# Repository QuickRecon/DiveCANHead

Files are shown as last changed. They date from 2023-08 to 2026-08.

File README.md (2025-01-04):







# Current State
Revision 2.4 has been produced and is undergoing wet testing, current development work is focused on enhansing the automated testing (currently focusing on adding testing of various power states), as well as validating solenoid driver performance.

Constructive criticism, suggestions, and pull requests are always welcome.

Documentation for building and flashing firmware can be found under /Documentation/

# Goals
The goals of this project are pretty simple:
- Have a reliable PPO2 monitor that can handle both digital and analog PPO2 cell inputs
- Be extendable for future CCR technology developments
- Work with existing computers/handsets, accomplished via DiveCAN compatibility.

# DiveCAN
DiveCAN is Shearwaters proprietary digital rebreather communications bus, more details about the electrical and protocol layers are discussed here: https://github.com/QuickRecon/DiveCAN

# The platform
The platform is based on an STM32 processor, connected to a pair of dual differential input ADCs for analog sensing. Digital cells are handled via the 3 UART ports on the STM32.
Power is done in a dual rail configuration, with a critical VCC rail running the main processor, CAN transceiver, and other necessary basic components. This is supplemented with a second VBUS rail used for running external peripherals like solid state sensors.

The board has a battery onboard which can provide full functionality, and can also be provided with power from the CAN bus (1.8-5.5v). The VCC rail will prioritize CAN power and revert to battery if that is unavailable, the VBUS rail can have its power source controlled via the firmware. The VBUS rail can also be fed onto the CAN bus, allowing the board to act as a CAN power source, supplementing the bus power of the shearwater (which tops out at 16 mA).

Fundamentally the hardware is an IO board, bridging generic cells, sensors, and other peripherals to the DiveCAN bus. To do this it provides the following:
- 3 uart ports
- 4 analog differential inputs (3 terminated for O2 cells, 1 unterminated differential input)
- the solenoid output (12v/6v selectable, max 1.3A switching current (LMR62014 boost converter))
- general DC out (3.3v, 227mA current limit)
- the CAN bus itself
- 2 DACs, configured for "cell like" outputs
- 2 GPIOs

Currently there are sensor drivers for analog oxygen cells and digital oxygen cells. Future development.

The board is currently emulating a DiveCAN SOLO board, specifically using data captured from a JJ head, and testing with a JJ Petrel 3. This will almost certainly work with any DiveCAN shearwater expecting the same general architecture (such as the Choptima handset, or NERD/DiveCAN HUD). It will also probably work (may require some small code changes around the IDs used) with rEvo and ISC shearwaters, but that hasn't been validated.

The current form factor is driven by the ease of manufacturing and RnD on the design rather than being fully optimized for widespread implementation. For example the battery has been put on the PCB because that is the easiest place for it to be secured. Wires and connectors are places for assembly defects and failures so I like to avoid them where possible. Having the battery on the PCB means that if the PCB is secure then the battery is secure, and the PCB has mounting holes, which makes securing it easier.

The long thin aspect ratio was driven by the ease of manufacturing of housings, the current form fits into a simple tube, with cables running out each end. One for CCR IO (cells, solenoid, etc) and DiveCAN out the other.

# Roadmap
### Current software jobs
These are required before the firmware can be considered ready for any kind of test diving:
- Fix composition of errors with battery value (currently battery voltage stops updating on other errors)
- Only sample battery voltage while solenoid firing if solenoid enabled

### Additional testing needs
- More automated testing of each module, regression testing and behavior verification.
- Datalog captures from rEvos
- Verification of compatibility with monitor bus devices, ISC.

### Future Hardware Improvements (desired on next board version)
- External watchdog
- CAN IC with lower power

### Future Software Improvements
- Battery reading and power switching 
- Make DiveCAN multi-device safe so we can make multiple menu rows
- Predive "app", show loop pressure and such

### Prospective future developments
- Additional form-factors, shorter, more compact.
- DAC output to analog cell port, allow use of analog backup monitor with digital cells
- Break off battery to separate system, can be isolated physically for flood tolerance.

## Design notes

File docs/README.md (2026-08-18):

# DiveCANHead Documentation Index

This directory contains detailed subsystem documentation for the DiveCANHead firmware project.

## Quick Reference

| Document | Description |
|---|---|
| [UDS_PROTOCOL.md](UDS_PROTOCOL.md) | UDS diagnostic services, session model, NRCs |
| [ISOTP_TRANSPORT.md](ISOTP_TRANSPORT.md) | ISO-TP framing, state machine, TX queue |
| [DATA_IDENTIFIERS.md](DATA_IDENTIFIERS.md) | Complete DID reference (state, cells, settings) |
| [FREERTOS_PATTERNS.md](FREERTOS_PATTERNS.md) | Cooperative scheduling, queues, static allocation |
| [OXYGEN_SENSORS.md](OXYGEN_SENSORS.md) | Sensor drivers, voting algorithm, calibration |
| [CONFIGURATION_SYSTEM.md](CONFIGURATION_SYSTEM.md) | Configuration_t bitfield, persistence |
| [TESTING_ARCHITECTURE.md](TESTING_ARCHITECTURE.md) | DiveCANpy, pytest fixtures, HWShim |
| [HIL_GITHUB_ACTIONS.md](HIL_GITHUB_ACTIONS.md) | Self-hosted GitHub Actions gate for the out-of-tree HIL bench |
| [DIVECAN_BT.md](DIVECAN_BT.md) | Browser JS client, SLIP, UDSClient |
| [TELEMETRY_VIEWER.md](TELEMETRY_VIEWER.md) | Flash-log telemetry viewer + `telemetry_log.py` CLI |
| [FLASHING_FIRMWARE.md](FLASHING_FIRMWARE.md) | SWD flashing via STM32CubeProgrammer |

## External References

- [DiveCAN Protocol](https://github.com/QuickRecon/DiveCAN) - Base protocol documentation
- [ISO 14229 (UDS)](https://www.iso.org/standard/72439.html) - Unified Diagnostic Services specification
- [ISO 15765-2 (ISO-TP)](https://www.iso.org/standard/66574.html) - Transport protocol specification

## Source File Mapping

| Subsystem | Key Source Files |
|---|---|
| UDS | `STM32/Core/Src/DiveCAN/uds/uds.c`, `uds.h` |
| ISO-TP | `STM32/Core/Src/DiveCAN/uds/isotp.c`, `isotp_tx_queue.c` |
| DIDs | `uds_state_did.h`, `uds_settings.c`, `DiveCAN_bt/src/uds/constants.js` |
| FreeRTOS | `STM32/Core/Inc/FreeRTOSConfig.h`, `main.c` |
| Sensors | `Sensors/OxygenCell.c`, `AnalogOxygen.c`, `DiveO2.c`, `OxygenScientific.c` |
| Config | `configuration.h`, `configuration.c`, `ConfigFormat.md` |
| Testing | `DiveCANpy/*.py`, `HW Testing/Tests/*.py` |
| BT Client | `DiveCAN_bt/src/**/*.js` |

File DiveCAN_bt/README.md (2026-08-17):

# DiveCAN Protocol Stack for Browser

A browser-based JavaScript API for communicating with DiveCAN-compatible devices via Bluetooth Low Energy (BLE). Implements the full protocol stack: BLE → SLIP → DiveCAN → ISO-TP → UDS.

## Features

- **Full Protocol Stack**: Complete implementation of BLE-SLIP-ISO-TP-UDS layers
- **Web Bluetooth API**: Native browser support (Chrome, Edge, Opera)
- **Device Discovery**: Scan and connect to Petrel 3 Bluetooth bridge
- **UDS Diagnostics**: Session control, read/write data identifiers, memory transfer
- **Test UI**: Comprehensive web-based testing interface
- **Modular Architecture**: Clean layer separation for easy testing and extension
- **Event-Driven**: Real-time packet inspection and progress tracking

## Browser Support

- ✅ Chrome 56+
- ✅ Edge 79+
- ✅ Opera 43+
- ❌ Firefox (no Web Bluetooth support)
- ❌ Safari (no Web Bluetooth support)

**Requirements:**
- HTTPS (required for Web Bluetooth API)
- User gesture to initiate connection (button click)

## Quick Start

### 1. Start a local HTTPS server

Since Web Bluetooth requires HTTPS, you need to serve the files over HTTPS:

```bash
cd DiveCAN_bt
npm run dev
```

This starts a simple HTTP server on port 8000. For HTTPS, you'll need a local certificate or use a service like ngrok.

### 2. Open the test UI

Navigate to:
```
http://localhost:8000/examples/test-ui.html
```

### 3. Connect to your Petrel 3

1. Click "Scan & Connect"
2. Select your Petrel 3 from the browser's device picker
3. Wait for connection to establish

### 4. Test UDS operations

- Switch diagnostic sessions
- Read firmware version
- Read/write configuration
- Upload memory blocks

## API Usage

### Basic Example

```javascript
import { DiveCANProtocolStack, DeviceManager } from './src/index.js';

// Create device manager
const deviceManager = new DeviceManager();

// Scan for devices
const devices = await deviceManager.scan();
const petrel = devices[0].device;

// Create protocol stack
const stack = new DiveCANProtocolStack();

// Connect
await stack.connect(petrel);

// Read firmware version
const version = await stack.readFirmwareVersion();
console.log('Firmware:', version);

// Disconnect
await stack.disconnect();
```

### Advanced Usage

```javascript
import {
  DiveCANProtocolStack,
  UDSConstants
} from './src/index.js';

const stack = new DiveCANProtocolStack();

// Set up event handlers
stack.on('connected', () => console.log('Connected'));
stack.on('data', ({ layer, data }) => console.log(`RX [${layer}]:`, data));
stack.on('error', (error) => console.error('Error:', error));

// Connect to device
await stack.connect(device);

// Read device settings (individual settings under 0x9xxx)
const settings = await stack.uds.enumerateSettings();
console.log('Settings:', settings);

// Stage + activate a firmware image (see docs/DIVECAN_BT.md)
await stack.ota.enterProgrammingSession();
await stack.ota.stageImage(imageBytes, { onProgress: (d, t) => {} });
await stack.ota.activate();

// Download a flash log
const { raw } = await stack.logs.downloadLog({ selector: (d) => d.selectLatestBoot(0) });

// Download every telemetry record still retained in one walk-free stream.
const { raw: allRaw, records } = await stack.logs.downloadAll({ stream: 0 });
```

### CANable over Web Serial

Chromium can talk directly to a CANable when it is running `slcan`/Lawicel
serial firmware (the candleLight/gs_usb firmware is not a serial protocol and
cannot be used through Web Serial). The adapter is configured for DiveCAN's
125 kbit/s bus by default (`S4`). This direct path performs DiveCAN's padded
ISO-TP variant in the browser; it does not use SLIP or the Petrel bridge.

```javascript
import { CanableProtocolStack } from './src/index.js';

// Defaults: Web Serial line-coding value 115200, CAN 125 kbit/s, dialog client 0xFE,
// broadcast-log client 0xFF, head 0x04.
const stack = new CanableProtocolStack();

// The diagnostics page exposes 115200/1M/2M/3M for benchmarking. It is also
// configurable here. On a native USB CDC ACM CANable this value may be ignored
// by the device rather than controlling a physical UART.
const benchmarkStack = new CanableProtocolStack({ canable: { baudRate: 1000000 } });

stack.on('logMessage', message => console.log('HEAD:', message));
stack.on('error', error => console.error(error));

// Must be called from a user gesture (for example, a button click).
await stack.connect(); // opens Chromium's serial-port chooser

const imageBytes = new Uint8Array(await (await fetch('./firmware.bin')).arrayBuffer());
const result = await stack.ota.updateFirmware(imageBytes, {
  onPhase: phase => console.log('OTA phase:', phase),
  onProgress: (done, total) => console.log(`${done}/${total}`)
});
console.log(result);
```

Direct USB-CAN log downloads request the head's full 253-byte response body;
the 61-byte limit remains the default only for the Petrel BLE bridge. For a
large/full-ring browser download, stream into the Origin Private File System
instead of accumulating the log in the JavaScript heap:

```javascript
import { OPFSLogDownloadStore } from './src/index.js';

const selection = { stream: 0, mode: 'allBoots', id: null };
const resumeKey = JSON.stringify(selection);
const store = await OPFSLogDownloadStore.create({ selection, resumeKey });

const result = await stack.logs.downloadAllResumable({
  stream: 0,
  store,
  resumeKey,
  expectedBytes: 48 * 1024 * 1024,
  onProgress: ({
    saved, transferred, replayed, resumeBytes, rateKiBps, averageKiBps, etaSeconds
  }) => {
    console.log({
      saved, transferred, replayed, resumeBytes,
      rateKiBps, averageKiBps, etaSeconds
    });
  },
  onRetry: ({ nextAttempt, delayMs, partialBytes }) => {
    console.log(`retry ${nextAttempt} in ${delayMs} ms; ${partialBytes} bytes saved`);
  }
});
console.log(await result.store.getFile());
console.log(result.metrics); // final elapsed time, smoothed rate, average rate
```

After a transient failure the selector restarts at byte zero (the protocol has
no offset request). The client verifies the retransmitted bytes against the
saved disk prefix. If a full ring advanced during a head reboot, it can resume
only after finding a unique overlap and verifying continuity through the saved
boundary. Missing, ambiguous, or changed overlap aborts with
`LOG_RESUME_MISMATCH`; the partial file is left untouched for inspection or
export. The diagnostics page lists these complete and partial OPFS artifacts
and provides explicit Inspect, Resume, and Export controls. It displays the
smoothed transfer rate in KiB/s and, for select-all downloads, an ETA to the
48 MiB telemetry or 8 MiB text ring capacity. The final average rate and the
selected Web Serial baud value are retained in the artifact metadata and the
diagnostics message log for comparison between benchmark runs.

Web Serial requires a secure context; `http://localhost` is accepted for local
development. Disconnect any other active CAN controller/diagnostic client
during OTA so only one ISO-TP dialog owns the head.

Direct USB-CAN deliberately uses two independent ISO-TP receive contexts:
addressed OTA/DID replies target client `0xFE`, while pushed logs remain on
`0xFF`. Interleaved log frames therefore cannot alter the dialog reassembly
sequence or complete a pending UDS request. BLE continues to use `0xFF` for
both because the Bluetooth bridge exposes only that single client address.

The CANable stack also watches for the handset's controller `BUS_ID` ping
(`0x0D000001`). If none is observed for 2.5 seconds it supplies the same ping
once per second, allowing a freshly swapped image to pass its handset-liveness
POST when the USB adapter is the only bus peer. Emulation stops immediately
when a real handset ping appears. Set `handsetEmulation: false` to disable it,
or override `handsetMissingAfterMs` / `handsetPingIntervalMs` if required.

### Direct Layer Access

```javascript
// Access individual protocol layers
const ble = stack.ble;           // BLEConnection
const slip = stack.slip;         // SLIPCodec
const divecan = stack.divecan;   // DiveCANFramer
const transport = stack.transport; // DirectTransport (Petrel handles ISO-TP)
const uds = stack.uds;           // UDSClient
const ota = stack.ota;           // OTAManager
const logs = stack.logs;         // LogDownloader

// Direct UDS operations
await uds.enterSession(UDSConstants.UDS_SESSION_PROGRAMMING); // 0x10 0x02
const data = await uds.readDataByIdentifier(0xF000);
await uds.writeDataByIdentifier(0xF240, [130]); // setpoint 1.30 bar
```

## Architecture

### Protocol Layers

```
┌─────────────────────────────────────────────┐
│           Application Layer                  │
│     (UI, Device Manager, Test Harness)       │
└─────────────────────────────────────────────┘
                     ↕
┌─────────────────────────────────────────────┐
│           UDS Service Layer                  │
│  (Session Control, Read/Write, Upload/Down)  │
└─────────────────────────────────────────────┘
                     ↕
┌─────────────────────────────────────────────┐
│         ISO-TP Transport Layer               │
│    (SF/FF/CF/FC Framing, Reassembly)        │
└─────────────────────────────────────────────┘
                     ↕
┌─────────────────────────────────────────────┐
│         DiveCAN Datagram Layer               │
│     (Source/Target Addressing, Framing)      │
└─────────────────────────────────────────────┘
                     ↕
┌─────────────────────────────────────────────┐
│           SLIP Encoding Layer                │
│      (Encoding/Decoding, Escaping)           │
└─────────────────────────────────────────────┘
                     ↕
┌─────────────────────────────────────────────┐
│         BLE Communication Layer              │
│   (Web Bluetooth API, Connection Mgmt)       │
└─────────────────────────────────────────────┘
```

### File Structure

```
DiveCAN_bt/
├── src/
│   ├── ble/
│   │   └── BLEConnection.js         # Web Bluetooth interface
│   ├── slip/
│   │   └── SLIPCodec.js             # SLIP encoding/decoding
│   ├── divecan/
│   │   ├── DiveCANFramer.js         # DiveCAN datagram layer
│   │   └── constants.js
│   ├── isotp/
│   │   ├── ISOTPTransport.js        # ISO-TP transport layer
│   │   ├── ISOTPStateMachine.js     # State machine
│   │   └── constants.js
│   ├── uds/
│   │   ├── UDSClient.js             # UDS service client
│   │   └── constants.js
│   ├── errors/
│   │   └── ProtocolErrors.js        # Error classes
│   ├── utils/
│   │   ├── ByteUtils.js             # Byte array utilities
│   │   ├── Logger.js                # Logging
│   │   └── Timeout.js               # Timeout management
│   ├── DiveCANProtocolStack.js      # Main coordinator
│   ├── DeviceManager.js             # Device discovery
│   └── index.js                     # Public API
├── examples/
│   └── test-ui.html                 # Test interface
├── package.json
└── README.md
```

## Protocol Details

### BLE Layer
- **Service UUID**: `fe25c237-0ece-443c-b0aa-e02033e7029d`
- **Characteristic UUID**: `27b7570b-359e-45a3-91bb-cf7e70049bd2`
- **Packet Header**: `[0x01, 0x00]` prepended to all packets
- **MTU**: 20 bytes (default)

### SLIP Layer
- **RFC 1055** encoding
- **END byte**: `0xC0`
- **ESC byte**: `0xDB`
- Escape sequences: `0xC0 → 0xDB 0xDC`, `0xDB → 0xDB 0xDD`

### DiveCAN Layer
- **Datagram format**: `[source, target, len_low, len_high, payload...]`
- **Source**: `0xFF` (bluetooth client)
- **Target**: `0x80` (controller/Petrel bluetooth side of bridge)

### ISO-TP Layer
- **ISO 15765-2** with extended addressing
- **Single Frame (SF)**: ≤6 bytes, `[TA, 0x0N, payload...]`
- **First Frame (FF)**: >6 bytes, `[TA, 0x1N, len_low, first 5 bytes...]`
- **Consecutive Frame (CF)**: `[TA, 0x2N, 6 bytes...]`
- **Flow Control (FC)**: `[TA, 0x30, BS, STmin]`
- **Timeouts**: N_Bs=1000ms, N_Cr=1000ms

### UDS Layer
- **ISO 14229-1** diagnostic services
- **Service 0x10**: DiagnosticSessionControl
- **Service 0x10**: DiagnosticSessionControl (default / programming)
- **Service 0x22**: ReadDataByIdentifier
- **Service 0x2E**: WriteDataByIdentifier
- **Service 0x31**: RoutineControl (OTA activate, log selectors)
- **Service 0x34**: RequestDownload (OTA + log download)
- **Service 0x36**: TransferData
- **Service 0x37**: RequestTransferExit

### Data Identifiers (DIDs)
- **0xF000**: Firmware version (string)
- **0xF001**: Hardware version (byte)
- **0xF002**: Variant name (string)
- **0xF003**: Serial number (raw MCU UID)
- **0xF270–0xF279**: MCUBoot status / OTA management
- **0xF280–0xF284**: Flash-log stats / selector / management
- **0x9100**: Setting count
- **0x9110+i**: Setting info for setting i
- **0x9130+i**: Setting value for setting i
- **0x9350+i**: Save setting i to flash

## Events

The `DiveCANProtocolStack` emits the following events:

- **`connected`**: Connection established
- **`disconnected`**: Connection closed
- **`data`**: Data received (with layer info)
- **`frame`**: Frame sent (with layer info)
- **`error`**: Protocol error occurred
- **`progress`**: Progress update (current, total, percent)
- **`udsResponse`**: UDS positive response
- **`udsNegativeResponse`**: UDS negative response (with NRC)

## Error Handling

```javascript
try {
  const version = await stack.readFirmwareVersion();
} catch (error) {
  if (error instanceof UDSError) {
    console.error('UDS Error:', error.getNRCDescription());
    console.error('NRC Code:', error.nrc);
  } else if (error instanceof ISOTPError) {
    console.error('ISO-TP Error:', error.message);
  } else if (error instanceof BLEError) {
    console.error('BLE Error:', error.message);
  }

  // Full error chain
  console.error('Full error:', error.getFullError());
}
```

## Development

### Running the Test UI

```bash
# Start HTTP server
npm run dev

# Open browser to http://localhost:8000/examples/test-ui.html
```

### Debugging

Set logger level in your code:

```javascript
import { Logger } from './src/utils/Logger.js';

// Set global log level
Logger.prototype.setLevel('debug');

// Or per-layer
stack.ble.logger.setLevel('debug');
stack.isotp.logger.setLevel('debug');
stack.uds.logger.setLevel('debug');
```

## Limitations

- **Web Bluetooth API**: Only available in Chromium-based browsers
- **HTTPS Required**: Web Bluetooth API requires secure context
- **User Gesture**: Initial connection must be triggered by user action
- **MTU**: Limited to 20 bytes by default (can be negotiated higher)
- **No Background**: Connection drops when tab becomes inactive

## Troubleshooting

### "Web Bluetooth not available"
- Use Chrome, Edge, or Opera browser
- Ensure you're on HTTPS (or localhost)

### "Connection failed"
- Ensure Petrel 3 is powered on and advertising
- Check Bluetooth is enabled on your computer
- Try moving closer to the device

### "Request timeout"
- Device may not be responding
- Check DiveCAN device is functioning
- Try disconnecting and reconnecting

### "Negative response" errors
- **NRC 0x22**: Wrong session - switch to extended/programming session
- **NRC 0x13**: Incorrect message length - check data format
- **NRC 0x31**: Request out of range - invalid DID or address

## Future Enhancements

- Unit tests (Jest)
- TypeScript definitions
- Settings API (read/write via DIDs 0x9100+)
- Firmware download capability
- Log file retrieval
- Connection state persistence
- Multiple device management
- MTU negotiation
- Bundling (Rollup/Webpack)

## License

MIT

## Contributing

Contributions welcome! Please open an issue or pull request on GitHub.

## References

- **ISO 15765-2**: Road vehicles — Diagnostic communication over Controller Area Network (ISO-TP)
- **ISO 14229-1**: Road vehicles — Unified diagnostic services (UDS)
- **RFC 1055**: Serial Line Internet Protocol (SLIP)
- **Web Bluetooth API**: https://webbluetoothcg.github.io/web-bluetooth/

## Support

For issues and questions, please open an issue on GitHub.

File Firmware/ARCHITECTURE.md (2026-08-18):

# Architecture — DiveCAN Jr (Zephyr Port)

This document captures the design decisions made during the port from the FreeRTOS-based STM32 firmware to Zephyr RTOS, targeting the same STM32L431RCTx on the new Jr PCB.

## Motivations for Porting

- **Decouple application logic from driver logic** — FreeRTOS firmware had tight coupling between HAL calls and application code, making testing and hardware changes expensive.
- **MCUBoot / OTA** — Zephyr's native MCUBoot integration enables over-the-air firmware updates via UDS over CAN bus, reducing the barrier to deploying fixes.
- **Compile-time product variants** — Replace the runtime Configuration_t struct with Kconfig-based topology selection. Each product variant is a validated, tested firmware image. Invalid hardware configurations become unrepresentable.
- **No shared global state** — Replace the FreeRTOS peek-queue and global struct patterns with zbus pub/sub for fully decoupled inter-module communication.
- **Hardware-enforced safety** — Hardware timer deadman on solenoids, MPU stack guards, HW RNG-seeded stack canaries.

## Target Hardware

- **MCU**: STM32L431RCTx (Cortex-M4F, 256KB flash, 64KB RAM)
- **Clock**: 12MHz HSE, PLL to 80MHz SYSCLK
- **CAN**: DiveCAN @ 125 kbit/s (CAN1, PB8/PB9)
- **ADC**: Dual ADS1115 on I2C1 (0x48, 0x49) for oxygen cell voltage
- **UARTs**: 3x at 19200 baud for digital oxygen sensors
- **Flash**: Winbond W25Q512JV SPI NOR (64MB) replacing SD card — used for OTA secondary slot, scratch, factory image backup, NVS settings, and data logging
- **Console**: Segger RTT over ST-Link (no UART consumed)

## Flash Partitions

Internal flash (STM32L431RC, 256 KB) is dedicated to MCUBoot + the
primary application slot. All operational storage (secondary slot,
swap scratch, factory image backup, NVS settings, future log space)
lives on the external W25Q512JV NOR.

### Internal flash

| Region | Node | Label | Range | Size |
|---|---|---|---|---|
| Bootloader | `boot_partition` | `mcuboot` | 0x00000000 – 0x00009000 | 36 KB |
| Primary slot | `slot0_partition` | `image-0` | 0x00009000 – 0x00040000 | 220 KB |

MCUBoot is built with `BOOT_SIGNATURE_TYPE_NONE` (SHA-256 integrity
only, no asymmetric crypto). The sysbuild MCUBoot overlay disables
application-only peripherals; the image is approximately 32 KB in a 36 KB
partition. Monitor this narrow margin after Zephyr/MCUBoot upgrades.

### External NOR (W25Q512JV, 64 MB)

| Region | Node | Label | Range | Size |
|---|---|---|---|---|
| Secondary slot | `slot1_partition` | `image-1` | 0x00000000 – 0x00037000 | 220 KB |
| Swap scratch | `scratch_partition` | `image-scratch` | 0x00037000 – 0x00047000 | 64 KB |
| Factory image backup | `factory_partition` | `factory-image` | 0x00047000 – 0x0007E000 | 220 KB |
| Alignment gap | — | — | 0x0007E000 – 0x00080000 | 8 KB |
| Telemetry FCB | `log_telemetry_partition` | `log-telemetry` | 0x00080000 – 0x03080000 | 48 MB |
| Text FCB | `log_text_partition` | `log-text` | 0x03080000 – 0x03880000 | 8 MB |
| Unallocated | — | — | 0x03880000 – 0x03FF8000 | ~7.5 MB |
| NVS settings | `storage_partition` | `storage` | 0x03FF8000 – 0x04000000 | 32 KB |

The log partitions use 256 KiB logical FCB sectors to fit the descriptor
budget. At the measured high-rate capture cadence the 48 MB telemetry ring holds
about 4.9 hours before wrapping. NVS remains at the top of the chip.

The factory partition holds a permanent known-good copy of the
first-confirmed image, captured automatically on first boot after a
fresh flash. UDS DID `0xF276` triggers a restore-from-factory swap
when the running image needs to be force-reverted to the factory
baseline. See the OTA design plan for the full state machine.

## Product Variant System

Hardware topology is defined at compile time via Kconfig, applied through `EXTRA_CONF_FILE=variants/<name>.conf`. Each variant conf specifies:

- **Cell topology**: Count (1-3) and per-cell type (Analog / DiveO2 / O2S)
- **Handset PPO2 compatibility**: Two-cell variants may enable
  `CONFIG_DIVECAN_PPO2_SLOT_3_CONSENSUS` to place consensus in the unused
  third PPO2 broadcast slot. This is an outbound wire transformation only:
  the synthetic slot never becomes a cell, voter, confidence input, or UDS
  state entry, and the all-`0xFF` calibration prompt takes precedence. The
  outgoing `PPO2_STATUS` cell-state bit for that slot is set to included
  (only when a valid consensus is present, not `0xFF`) so the handset
  renders it as a healthy cell instead of highlighting the unused slot as
  excluded; the internal voting inclusion mask is untouched.
- **Power mode**: Battery only, battery+CAN fallback, CAN only
- **Battery chemistry**: 9V alkaline, 1S/2S/3S lithium
- **Solenoid role mapping**: Which physical channel serves which function (O2 inject, O2 flush, dil flush, secondary inject). When a secondary inject is wired, the fire thread alternates fires between the two inject channels. `CONFIG_SOL_FLUSH_TIME` (ms, 0 = off) adds a flush on diver-commanded setpoint changes: O2 flush on an increase, dil flush on a decrease, fired for the configured time at the start of the next fire cycle (BUILD_ASSERT-bounded by the deadman window). In this PPO2-control setpoint-change path only, an O2 flush is suppressed when measured ambient pressure exceeds 2000 mbar (approximately 10 m); the transition is consumed without firing and is not replayed after ascent. Handset-triggered calibration behaviour is unchanged.
- **Runtime defaults**: PPO2 control mode, calibration method, depth compensation

Kconfig `choice` blocks enforce mutual exclusion. `BUILD_ASSERT` in `runtime_settings.c` catches configuration errors at compile time. Derived bools (`HAS_DIGITAL_CELL`, `HAS_O2_SOLENOID`, `HAS_FLUSH_SOLENOID`) gate feature availability.

### Current Variants

| Variant | Description |
|---|---|
| `AP_Aren.conf` | AP-style single-solenoid head — 3× DiveO2, O2 inject on ch0 only, MK15 control, flush cal (via inject solenoid), depth comp; battery-only, 2S Li |
| `AP_Paul.conf` | Copy of `eCCR_classic` with PID control and 1S Li — 3× analog, O2 inject on ch0 only, flush cal (via inject solenoid), depth comp; battery+CAN |
| `eCCR_classic.conf` | Classic single-solenoid eCCR — 3× analog, O2 inject on ch0 only, MK15 control, flush cal (via inject solenoid), depth comp; battery+CAN, 9V |
| `Poseidon_Aren.conf` | 2× DiveO2 head — consensus duplicated into the unused third handset PPO2 slot; all 4 solenoid channels (dual O2 inject alternation, O2/dil flush), PID control, flush cal, depth comp, setpoint-change flush (`CONFIG_SOL_FLUSH_TIME=3000`); battery-only, 1S Li; HP O2/dil tank transducers on the spare adc_ext1 channels (0.3–1.8 V ↔ 0–300 bar, `ADC_GAIN_1` set in the overlay) |
| `Sidewinder_Gabriel.conf` | 3× DiveO2 manual CCR. Intended solenoid and battery topology currently contradict the executable config; resolve before qualification. |

The native_sim integration tests use their own all-features topology in
`tests/integration/integration.conf` (DiveO2/DiveO2/Analog cells — O2S is out
of scope — all 4 solenoid channels, `CONFIG_SOL_FLUSH_TIME=3000`); the former
`variants/dev_full.conf` was folded into it.

## Configuration Split: Compile-Time vs Runtime

| Aspect | Mechanism | When it changes |
|---|---|---|
| Cell types, count | Kconfig | Firmware build |
| Power mode, chemistry | Kconfig | Firmware build |
| Solenoid wiring | Kconfig | Firmware build |
| PPO2 control mode | NVS settings | UDS write at runtime |
| Calibration method | NVS settings | UDS write at runtime |
| Depth compensation | NVS settings | UDS write at runtime |
| PID Kp/Ki/Kd gains | NVS settings | UDS write at runtime |
| Battery chemistry | NVS settings | UDS write at runtime |
| DiveCAN broadcast identity (SOLO/OBOE) | NVS settings | UDS write, **applied on next boot** |

Runtime settings are validated against compile-time tables — e.g., PID mode is only valid if `HAS_O2_SOLENOID` is set. The valid-value tables are const arrays gated by `#ifdef CONFIG_*`, so the compiler eliminates invalid options entirely.

### Boot readiness gating (settings / mode / log selectors)

The UDS server (`divecan_rx`) starts at scheduler start, before `main()` has
run any flash work, so early requests used to be answered from caches still
holding compile-time defaults. The 2026-08-01 HIL release run showed all
three consequences on hardware: settings reads returning variant defaults
("NVS persistence broken"), a 0xF242 solenoid override accepted because the
control mode still read its static OFF default, and log selectors resolving a
ring the current boot had not stamped yet. Three gates now close the window,
each answering NRC 0x21 (busyRepeatRequest) so clients poll instead of
consuming a wrong answer:

- **Settings-value DIDs** (`0x9130+N` R/W, `0x9350+N` W) gate on
  `runtime_settings_is_loaded()`. The load itself is now idempotent (only the
  first call touches NVS) and runs as the first flash operation in `main()`,
  so the window is tens of milliseconds; the boot preamble reads the cache
  instead of re-loading (the old re-load re-zeroed the cache mid-boot).
- **Solenoid override 0xF242** gates on `ppo2_control_mode_latched()` — the
  boot-latched mode is only trusted once `ppo2_control_init()` has read it
  from NVS.
- **Index-backed flash-log selectors** (RoutineControl, except Select-All)
  gate on `flash_log_boot_marker_flushed()` so a selector racing
  `flash_log_init` (or the boot-time recovery erase) can never publish a
  terminal "no data" for a healthy head.

Additionally the log-index walk releases/re-acquires the shared external-
flash mutex every 256 entries (`FL_INDEX_WALK_YIELD_MS`): a full-ring walk
measures 24–63 s, and holding the mutex throughout starved `divecan_rx` of
ISO-TP flow control — observed as OTA 0x34 requests receiving no response at
all.

### Calibration coefficient boot-load (`cal` subtree)

There is **no global `settings_load()`** in this firmware — each subsystem
explicitly loads only its own subtree (`runtime_settings_load` loads `"rt"`,
`flash_log` loads `"log"`, `error_histogram` loads `"errhist"`). The Zephyr
settings subsystem never auto-replays stored values, so any subtree without an
explicit boot-time load stays at its cache default. The `"cal"` subtree
(per-cell coefficients `cal/cellN`) had this gap: it was only ever loaded as a
side effect of the read-back inside a *save*, so on a fresh boot the coefficient
cache stayed zero and every cell's `*_load_cal()` read a default. Analog cells
(no other cal source) then reported `CELL_NEED_CAL` — a field-observed
"calibration doesn't persist across reboots" on the analog `AP_Paul` variant,
while digital cells masked it by falling back to their factory default.

The store now owns an explicit `calibration_load_coefficients()`
(`calibration_store.c`) that loads the `"cal"` subtree into the cache exactly
once (mutex-guarded load-once). The cell drivers call it at the top of their
`*_load_cal()` — the load has to be **consumer-driven** because the cell
threads auto-start (`K_THREAD_DEFINE`) and run `*_load_cal()` during
`main()`'s `boot_indicator()`, before `calibration_init()`; init ordering
alone cannot win that race, but a load-once call from the reader itself always
populates the cache before the read. Regression coverage:
`tests/integration/harness/test_calibration.py::test_cal_persists_across_reboot`
(calibrate → relaunch native_sim preserving flash → assert the analog cell is
not `0xFF`).

1. **Devicetree binding** (`quickrecon,solenoid-driver`): Declares GPIO pins, counter peripheral, and max-on-time-us. Hardware description only.

2. **Driver** (`drivers/solenoid/`): Zephyr device driver using `DEVICE_DT_INST_DEFINE`. Manages GPIO outputs and TIM7 hardware counter. The counter ISR (deadman) forces all outputs low regardless of application state — hardware-enforced safety that the application cannot override.

3. **Role mapping** (`solenoid_roles.h`): `static inline` wrappers that map Kconfig role names (e.g., `sol_o2_inject_fire` / `sol_o2_inject_off`, plus `_2`, `o2_flush`, and `dil_flush` variants) to physical driver channels. Roles not present on a variant (`channel = -1`) compile to `-ENODEV` returns (fire) or no-ops (off).

### Closed-loop solenoid current check

Gated by `CONFIG_SOLENOID_CURRENT_CHECK` (**default n — opt-in**). Enable it only
on a variant that registers a current provider and set the measured window in
that variant's conf (`Poseidon_Aren.conf` enables the check with a 150–250 mA
window; the Kconfig defaults are a wide-open placeholder that never faults). A
board with no provider gains nothing from the check, so the global default is
off. The driver snapshots the
whole-device current just before energising a channel and again at the end of
its on-window, classifies the delta against `CONFIG_SOLENOID_CURRENT_DELTA_{MIN,MAX}_UA`
(`solenoid_current_classify()`, a pure host-testable function in
`drivers/solenoid/solenoid_current.c`), and raises
`OP_ERR_SOLENOID_{OVER,UNDER}CURRENT` on the **first** out-of-window fire (no
debounce — the verdict latches on the edge into a fault and clears on the next
nominal reading).

Because a whole-pack gauge's current reading lags the fire by seconds (DS2782
conversion + solicited I2C round-trip) — far longer than an on-window — judgment
is **not** tied to the fire's close instant. Instead `sol_current_begin` opens a
per-channel **judge window** (`on_time + SOL_JUDGE_MARGIN_MS`) and kicks
`device_current_trigger()`; `solenoid_current_service()`, called periodically
from thread context, samples the gauge across the window and tracks the **peak**
draw. It trips OVER as soon as the peak clears the range, and at the deadline
classifies the peak−baseline delta (below min → UNDER, else NORM). This absorbs
the phase delay; a fully-missed short plateau just reads inconclusive (a genuinely
failing solenoid fires longer/again and is caught). Window state is spinlock-
guarded — a manual override (0xF242) arms from the CANTask while the fire thread
services.

The service is driven from the solenoid fire thread: mid-phase in the PID/MK15
sleep loops (~1.5–2 s), and — crucially for HIL — in **OFF mode the fire thread
no longer suspends** but runs a ~250 ms service loop, so manual override fires
(which require OFF mode) are still judged. The verdict is **not** pushed anywhere by
the driver — it is exposed through a pollable API (`solenoid_current_poll()` for
the latest per-channel reading, `solenoid_current_aggregate()` for the
worst-case verdict). The PPO2 control fire thread polls it once per cycle,
flash-logs fresh readings (`FL_TYPE_SOLENOID_CURRENT`), and republishes the
aggregate onto `chan_solenoid_status` (forwarded to the handset by `RespPing`).
This keeps the DT driver free of DiveCAN/zbus/flash-log dependencies.

Current comes from the **generic device-current API** (`device_current.h`,
`src/device_current.c`): a single registered provider reports whole-device
current in **microamps, positive = draw**. The Poseidon variant registers a
provider backed by the battery's DS2782 gauge, converting counts to µA via
`CONFIG_POSEIDON_DS2782_SHUNT_UOHM` (bench-calibrated) and negating the
discharge-negative reading. Boards with an on-board solenoid/rail shunt register
an ADC-backed provider instead; with no provider registered the driver sees no
sample and every channel reports `SOL_CURRENT_NORM`. Confounding of the
whole-device gauge by other loads the head drives (e.g. the Poseidon beeper) is
deferred to bench characterisation.

The battery only *broadcasts* current (CMD 0x06) **on-change**, so a steady load
produces no traffic and the reading would go stale. The accessories thread
therefore **actively solicits** it: when no fresh current sample has landed
within `CURRENT_SOLICIT_STALE_MS` (500 ms), it issues a generic DS2782 register
read (CMD 0x5A, register 0x0E) to the battery once per window; `target_stop`
ingests the reply (`record_current_counts()`). The live value is also exposed to
the BT diagnostics client as read-only DID `0xF237` (see
`docs/DATA_IDENTIFIERS.md`), independent of the solenoid check.

## Error Handling (Four Tiers)

### Tier 0: BUILD_ASSERT — Compile-time invariants
Topology validation, struct size guards, configuration consistency. Errors caught before any code runs.

### Tier 1: __ASSERT — Programming invariants
Zephyr built-in assertions. Enabled in production (`CONFIG_ASSERT=y`) — a controlled reboot is safer than undefined behavior in a life-support system. Triggers `k_oops()` which routes through the fatal handler to reboot.

### Tier 2: MUST_SUCCEED(expr) — Init-time fatal check
ESP_ERROR_CHECK-style macro for kernel/driver API calls that must not fail. Logs the expression, return code, and source location via `printk`, then triggers `k_oops()`. Never compiles out.

### Tier 3: OP_ERROR / OP_ERROR_DETAIL — Operational errors
Non-fatal runtime errors published to a zbus channel (`chan_error`). The `LOG_ERR` in the macro uses the caller's log module for attribution. Subscribers (DiveCAN status composer, flash logger, etc.) react independently. System continues operating with graceful degradation.

### Tier 4: FATAL_OP_ERROR — Fatal operational errors
Unrecoverable runtime conditions. Persists error info to noinit RAM and reboots.
On the next boot, `boot_history_init()` runs before the large FCB mounts,
appends the recovered snapshot to the independent `bootdiag/crashes` NVS ring,
and acknowledges the noinit slot only after that write succeeds. A failed NVS
write therefore leaves the RAM evidence available for another boot. The current
snapshot remains exposed through `0xF250`–`0xF254`; DID `0xF255` exposes the
five-entry persistent crash ring newest-first.

Every startup also reads and clears the Zephyr `hwinfo` reset flags and appends
them to the independent `bootdiag/reboots` five-entry ring, exposed by DID
`0xF256`. Both wire histories carry a monotonic reboot sequence so a crash can
be correlated with its recovering reboot. Once the text FCB is mounted, a
recovered crash is emitted again as `LOG_ERR`, giving the post-mortem both a
small dedicated rolling store and a normal downloadable `LOG_TEXT` record.

### Fatal Error Handler
Overrides Zephyr's `k_sys_fatal_error_handler` (weak symbol). All fatal paths — CPU exceptions, stack canary corruption, `k_oops()`, `k_panic()` — route here. The handler:
1. Writes crash context (reason, PC, LR, CFSR) to `__noinit` RAM
2. Prints directly to RTT and briefly spins for drain (the log backend is not
   re-entered from fault context)
3. Reboots (`sys_reboot(SYS_REBOOT_COLD)`)

The system always reboots on fatal error — never halts. Transient faults may self-resolve on restart.

## State Machine Framework (SMF)

Subsystems with multi-step lifecycles (one accepted request walks
through several discrete stages) use Zephyr's State Machine Framework
(`<zephyr/smf.h>`) so each state, the work that runs in it, and the
transitions between them are obvious from one read of the source.

- **Flat-only** — `CONFIG_SMF_ANCESTOR_SUPPORT` and
  `CONFIG_SMF_INITIAL_TRANSITION` stay off. No hierarchical states, no
  initial-substate descent. Keeps the framework code small and the
  control flow boring.
- **One state table per module**, indexed by an enum. Entry / run / exit
  function pointers per state, plus an `SMF_CTX` typedef whose first
  member is `struct smf_ctx smf;` (the cast contract).
- **Test hooks** (`<module>_run_for_test`) under `#ifdef CONFIG_ZTEST`
  drive the SM synchronously; production paths go through the
  module's thread or its caller.

See `docs/STATE_MACHINES.md` for the per-module state tables and event
vocabularies. Currently active: calibration (`src/calibration.c`),
POST gate (`src/firmware_confirm.c`), UDS OTA pipeline
(`src/divecan/uds/uds_ota.c`), ISO-TP RX (`src/divecan/isotp.c`), and
ISO-TP TX queue (`src/divecan/isotp_tx_queue.c`).

## IPC: zbus

Replaces the FreeRTOS 1-element peek queue pattern (`xQueueOverwrite`/`xQueuePeek`). zbus channels hold the latest published value; subscribers get notified on change. ISR-safe, statically allocated, no shared global state.

Defined channels:

| Channel | Type | Publisher | Subscribers |
|---|---|---|---|
| `chan_error` | `ErrorEvent_t` | Any module via `OP_ERROR` | Flash log listener |
| `chan_cell_1` | `OxygenCellMsg_t` | Cell 1 thread | Consensus subscriber, UDS state DID |
| `chan_cell_2` | `OxygenCellMsg_t` | Cell 2 thread | Consensus subscriber, UDS state DID |
| `chan_cell_3` | `OxygenCellMsg_t` | Cell 3 thread | Consensus subscriber, UDS state DID |
| `chan_consensus` | `ConsensusMsg_t` | Consensus subscriber | PPO2 TX, PPO2 PID controller, PID autotune, UDS state DID |
| `chan_cal_request` | `CalRequest_t` | DiveCAN RX, UDS write | Calibration listener |
| `chan_cal_response` | `CalResponse_t` | Calibration thread | DiveCAN cal response listener |
| `chan_battery_status` | `BatteryStatus_t` | Battery monitor thread | DiveCAN ping response |
| `chan_setpoint` | `PPO2_t` | DiveCAN RX, UDS write, handset-loss failsafe, PID autotune | PPO2 PID controller, DiveCAN ping |
| `chan_setpoint_cmd` | `PPO2_t` | DiveCAN RX, UDS write (diver-commanded only — the failsafe does NOT publish here) | Solenoid fire thread (setpoint-change flush trigger) |
| `chan_atmos_pressure` | `uint16_t` | DiveCAN RX | UDS cal trigger, PPO2 PID controller (depth comp) |
| `chan_shutdown_request` | `bool` | DiveCAN RX (BUS_OFF) | Future power management |
| `chan_dive_state` | `DiveState_t` | DiveCAN RX (DIVING msg) | Flash log listener (emits DIVE_START/DIVE_END markers) |
| `chan_duty_cycle` | `Numeric_t` | PPO2 PID controller | Solenoid fire thread |
| `chan_solenoid_status` | `DiveCANError_t` | PPO2 PID controller | DiveCAN RespPing (OR-combined into status byte) |
| `chan_solenoid_fire` | `SolenoidFireEvent_t` | PPO2 solenoid fire thread (kind 0/1 = inject start/end, 2/3 = flush start/end) | Flash log listener (FL_TYPE_SOLENOID_FIRE) — `CONFIG_FLASH_LOG` only |
| `chan_tank_pressure` | `TankPressureMsg_t` | Tank pressure sampler thread | DiveCAN PPO2 TX (TANK_PRESSURE_ID frames) — `CONFIG_HAS_PRESSURE_TRANSDUCER` only |

`chan_cell_2` and `chan_cell_3` are conditionally compiled based on `CONFIG_CELL_COUNT`.

## Flash Log Subsystem

When `CONFIG_FLASH_LOG=y`, a pair of FCB instances on the external SPI
NOR captures a persistent dive log retrievable via UDS. Two streams:
**telemetry** (structured records — consensus, cell raw samples, PID
snapshots, solenoid fire events, errors) and **text** (Zephyr LOG_x
output captured via a custom log backend). Boot and dive markers are
mirrored across both.

A single writer thread (priority 9, below all safety-critical control
threads) serves both FCBs from a unified ingest queue; producers
enqueue with `K_NO_WAIT` and never block or recurse into LOG_x. The
writer is paused around OTA / factory-restore flash operations that
contend for the SPI bus.

**Log-download resolve worker.** The UDS log-download selectors that need the
per-sector marker index (`0xF101`–`0xF104`) resolve on a dedicated
lower-priority thread (`fl_resolve_worker_tid`, priority 10, in
`uds_log_download.c`) rather than inline on the DiveCAN RX thread (priority 5).
The first selection after boot builds the index with a full-ring `fcb_walk`
that takes many seconds; running it inline would stall the CAN bus and blow the
client's response timeout. Instead the selector kicks the worker and answers
NRC 0x21 (busyRepeatRequest) until it publishes, and the client re-polls the
identical selector. The walk-free "select all" (`0xF106`) needs no index and
stays synchronous. The worker pins the shared maintenance arena
(`maint_arena_log_index_set_building`) so a concurrent exclusive tenant
(OTA/FACTORY/AUTOTUNE) cannot evict — and overwrite — the arena mid-build; that
tenant is briefly denied (`-EBUSY`) and retries. This module is the **only**
consumer of the reader's index state, so routing every index-backed resolve
through the single worker means no cross-thread lock is needed inside the
reader. See COMPROMISE.md for the arena-pin trade-off.

Full subsystem details — partition map, on-flash TLV format, recovery
semantics, UDS download protocol — live in `docs/FLASH_LOG.md`.

## Power Management

### DTS-driven topology

The power subsystem uses a custom DT binding (`quickrecon,power-subsystem`) that describes the board's power architecture. Required properties specify the VBUS regulator and battery voltage ADC. Optional properties describe Rev2-specific features (bus-select mux, dual source indicators, VBUS/CAN voltage sensing).

VBUS is modeled as a `regulator-fixed` device — the idiomatic Zephyr way to represent a power rail with an enable GPIO. Application code uses `regulator_enable()` / `regulator_disable()` through the standard API.

### Jr power topology

- **Single power source**: Battery only
- **VCC**: Always on, powers MCU
- **VBUS**: Powers everything else (ADCs, CAN, UARTs, SPI flash). Controlled via `regulator-fixed` with `battery_en` (PA1) as the enable GPIO
- **Voltage monitoring**:
  - Battery voltage via ADC1 channel 4 (PC3) through a 7.25x external resistor divider — reads the unregulated battery rail.
  - VCC (= VBUS, shared regulator) via the STM32 internal VBAT sensor on ADC1 channel 18, which applies the chip's internal 1/3 divider. Wired into the `power-subsystem` node via `vcc-sense = <&vbat>;` and consumed through the Zephyr sensor API (`SENSOR_CHAN_VOLTAGE`) so the divider is handled by the upstream driver.
- **On Jr, VBUS == VCC** physically because they share the regulator. `power_get_vbus_voltage()` and `power_get_vcc_voltage()` therefore both read the VBAT sensor on this board; the Rev2 driver path will read a dedicated VBUS ADC channel once implemented.

### Battery monitoring

A dedicated thread samples battery voltage every 2 seconds and publishes `BatteryStatus_t` to `chan_battery_status` (voltage, threshold, low_battery flag). When flash logging is enabled, the same thread records a combined power snapshot containing the available VBUS, VCC, battery and CAN voltages, whole-device current, and Poseidon gauge percentage. The low-battery threshold is **runtime-configurable**: the `BATTERY_CHEMISTRY_*` Kconfig is the boot default, but the active value comes from `RuntimeSettings_t.batteryType` (NVS-persisted under `rt/bat`, exposed as UDS settings index 7 — `9V` / `Li 1S` / `Li 2S` / `Li 3S`). The thread re-reads the threshold every iteration so a runtime change takes effect within one sample interval.

Per design decision, **low-battery does not auto-trigger shutdown** — the warning is published to zbus and logged; the dive computer / surface tooling chooses the response.

### Shutdown

After a CAN_EN low-power wake, the firmware waits one second and confirms that the line is still externally active before beginning the normal boot sequence. If not, `power_shutdown()` runs — this guards against transient piezoelectric/capacitive wake glitches ("blip on in the dead of night"). Other reset sources begin boot immediately.

`power_shutdown()` enters STM32 SHUTDOWN mode via direct HAL calls (`HAL_PWREx_EnterSHUTDOWNMode()`), draws < 1 µA, and arms `PWR_WAKEUP_PIN2_LOW` (PC13 = CAN_EN, active-low). When CAN traffic re-asserts CAN_EN low, the wakeup is a low-power reset — execution restarts at the reset vector. Only that `RESET_LOW_POWER_WAKE` path runs the legacy one-second anti-piezo validation: CAN_EN is temporarily pulled high and must still be held low externally. POR, BOR, watchdog/crash, software, pin, and unknown resets bypass the test. Zephyr's STM32L4 PM layer doesn't expose SHUTDOWN, so the HAL is called directly (see COMPROMISE.md).

After the wake validation passes (or is bypassed for a non-wake reset), the firmware drives the shared active-low CAN_EN line low throughout boot and normal operation. A BUS_OFF request releases the head's contribution before the two-second abort window samples the handset's state. If the shutdown is rejected, the head asserts CAN_EN again; if it commits, CAN_EN remains high impedance before the Poseidon accessory shutdown commands and final STM32 SHUTDOWN entry.

### CAN transceiver control and warm-start recovery

The TCAN334 transceiver has two control lines the power subsystem owns: `can-shutdown-gpios` (PC14, SHDN — active-high power-down) and `can-silent-gpios` (PC15, S — active-high listen-only). Both are driven **inactive at init** (transceiver powered, normal mode). Going into shutdown, `power_shutdown()` asserts the silent line, then arms `PWR_PUCRx` pulls (SHDN/S high) so the transceiver stays powered down and quiet through sleep.

Those PWR pull registers live in the always-on VDD domain. Because VCC never drops on this board, **a wake-from-SHUTDOWN does not reset them** — unlike a cold power-on. Left applied, the retained pull-up on the silent line (PC15) overrides the TCAN334's internal pull-down and holds the transceiver in listen-only: the head boots but can neither ACK nor transmit, so the handset shows "no connection". `power_init()` therefore calls `HAL_PWREx_DisablePullUpPullDownConfig()` (plus per-pin clears for PC13/14/15) on every boot to release the latched pulls, and the silent line is a **driven output** rather than a passive input so its state is deterministic on cold and warm starts alike.

### Watchdog

The IWDG is enabled in DTS and fed by `src/watchdog_feeder.c` at priority 14 (lower than every safety-critical thread). The feeder only kicks the watchdog when **every registered thread** in the heartbeat module (`include/heartbeat.h`) has advanced its atomic counter since the previous check — a stalled thread → no feed → SoC reset within the IWDG timeout window (32 s, with a 2 s feed interval giving 16 attempts per window).

#### Boot-time ownership of the IWDG

The IWDG is **shared between MCUBoot and the application**, and the handover
matters:

- MCUBoot arms it at `CONFIG_BOOT_WATCHDOG_TIMEOUT_MS` (8 s,
  `sysbuild/mcuboot.conf`). That programming **survives the chainload** — the
  L4 IWDG sits outside the RCC reset domain and cannot be disabled, only
  re-programmed or fed. The bootloader's window is deliberately tight so a
  wedged bootloader still resets.
- The application therefore boots under the *bootloader's* 8 s window until it
  calls `wdt_setup()`. `main()` calls `watchdog_kick()` as its **first
  statement** to widen the window to `WDT_TIMEOUT_MS` (32 s) before any flash
  work, with further kicks after `runtime_settings_load()` and
  `boot_history_init()`.
- This ordering is load-bearing, not defensive. Poseidon_Aren spends >8 s in
  `main()` on synchronous, non-yielding SPI against the external NOR
  (`runtime_settings_load()`'s NVS walk alone measured 3.5 s; full boot to
  preamble 11.3 s). Without the early kick the head reset-loops every 8 s and
  never reaches the application at all. The feeder *thread* cannot cover this
  gap: it runs at priority 14 while `main` is `CONFIG_MAIN_THREAD_PRIORITY=0`,
  so it never pre-empts `main`, and `main` does not block during polled SPI.
  Raising `WDT_TIMEOUT_MS` alone does nothing, because it only takes effect
  once `wdt_setup()` has run.

`IWDG_SW=1` (software start) is the current option-byte setting; see
COMPROMISE.md #10 for why `IWDG_SW=0` — safer in principle, since it arms the
watchdog from power-up — is not yet enabled, and what remains to be measured
before it can be.

Currently registered slots:

| Slot | Thread | Kick site |
|---|---|---|
| `HEARTBEAT_PPO2_PID` | `ppo2_pid_thread` | top of PID iteration |
| `HEARTBEAT_SOLENOID_FIRE` | `solenoid_fire_thread` | top of fire-cycle iteration |
| `HEARTBEAT_CONSENSUS` | `consensus_thread` | top of consensus loop (bounded 2 s wait) |
| `HEARTBEAT_DIVECAN_RX` | `divecan_rx` | top of RX loop (1 s timeout in msgq_get) |
| `HEARTBEAT_CELL_1..3` | each active cell thread | top of sample iteration |

Slots not registered are ignored — variants without a given thread (e.g. cell 3 unconfigured, no solenoid) skip registration and the feeder doesn't expect a kick from them.

A reset caused by missed feeds surfaces on the next boot through the reboot
history: the IWDG flag becomes `RESET_WATCHDOG` in DID `0xF256`. This is kept
separate from `CRASH_REASON` because a watchdog reset does not necessarily pass
through the fatal handler or leave a noinit crash snapshot.

## Tank Pressure Transducers

Analog HP tank pressure senders (O2 and/or diluent) ride on spare entries of the same `zephyr,user` io-channels list the analog oxygen cells use. `CONFIG_O2_TRANSDUCER_CHANNEL` / `CONFIG_DIL_TRANSDUCER_CHANNEL` pick the channel index per variant (-1 = absent, and the whole subsystem compiles out via the derived `CONFIG_HAS_PRESSURE_TRANSDUCER`); `CONFIG_*_TRANSDUCER_MIN` / `_MAX` give the output voltage (mV) at 0 bar and at full scale, and `CONFIG_*_TRANSDUCER_LIMIT` the full-scale pressure (bar).

Configured senders are also exposed through UDS as `0xF238` (O2) and
`0xF239` (diluent). Their little-endian `uint16` values use the native
decibar resolution (`1234` = 123.4 bar); `0xFFFF` is the sensor-failure
sentinel. A DID is unsupported when its corresponding sender is not fitted.

Design points:

- **Gain comes from DT, not code.** Conversion uses `adc_raw_to_millivolts_dt()` so the variant overlay chooses the ADS1115 PGA range (`ADC_GAIN_1` = ±2.048 V for 0.3–1.8 V senders); the analog cells' hardcoded ±0.256 V constant never applies. The variant overlay must re-enable the owning ADS1115 node and override the channel gain.
- **Out-of-range ⇒ omit periodic broadcast.** Voltages outside [MIN, MAX] (open/shorted sender), ADC errors, and init failures map to `TANK_PRESSURE_FAIL` (0xFFFF) on the internal channel and UDS pressure DIDs. `TANK_PRESSURE_ID` never emits that sentinel: the failed cylinder is omitted so a receiver cannot log it as an unrealistically high pressure, while another healthy cylinder continues reporting. The mapping itself is pure math in `tank_pressure_math.c` (ztest: `tests/tank_pressure_math`).
- **Sampler is display-only, no heartbeat.** The 500 ms sampler thread deliberately doesn't register with the watchdog — a wedged pressure gauge must not reboot the head mid-dive. Instead `divecan_ppo2_tx` suppresses all HP pressure frames when the channel cannot be read or its message is more than 3 s old. The handset owns timeout/error presentation for the absent stream.
- **i2c1 is multi-master on Poseidon.** On `Poseidon_Aren` the transducer ADS1115 shares i2c1 with the Poseidon accessory bus (`poseidon_accessories.c` drives the HUD/battery as master and answers the display as target). An ADS conversion-trigger write racing a Poseidon output frame surfaced as intermittent `-EBUSY` (`OP_ERR_EXT_ADC` detail 0x10). Defence is four layers:
  1. **Serialise and group** — the ADS sampler and Poseidon writer share an unconditional `K_MUTEX`. `refresh_outputs()` reserves it across the complete Poseidon frame group so an ADS conversion cannot be inserted between frames.
  2. **Use quiet windows** — external target STOPs and completed local Poseidon groups timestamp bus activity. The ADS sampler requires SCL/SDA high for 3 ms before starting and adds ±10 ms cadence jitter, avoiding the observed ~1.6 ms Poseidon inter-frame gap and long-term phase lock.
  3. **Backport the upstream controller/target race fix** — the project remains pinned to the documented Zephyr 4.4.1 release and owns `patches/zephyr-i2c-stm32-controller-target-race.patch`, a minimal backport of upstream commits `dd9b1122e10`, `879678acbb9`, and `a1609f6a45a`. An own-address match can therefore preempt a controller START safely instead of reaching `i2c_stm32_target_event()` with no matching target configuration. Zephyr's synchronous controller API still exposes arbitration and several other transfer failures as `-EIO`, so the application retries documented transport errors with exponential, jittered backoff rather than reading driver-private flags.
  4. **Recover by line state** — after retries, `i2c1_bus_recover()` samples the physical lines. Stable-high SCL/SDA means only peripheral state is wedged, so it atomically pulses STM32 I2C1 `CR1.PE` while leaving the target registered and its OAR/interrupt configuration intact. Nine-clock `i2c_recover_bus()` is used only after SCL has remained high and SDA low for 25 ms. Toggling/live traffic is left untouched, and stable SCL-low receives only the PE pulse without driving recovery clocks.
- **Wire format** is `TANK_PRESSURE_ID` (0x0D0B0000) per the DiveCAN spec `Messaging/Pressure.md`: byte 0 designates the cylinder (0x00 O2, 0x10 dil), bytes 1-2 carry decibar big-endian. One frame per configured cylinder every PPO2 broadcast cycle (500 ms) while that cylinder has fresh, valid data; otherwise its frame is omitted.

## DiveCAN Protocol

The DiveCAN subsystem lives in `src/divecan/` and handles all CAN bus communication with the Shearwater dive computer and Bluetooth handset.

### Layer Architecture

```
┌──────────────────────────────────────────────┐
│  UDS Diagnostic Services (0x22, 0x2E)        │
│  State DIDs, Settings DIDs, Log Push         │
│  src/divecan/uds/                            │
├──────────────────────────────────────────────┤
│  ISO-TP Transport (custom, not Zephyr's)     │
│  DiveCAN non-standard padding byte           │
│  Centralized TX queue, Shearwater FC quirk   │
│  src/divecan/isotp.c, isotp_tx_queue.c       │
├──────────────────────────────────────────────┤
│  DiveCAN Messages                            │
│  TX composers + CAN driver send layer        │
│  src/divecan/divecan_tx.c, divecan_send.c    │
├──────────────────────────────────────────────┤
│  Zephyr CAN Driver (bxCAN @ 125 kbit/s)      │
│  DTS: &can1, chosen: zephyr,canbus           │
└──────────────────────────────────────────────┘
```

### Why Custom ISO-TP (Not Zephyr's CONFIG_ISOTP)

DiveCAN uses a non-standard padding byte in Single Frame and First Frame messages that is incompatible with Zephyr's standard ISO 15765-2 implementation. Additionally: Zephyr's ISO-TP is EXPERIMENTAL with known bugs, lacks a centralized TX queue for serialization, and doesn't handle the Shearwater FC broadcast quirk (source=0xFF).

### Threads

| Thread | Stack | Priority | Role |
|---|---|---|---|
| `divecan_rx` | 2048 | 5 | CAN RX dispatch, ISO-TP/UDS processing |
| `divecan_ppo2_tx` | 1024 | 4 | PPO2 broadcast every 500ms (zbus subscriber on `chan_consensus`) |
| `ppo2_pid_thread` | 2048 | 6 | PPO2 PID controller — 100 ms cycle, publishes duty + solenoid status (suspends in OFF / MK15 modes) |
| `solenoid_fire_thread` | 1024 | 6 | Solenoid fire timing — 5 s cycle (PID) or 6 s cycle (MK15); alternates primary/secondary inject when fitted; runs the setpoint-change flush check at each cycle start (`CONFIG_SOL_FLUSH_TIME`) |

### Message Flow

**Inbound (handset → head):** CAN RX callback → `k_msgq` → `divecan_rx` thread → switch dispatch. Commands (setpoint, cal, atmos, shutdown) publish to zbus channels. MENU messages route through ISO-TP → UDS dispatcher.

**Outbound (head → handset):** PPO2 TX thread subscribes to `chan_consensus`, broadcasts cell data every 500ms. Calibration response listener fires on `chan_cal_response`, sends `txCalResponse`. UDS responses go through ISO-TP centralized TX queue.

### Key Design Decisions vs Old Firmware

- **No shared Configuration_t pointer** — all cross-module data flows through zbus channels (B1 fix)
- **Non-blocking shutdown** — BUS_OFF publishes to `chan_shutdown_request` instead of blocking the CAN task for 2 seconds (B5 fix)
- **FO2 validation** — calibration requests validate FO2 ≤ 100 before processing (B3 fix)
- **TX/composer split** — `divecan_send.c` (CAN driver glue) separated from `divecan_tx.c` (protocol byte layout) for testability
- **Pure math extraction** — `divecan_ppo2_math.c` extracted from PPO2 TX thread for testability

## PPO2 Control Loop

Two cooperating threads (`src/ppo2_control.c`): `ppo2_pid_thread` runs the PID
(`pid_update` in the OS-free `src/ppo2_control_math.c`) on a 100 ms cycle,
publishing a duty to `chan_duty_cycle`; `solenoid_fire_thread` consumes that
duty, applies quantisation/depth-compensation/deadman, and drives the O2 inject
solenoid on a 5 s PWM cycle. The integrator stores the **equilibrium duty** —
the steady injection that offsets metabolic O2 consumption. Depth compensation
(`duty /= pressure_mbar/1000` in the fire thread) maps that demand from a molar
quantity to a fire time, so the integrator is **depth-invariant**: it converges
to the same value at every depth (see `docs/OXYGEN_SENSORS.md`).

**Above-setpoint fire gate (one-directional-actuator invariant).** The O2 inject
solenoid can only *add* O2, so there is never a legitimate reason to fire it
while measured PPO2 is at/above setpoint. The PID thread therefore suppresses the
**fire command** (`chan_duty_cycle`) whenever `measurement > setpoint`, on the
PID path only — the autotune path is exempt so it can drive PPO2 across setpoint
to characterise the plant. `pid_update` still runs, so the integrator keeps
unwinding; only the actuation is gated.

This replaced a fragile anti-windup scheme (a hard integral reset that fired only
on a ≥0.20 bar overshoot). That scheme left a long-period windup fault: after a
sustained below-setpoint period the integrator wound up, and a *gentle* overshoot
(< 0.20 bar over setpoint) never tripped the reset — so with the integrator held
high the loop kept injecting O2 well above setpoint for a long time (e.g. a unit
surfaced off the diver). The gate closes this because suppression is keyed on the
physical PPO2-vs-setpoint comparison, not on the integrator's slow unwind, so
unwind speed is decoupled from hyperoxia safety. Regression-covered by
`tests/integration/harness/test_ppo2_control.py::test_wound_integrator_quiet_just_above_setpoint`.

**Diagnostics.** The gate suppresses the *fire command* only. `latest_duty` and
duty DID `0xF210` continue to report the **raw signed pre-clamp PID output**
(may rest negative above setpoint, exceed 1 when saturated), so a wound-up
integrator held off by the gate stays visible (positive duty, solenoid quiet)
rather than masked as a phantom zero. This preserves the documented `0xF210`
contract (`docs/DATA_IDENTIFIERS.md`).

## PID Autotune

An on-device setup routine (`src/ppo2_autotune.c`, gated on the same
`CONFIG_HAS_O2_SOLENOID` as the PID controller — no separate Kconfig) that
dials in the solenoid PID gains (Kp/Ki/Kd) from one physical experiment. It
settles at a fixed setpoint, measures mean PPO2, long-term PPO2 slope, pressure
and mean effective duty across a 60 s aggregate baseline, applies a bounded
5–30% incremental duty pulse for 10 s, then
returns to the measured equilibrium duty and records 30 s of redistribution.
Identification uses `Δu = u-u_b` and drift-corrected `Δy = y-y_0`; process gain
is incremental PPO2 shift divided by delivered effective duty-seconds. The
model retains transport delay, recovery duration and the largest rise/fall
mixing reversal. Conservative IMC rules for an integrating delayed plant derive
PI gains once; Kd remains zero. Metabolic demand is reported as baseline duty
and is not folded into plant gain or persisted as a controller bias.
The paired response traces occupy 640 B in the shared maintenance arena during
the run, keeping them off the autotune thread stack and preventing concurrent
OTA/factory scratch use.

**Thread.** One `K_THREAD_DEFINE` (`autotune_thread`) at **priority 7 — one
below the control threads (6)** so it never preempts the PID or fire loop. It
sleeps until a run is requested and is otherwise inert (on a no-solenoid variant
`ppo2_autotune_start()` returns `-ENOTSUP` and the status reports `IDLE`).

**Interaction with the PID controller (no reboot).** During the experiment the
PID thread retains health checks and heartbeat ownership but publishes a fixed
autotune duty. The fire thread still performs its normal quantisation, depth
compensation, deadman and current monitoring. The identifier records effective
post-quantisation duty. Original gains are restored on abort; synthesized gains
are applied live only after successful identification.

**zbus.** Reads `chan_consensus` (the scored signal) and publishes `chan_setpoint`
**only** — never `chan_setpoint_cmd`, so the setpoint-change flush solenoid is
not triggered by the perturbation. Dive detection for the safety abort comes
through the UDS dive signal (`UDS_IsInDive`).

**Safety model.** Bench/surface-only. A run only starts when **not diving** and
**PPO2 mode is PID** (`ppo2_autotune_start()` enforces this; the `0xF243` DID
handler additionally requires a *programming session* — an arming guard, not a
run-long requirement, since the routine runs autonomously once started). It
self-aborts on: operator request, dive start, cell failure (consensus
`PPO2_FAIL`), or a 2-hour timeout. Dive-start abort is wired **twice** — the
routine's own per-tick check and `UDS_MaintainSession()`, where the same dive
signal that force-downgrades the programming session also calls
`ppo2_autotune_request_abort(AUTOTUNE_ABORT_DIVE)`. Any abort restores the
pre-tune gains. On success the winning gains are applied live and **staged into
the volatile settings cache** (indices 4/5/6) — *not* auto-persisted; the
operator reviews and persists them via the settings-save DID (`0x9350 + N`).

**DID supervision surface.** Control write DID `0xF243`
(`ppo2_autotune_start()` / `_request_abort()`, START/ABORT + magic `0xA7`) and
status read DID `0xF213` (`ppo2_autotune_get_status()`, 74-byte snapshot: state,
derived gains, elapsed, plant model, equilibrium duty/slope, pressure and dose). See
`docs/DATA_IDENTIFIERS.md` and `docs/UDS_PROTOCOL.md`.

**Pure-math split.** Identification and integrating-process gain synthesis live
in OS-free `src/ppo2_autotune_math.c` and are host-tested under
`tests/ppo2_autotune_math/`; the thread/state-machine glue stays thin.

## Hardening

| Mechanism | Config | Layer |
|---|---|---|
| MPU stack guard | `CONFIG_HW_STACK_PROTECTION` | Hardware |
| Stack canaries (HW RNG seed) | `CONFIG_STACK_CANARIES_STRONG` + `CONFIG_ENTROPY_GENERATOR` | Compiler |
| FORTIFY_SOURCE | `CONFIG_FORTIFY_SOURCE_RUN_TIME` | Compiler |
| Assertions in production | `CONFIG_ASSERT=y` | Runtime |
| `-Werror` | `CONFIG_COMPILER_WARNINGS_AS_ERRORS` | Build |
| GCC static analyzer (`-fanalyzer`) | `ZEPHYR_SCA_VARIANT=gcc` in CMakeLists.txt | Build |
| `-fharden-compares`, `-fharden-conditional-branches` | CMakeLists.txt (app only) | Compiler |
| `-ftrivial-auto-var-init=pattern` | CMakeLists.txt (app only) | Compiler |
| `-fstack-clash-protection` | CMakeLists.txt (app only) | Compiler |
| `-Wstack-usage=1305` | CMakeLists.txt (app only) | Compiler |
| Frame pointer | `CONFIG_OVERRIDE_FRAME_POINTER_DEFAULT` | Compiler |
| Solenoid hardware deadman | TIM7 counter ISR | Hardware |
| Watchdog | IWDG | Hardware |

## Build System

Zephyr west workspace. Board definition at `boards/quickrecon/divecan_jr/`. Custom DTS bindings at `dts/bindings/`. Solenoid driver built as an `add_subdirectory` rather than a Zephyr module.

Build command:
```bash
NCS=/home/aren/ncs/toolchains/927563c840
PATH=$NCS/usr/local/bin:$PATH \
LD_LIBRARY_PATH=$NCS/usr/local/lib:$LD_LIBRARY_PATH \
ZEPHYR_SDK_INSTALL_DIR=/opt/zephyr-sdk \
west build -d build -b divecan_jr/stm32l431xx . --sysbuild \
  -- -DBOARD_ROOT=. -DEXTRA_CONF_FILE=variants/Poseidon_Aren.conf \
     -DEXTRA_DTC_OVERLAY_FILE=variants/Poseidon_Aren.overlay
```

### Numbered releases

`VERSION` is the canonical firmware/MCUboot SemVer. `changelog.txt` is the
authoritative source for both the GitHub Release notes and the changelog
included in the downloadable package. CMake writes the resolved version,
full source commit, and hardware topology to `test_manifest.json`; the HIL
release workflow will package binaries only when that manifest matches the
requested version, commit, and variant.

The manually dispatched `.github/workflows/release.yml` workflow runs entirely
on the serialized DiveCAN HIL runner. It requires successful ordinary software
CI for the same immutable commit, then builds, flashes, and runs the full HIL
suite once for each production variant. Only the exact merged full-flash image
and `zephyr.signed.bin` OTA image from those tested build directories are
staged. After all variants pass, the workflow creates one deterministic
all-variant ZIP plus a deterministic ZIP for each variant, checksums all six,
tags the tested commit, and publishes a GitHub Release. See
`docs/RELEASING.md` for the operator procedure and package layout.

## File Layout

```
Firmware/
├── boards/quickrecon/divecan_jr/   Board definition (DTS, defconfig, Kconfig)
├── drivers/solenoid/               Zephyr device driver (DT-driven)
├── dts/bindings/                   Custom DT bindings (solenoid, power-subsystem)
├── include/
│   ├── calibration.h               Calibration public API (init, guard, run-for-test)
│   ├── calibration_store.h         Coefficient persistence: cal/cellN save/load, boot load-once
│   ├── errors.h                    Error handling tiers 2-4, OpError_t enum
│   ├── boot_history.h              Five-entry persisted crash/reboot rings
│   ├── power_management.h          Power API, BatteryStatus_t, voltage thresholds
│   ├── oxygen_cell_channels.h      zbus channel declarations (cell, consensus, cal)
│   ├── oxygen_cell_math.h          Pure math: consensus voting, ADC conversion, cal math
│   ├── oxygen_cell_types.h         Shared types: OxygenCellMsg_t, ConsensusMsg_t, etc.
│   ├── runtime_settings.h          NVS-backed runtime config types
│   ├── solenoid.h                  Driver public API
│   ├── solenoid_roles.h            Kconfig role → driver channel mapping
│   └── tank_pressure.h             HP transducer types, chan_tank_pressure, mapping API
├── src/
│   ├── main.c                      Entry point, heartbeat LED
│   ├── calibration.c               Calibration thread, atomic guard, methods (SMF), rollback
│   ├── calibration_store.c         "cal" settings handler + cache, save/load, boot load-once
│   ├── consensus_subscriber.c      zbus subscriber: cell channels → vote → consensus
│   ├── errors.c                    Fatal handler, zbus channel, crash persistence
│   ├── boot_history.c              Startup NVS persistence + reset-cause capture
│   ├── i2c_bus_lock.c              Shared K_MUTEX serialising STM32 i2c1 masters
│   ├── oxygen_cell_analog.c        Analog cell: ADS1115 ADC read, cal, zbus publish
│   ├── oxygen_cell_channels.c      zbus channel definitions (6 channels)
│   ├── oxygen_cell_diveo2.c        DiveO2 cell: UART async, parse, zbus publish
│   ├── oxygen_cell_math.c          Pure consensus + calibration math (no OS deps)
│   ├── oxygen_cell_o2s.c           O2S cell: UART async half-duplex, parse, zbus publish
│   ├── power_management.c          Power driver: regulator, ADC voltage, shutdown
│   ├── power_math.c                Pure power math (voltage conversion, thresholds)
│   ├── ppo2_autotune.c             On-device PID autotune thread (CONFIG_HAS_O2_SOLENOID)
│   ├── ppo2_autotune_math.c        Incremental plant identification + PI synthesis
│   ├── runtime_settings.c          NVS load/save/validate, topology BUILD_ASSERTs
│   ├── tank_pressure.c             HP transducer sampler thread, zbus publish
│   ├── tank_pressure_math.c        Pure mV → decibar mapping (no OS deps)
│   ├── Kconfig                     Product topology, solenoid roles, runtime defaults
│   └── divecan/                    DiveCAN protocol subsystem
│       ├── include/                Protocol headers (types, TX, ISO-TP, UDS)
│       ├── divecan_send.c          CAN driver glue (init, send, blocking send)
│       ├── divecan_tx.c            Protocol message composers (all tx* functions)
│       ├── divecan_rx.c            CAN RX thread, message dispatch, ISO-TP/UDS
│       ├── divecan_ppo2_tx.c       PPO2 broadcast (zbus subscriber on chan_consensus)
│       ├── divecan_ppo2_math.c     Pure PPO2 broadcast filtering logic
│       ├── divecan_channels.c      zbus channel definitions (setpoint, atmos, etc.)
│       ├── isotp.c                 ISO-TP RX state machine + send API
│       ├── isotp_tx_queue.c        Centralized ISO-TP TX queue (k_msgq)
│       └── uds/
│           ├── uds.c               UDS service dispatcher (0x22, 0x2E)
│           ├── uds_state_did.c     State DID handler (reads zbus channels)
│           ├── uds_settings.c      Settings DID handler (reads NVS)
│           └── uds_log_push.c      Log push to Bluetooth client
├── tests/
│   ├── analog_math/                ADC conversion + PPO2 calculation (17 tests)
│   ├── calibration_math/           Cal coefficient math + bug regressions (20 tests)
│   ├── consensus/                  Voting algorithm + permutations (19 tests)
│   ├── parsers/                    DiveO2 + O2S UART protocol parsing (76 tests)
│   ├── power/                      Voltage math, GPIO mux, regulator, CAN detect (19 tests)
│   ├── isotp/                      ISO-TP RX/TX protocol (19 tests)
│   ├── divecan_tx/                 Message composition byte layout (15 tests)
│   ├── ppo2_broadcast/             PPO2 broadcast filtering logic (8 tests)
│   └── ppo2_autotune_math/         Plant identification + model tuning tests
├── variants/
│   └── <variant>.conf/.overlay     Hardware variants (AP_Aren, AP_Paul,
│                                   eCCR_classic, Poseidon_Aren,
│                                   Sidewinder_Gabriel)
├── scripts/
│   ├── lint_variant.sh             CI lint for duplicate Kconfig choices
│   └── release.py                  Release validation, artifact staging, bundling
├── prj.conf                        Common Zephyr config (hardening, RTT, logging, zbus)
├── VERSION                         Canonical numbered firmware/MCUboot version
├── changelog.txt                   Authoritative release changelog and notes source
├── CMakeLists.txt                  App build, compile flags
├── west.yml                        Workspace manifest
├── ARCHITECTURE.md                 This file
├── COMPROMISE.md                   Relaxed constraints tracker
└── CLAUDE.md                       AI assistant maintenance directives
```

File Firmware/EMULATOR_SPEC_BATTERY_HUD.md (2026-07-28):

# Poseidon MkVI — Battery & HUD Emulator / Test-Stand Spec

**Purpose:** Define the bus-facing behaviour of the **Battery (0x43)** and **HUD (0x40)**
processors precisely enough that a test stand can (a) *emulate* both as I2C slaves and
(b) *assert* that the DUT — which plays the Display/Head master role — drives them
correctly.

This file is self-contained: it does not depend on the other RE docs in this repo.
Everything here is derived from firmware reverse engineering of `battery.bin` /
`hud.bin` plus bus captures. Confidence is flagged per item; treat **Working
hypothesis** / **Unverified** items as configurable, not hard assertions.

> **Roles in the test stand**
> - **DUT** = the device under test. It impersonates the **Display (0x41)** and/or
>   **Head (0x42)** — i.e. it is the *master* that sends heartbeats, commands and
>   telemetry, and the consumer of broadcasts/responses.
> - **Emulator** = this code. It presents two slave devices on the bus: **HUD @ 0x40**
>   and **Battery @ 0x43**. It validates every frame the DUT sends and generates the
>   responses/broadcasts the real silicon would.

---

## 1. Physical layer

| Property | Value | Confidence |
|---|---|---|
| Bus | Standard I2C, multi-master | Proven |
| Bit rate | ~100 kHz (battery TWBR=0x2A @ 8 MHz) | Proven |
| Addressing | 7-bit | Proven |
| Pull-ups | External, value uncharacterised (assume 4.7 kΩ) | Assumption |
| Clock stretching | Battery = hardware TWI (may stretch in ISR); HUD = USI bit-bang slave (timing-sensitive, see §6.4) | Strongly inferred |
| General call (0x00) | Both HUD and Battery match general-call address in addition to their own | Strongly inferred |

The emulator should be tolerant of the DUT clock-stretching, and should itself be
able to stretch (or be configured not to, to test the DUT's NoStretch handling).

---

## 2. Addresses

| 7-bit | SLA+W (write byte) | Device | Emulated here? |
|---|---|---|---|
| 0x40 | **0x80** | HUD | **Yes (slave)** |
| 0x41 | 0x82 | Display | No — this is (one of) the DUT's identities |
| 0x42 | 0x84 | Head | No — this is (one of) the DUT's identities |
| 0x43 | **0x86** | Battery | **Yes (slave)** |

All transactions are **I2C writes**. There are **no I2C read (SLA+R) transactions** on
this bus — a device that needs to "reply" does so by becoming master and *writing* a
response frame back to the requester's address. The emulator must therefore also be
able to act as **master** to deliver Battery responses and the HUD/Battery broadcasts
(§5.2, §6.3).

> If the DUT ever issues a SLA+R to 0x40 or 0x43, that is a **DUT bug** — assert-fail.

---

## 3. Frame format

```
[START] [SLA+W] [CMD] [LEN] [DATA_0 .. DATA_{n-1}] [CRC8] [STOP]
```

| Field | Size | Meaning |
|---|---|---|
| SLA+W | 1 (HW) | `addr << 1`, write bit = 0. Included in CRC. |
| CMD | 1 | Command / message type. |
| LEN | 1 | **Number of bytes remaining after LEN, i.e. `data_count + 1` (the +1 is the CRC byte).** See note. |
| DATA  | 0–6 | Payload. |
| CRC8  | 1 | See §4. |

### ⚠ LEN semantics — resolved

Two interpretations appear in the older notes. **The bus-capture-verified, and the one
the emulator MUST use, is:**

> **LEN = count of all bytes after the LEN field = (number of DATA bytes) + 1 (CRC).**

Worked examples (all capture-verified):
- Heartbeat, 1 data byte (`0x00`) → `LEN = 0x02`.
- Battery voltage `0x57`, 2 data bytes → `LEN = 0x03`.
- Battery percentage `0x26`, 1 data byte → `LEN = 0x02`.

So **`data_count = LEN − 1`**, and the DATA region is bytes `[3 .. 3+LEN-2]`, with the
CRC at byte index `3 + (LEN-1) = LEN + 2`.

(An earlier table in `I2C_PROTOCOL_SPEC.md` §3 stated "LEN = data bytes only". That is
**superseded** — do not use it. The command tables in this file quote LEN the
capture-verified way.)

**Bounds:** Battery dispatcher validates `data_count ≤ 6` (i.e. `LEN ≤ 7`). Max frame on
wire = 9 bytes (SLA+W, CMD, LEN, up to 5 data, CRC) in normal traffic; reject anything
with `LEN > 7` as malformed.

---

## 4. CRC-8

**Proven across all four processors.**

| Param | Value |
|---|---|
| Polynomial | `0x07` (x⁸+x²+x+1) |
| Init | `0x00` |
| Reflect in / out | No / No (MSB-first) |
| Output XOR | None |
| Scope | `[SLA+W, CMD, LEN, DATA_0 .. DATA_{n-1}]` (CRC byte itself excluded) |

A valid frame satisfies `CRC8(SLA+W, CMD, LEN, DATA..., received_CRC) == 0x00`
(running the CRC over the whole frame *including* the CRC yields 0).

```c
// Bitwise reference (HUD/ATtiny84 uses this; Battery uses an equivalent 256-byte LUT).
uint8_t crc8_update(uint8_t crc, uint8_t b) {
    crc ^= b;
    for (int i = 0; i < 8; i++)
        crc = (crc & 0x80) ? (uint8_t)((crc << 1) ^ 0x07) : (uint8_t)(crc << 1);
    return crc;
}
uint8_t crc8_frame(uint8_t sla_w, uint8_t cmd, uint8_t len, const uint8_t *data, uint8_t n) {
    uint8_t c = 0x00;
    c = crc8_update(c, sla_w);
    c = crc8_update(c, cmd);
    c = crc8_update(c, len);
    for (uint8_t i = 0; i < n; i++) c = crc8_update(c, data[i]);
    return c;
}
```

### 4.1 Golden test vectors (use these to self-check the emulator's CRC + framing)

Each line is the **complete on-wire frame** including SLA+W and CRC. Re-running the CRC
over the whole line must yield `0x00`.

| Description | Wire bytes (hex) | CRC |
|---|---|-----|
| Heartbeat → Battery (normal) | `86 00 02 00 6F` | 6F |
| Heartbeat → Battery (shutdown) | `86 00 02 01 68` | 68 |
| Shutdown → HUD | `80 00 02 01 1C` | 1C |
| Shutdown → Head | `84 00 02 01 44` | 44 |
| Battery runtime/alarm init | `86 2D 02 00 BD` | BD |
| Battery speaker control 0 (audible, state-dependent) | `86 0E 02 00 43` | 43 |
| Battery speaker control 1 (high tone, state-dependent) | `86 0E 02 01 44` | 44 |
| Battery speaker control 2 (patterned alarm after init) | `86 0E 02 02 4D` | 4D |
| Battery speaker control 3 (stop/reset active alarm state) | `86 0E 02 03 4A` | 4A |
| Heartbeat → HUD | `80 00 02 00 1B` | 1B |
| HUD vibrator ON | `80 0B 02 00 F7` | F7 |
| HUD vibrator OFF | `80 0B 02 01 F0` | F0 |
| HUD red LED ON | `80 0C 02 00 E1` | E1 |
| HUD red LED OFF | `80 0C 02 01 E6` | E6 |
| Battery buddy LED OFF | `86 0D 02 01 F9` | F9 |
| HUD alarm threshold (1000) | `80 A1 03 03 E8 6A` | 6A |
| HUD sensor state 0xA3 | `80 A3 05 00 64 00 64 9E` | 9E |
| Battery O₂ pressure 0x1E | `86 1E 03 0B B8 74` | 74 |
| Battery DS2782 reg read 0x5A (reg 0x0E) | `86 5A 02 0E E6` | E6 |
| HUD mouthpiece broadcast 0x1D → Battery | `86 1D 02 01 5B` | 5B |
| Battery voltage broadcast 0x57 (4065 mV) | `82 57 03 0F E1 1A` | 1A |
| Battery percentage broadcast 0x26 (90%) | `82 26 02 5A 88` | 88 |

---

## 5. HUD device model (slave @ 0x40 / SLA+W 0x80)

The HUD is **slave-only for everything except the mouthpiece broadcast** (§5.2). It runs
an autonomous alarm watchdog (§5.3). Emulating it means: accept the command set below,
and model the watchdog so the test stand can prove the DUT keeps it fed.

### 5.1 Commands the HUD RECEIVES (DUT → HUD). Emulator validates these.

| CMD | LEN | data_count | Payload | Meaning | Confidence |
|-----|-----|---|---|---|---|
| 0x00 | 0x02 | 1 | `[0x00]` | Heartbeat / watchdog kick (resets the 2-min timer) | Proven |
| 0x0B | 0x02 | 1 | `[0x00]`=ON, `[0x01]`=OFF | Vibrator control | Proven |
| 0x0C | 0x02 | 1 | `[0x00]`=ON, `[0x01]`=OFF | Red LED control (may be brightness) | Proven |
| 0xA0 | 0x05 | 4 | 4 bytes | Alarm state data (format TBD) | Working hyp. |
| 0xA1 | 0x03 | 2 | `[hi, lo]` | 16-bit PO₂ alarm threshold | Working hyp. |
| 0xA3 | 0x05 | 4 | `[s1_hi, s1_lo, s2_hi, s2_lo]` | Dual PO₂ sensor state for autonomous alarm | Strongly inferred |
| 0xFF | ? | ? | — | Seen in boot traffic; no evidence that it is required to initialise the HUD | Unverified semantics |

Behaviour the emulator should model:
- **Any** validly-framed, CRC-good frame addressed to 0x40 (or general call) **resets
  the heartbeat watchdog** — not just CMD 0x00. (The watchdog is fed by reception, see
  §5.3.) The cleanest assertion is still "DUT must send CMD 0x00 periodically", but model
  the reset on any good RX so you don't false-alarm.
- CMD 0x0B / 0x0C: latch a simulated vibrator/LED state the test can read back /
  assert against (used in pre-dive actuator tests).
- Unknown CMD with good CRC: real HUD ignores it. Emulator should **log + ignore**, not
  fault (but you may flag it as "DUT sent unmodelled CMD 0x?? to HUD" for review).

#### 5.1.1 HUD startup requirements

The HUD does **not** use the Battery's external CMD 0x2D arming process. Its reset path
performs the required initialization locally before entering the receive loop:

1. Configure the actuator GPIOs and their inactive output levels.
2. Initialize Timer1, the 125 ms scheduler, state/event storage and timer slots.
3. Initialize the USI/I2C slave and receive queue.
4. Select the reset-cause state-machine event and enter the main loop.

The host should allow the HUD to finish reset, then send a normal heartbeat:
`80 00 02 00 1B`. Continue sending it at the normal approximately 2-second cadence.
There is no prerequisite CMD 0x2D transaction and no proven need to send CMD 0xFF
before CMD 0x0B/0x0C actuator commands. A conservative bench implementation may wait
20–100 ms after power is stable before the first transaction.

Unlike the Battery, the HUD receive parser feeds its 120-second watchdog after every
CRC-good addressed frame. CMD 0x00 remains the recommended explicit heartbeat because
it makes the host's intent and bus diagnostics unambiguous.

### 5.2 The HUD as MASTER — mouthpiece broadcast (emulator generates this)

The HUD is the only thing that emits CMD 0x1D. On a simulated mouthpiece position
change, the emulator (as master) writes to **all three** other addresses:

| CMD | LEN | data_count | Payload | Destinations |
|-----|-----|---|---|---|
| 0x1D | 0x02 | 1 | `[0x00]`=Open-Circuit, `[0x01]`=Closed-Circuit | Display 0x82, Head 0x84, Battery 0x86 |

The test stand should expose a control to inject a mouthpiece change and verify the DUT
(in its Display/Head role) ingests CMD 0x1D and reacts. If the DUT also emulates the
Battery side, note the Battery *also* receives 0x1D (§6.1).

### 5.3 HUD autonomous alarm watchdog — **the key DUT assertion**

- Tick = **125 ms** (Timer1 CompA). Countdown = **960 ticks = 120 s**.
- If no frame is received for **120 seconds**, the HUD **autonomously fires
  vibrator + red-LED alarm** (timer IDs 0x02 and 0x12). **Proven.**
- A received frame reloads the countdown.

**Emulator behaviour:** maintain a 120 s countdown reset on every good RX. If it
expires, raise an emulator event `HUD_WATCHDOG_ALARM` and (optionally) set the
vibrator/LED model active.

**Assertion against the DUT:** in normal operation the DUT MUST send a heartbeat (or any
valid frame) to 0x40 well within 120 s. The real Display does so every ~2 s. Recommend
the test stand **fail** if the inter-frame gap to the HUD exceeds a configurable
threshold (default e.g. 7 s, hard-fail at 120 s). The 120 s figure is deliberately
generous to ride out bus glitches — do not let it lapse mid-dive.

### 5.4 HUD constraints to be aware of when emulating

- ATtiny84-class part: bit-banged USI slave, **8 KB flash**, CRC done bit-by-bit. It is
  more timing-sensitive than the Battery's hardware TWI; if you want fidelity, model a
  modest per-byte processing latency and the possibility of NACKing if hammered.
- GPIOR0 flags (internal): bit0=data ready, bit1=transfer active, bit2=data valid,
  bit4=aux. Not bus-visible; informational only.

---

## 6. Battery device model (slave @ 0x43 / SLA+W 0x86)

Hardware TWI, interrupt-driven, 128-byte RX ring buffer. Acts as **slave** (receives
commands) and **master** (writes responses + periodic broadcasts). The Battery is robust:
**missing dive data never raises an error** (§6.5) — only loss of heartbeat changes
behaviour (§6.2).

### 6.1 Commands the Battery RECEIVES (DUT → Battery). Emulator validates these.

LEN column is on-wire (`data_count + 1`). "→ reply" = the Battery answers by becoming
master and writing the listed CMD back to the requester (normally Display 0x82).

| CMD | LEN | data_count | Payload | Meaning | → Reply | Conf. |
|-----|-----|---|---|---|---|---|
| 0x00 | 0x02 | 1 | `[0x00]`=normal, `[0x01]`=shutdown | Heartbeat (see §6.2) | — | Proven |
| 0x0D | 0x02 | 1 | `[0x00]`=ON,`[0x01]`=OFF | Buddy-light LED | — | Proven |
| 0x0E | 0x02 | 1 | `[0x00..0x03]` state-machine input; after CMD 0x2D initialization, 0x00 is audible, 0x01 is a high tone, 0x02 is the patterned alarm and 0x03 stops/resets the active alarm state | Speaker/beeper control (see §6.2.1) | — | Event mapping and gating proven; acoustic modes bench-derived |
| 0x1D | 0x02 | 1 | `[0x00]`=OC,`[0x01]`=CC | Mouthpiece position (from HUD) | — | Proven |
| 0x1E | 0x03 | 2 | `[hi, lo]` | O₂ cylinder pressure (BE) | — | Strongly inf. |
| 0x1F | 0x03 | 2 | `[hi, lo]` | Diluent cylinder pressure (BE) | — | Strongly inf. |
| 0x26 | 0x02 | 1 | `[pct]` | (also broadcast — see §6.3) | — | Proven |
| 0x27 | 0x02 | 1 | `[param]` | Firmware version request | 0x81 | Working hyp. |
| 0x29 | 0x03 | 2 | telemetry | Telemetry accumulation | — | Working hyp. |
| 0x2C | ? | ? | — | Sets internal flag and queues event 0x17; can conditionally schedule delayed speaker event 0x1B (see §6.2.1) | — | Proven handler/effect; payload and external purpose unknown |
| **0x2D** | **0x02** | **1** | Dummy byte; use `[0x00]` | **One-shot runtime/alarm initialization; queues event 0x07 and makes CMD 0x0E alarm transitions reachable** | status/identity writes to Display 0x41 | **Proven** |
| 0x32 | 0x02 | 1 | `[idx]` | Generic EEPROM read, word at `idx*2`, `idx<0x80` | reply word | Proven |
| 0x3A | ≥0x03 | ≥2 | `[selector][value..]` | EEPROM write (sel 0x01→1B@0x27, sel 0x02→2B@0x2A) | — | Proven |
| 0x3B | 0x02 | 1 | `[selector]` | EEPROM read (sel 0x00→0x26, 0x01→0x27, 0x02→0x2A) | 0x3B `[sel,lo,hi]` | Proven |
| 0x40,0x42,0x44,0x46,0x48,0x4A,0x4C,0x50,0x52,0x96 | var | var | deco frames | Deco data from Head | — | Strongly inf. |
| 0x4D | 0x01 | 0 | — | Read EEPROM 0x2A | 0x4E (2B) | Strongly inf. |
| 0x53 | 0x01 | 0 | — | Read runtime counter | 0x54 (4B) | Strongly inf. |
| 0x57 | — | — | (Battery *generates* this; see §6.3) | Voltage broadcast | — | Proven |
| 0x58 | 0x01 | 0 | — | Read EEPROM 0x34 | 0x59 (2B) | Strongly inf. |
| 0x5A | 0x02 | 1 | `[ds2782_reg]` | **Generic DS2782 register read** | reply 2B | **Proven** |
| 0x5C | 0x03 | 2 | `[reg, val]` | DS2782 register/EEPROM write (auto-commits NV for EEPROM pages) | — | Proven |
| 0x5D | 0x01 | 0 | — | Read 2-byte value | 0x5E (2B) | Working hyp. |
| 0x65 | 0x01 | 0 | — | Learn-cycle init (sets EEPROM 0x2C/0x2E/0x4C = 0xFFFF) | — | Strongly inf. |
| 0x66 | 0x03 | 2 | `[hi, lo]` | O₂ sensor raw millivolts | — | Strongly inf. |
| 0x76 | 0x01 | 0 | — | Read EEPROM 0x3A | 0x77 (4B) | Strongly inf. |
| 0x78 | 0x01 | 0 | — | Read EEPROM 0x38 | 0x79 (2B) | Strongly inf. |
| 0x7E | 0x02 | 1 | `[idx 0x00..0x27]` | Deco compartment write (tissue tension) | — | Strongly inf. |
| 0x80 | 0x04 | 3 | `[idx, hi, lo]` | EEPROM 40-entry table write, `idx<0x28` | — | Proven |
| 0x85 | 0x01 | 0 | — | Task trigger 0x0F | — | Working hyp. |
| 0x8F | 0x05 | 4 | 4 bytes | EEPROM multi-write (runtime snapshot → 0x3A/0x5A) | — | Strongly inf. |
| 0x90 | 0x01 | 0 | — | Clear runtime counter | 0x91 | Strongly inf. |
| 0x97 | 0x01 | 0 | — | Read 1-byte status | 0x98 (1B) | Strongly inf. |
| 0x9D | 0x01 | 0 | — | Clear 2-byte value | 0x9E | Working hyp. |
| **0x2F** | **0x01** | **0** | — | **HARD KILL — service tool only (see §6.7)** | — | Proven |

### 6.2 Heartbeat behaviour (model precisely — it gates battery state)

- **Required:** CMD 0x00 with `data=0x00` must arrive periodically. Real cadence ≈ 2 s.
- A CRC-good CMD 0x00 with `data=0x00` queues internal event **0x15**. Its state-machine
  actions arm/reset timer event **0x13** with a countdown of **960 ticks**.
- The timer tick is **125 ms**, so the Battery heartbeat timeout is
  **960 × 125 ms = 120 seconds**. This is proven from the Timer1 configuration and
  event/action tables.
- **If heartbeats stop:** timer event **0x13** expires and drives the Battery's
  timeout/shutdown state transition. It does **not** start the speaker and does not use
  the immediate TX-flush path described below.
- **Only** CMD 0x00 with `data=0x00` reloads the Battery heartbeat timer. Other valid
  Battery commands are processed but do not substitute for a heartbeat. This differs
  from the HUD, whose watchdog is fed by any good addressed RX.
- **CMD 0x00 with `data=0x01`** = deliberate shutdown signal. It immediately queues
  event **0x14** and `FUN_code_1965` flushes the TX queue. It **does NOT release the PB1
  power-hold** — the battery stays powered until the cell is physically pulled.
  Emulator should model this as "shutdown requested, rail still up".

### 6.2.1 Speaker/beeper control and non-heartbeat tone diagnosis

`FUN_code_0bd5` proves only the mapping from CMD 0x0E payloads to state-machine
events. It does **not** prove four direct audio modes: each event is evaluated against
the Battery's current state, and hardware actions occur only when the corresponding
transition predicates match.

| Data | Internal event | Observed result in tested state | Confidence |
|---|---|---|---|
| 0x00 | 0x1D | Audible mode after alarm initialization; used by captured pre-dive speaker test | Bus/current capture + firmware mapping |
| 0x01 | 0x1C | Single higher-pitched tone after alarm initialization | Bench observation + firmware mapping |
| 0x02 | 0x1F | Patterned alarm after alarm initialization | Bench observation + state-transition/action tables |
| 0x03 | 0x1E | Stops/resets an active alarm state; normally silent | Bench observation + state-transition tables |

Payloads above 0x03 fall through to the same internal event as 0x03 in the real
firmware, but the emulator should continue to flag them as invalid protocol values.

There is one additional, indirect audio path: CMD 0x2C sets `DAT_mem_0243`, queues
event 0x17, and—when its state predicate matches—arms event 0x1B for 48 timer ticks
(about 6 seconds). Event 0x1B can then enter the same speaker-pattern machinery.
The external purpose and normal sender of CMD 0x2C remain unresolved, so the emulator
should log it distinctly rather than treating it as an unknown harmless command.

Internal events 0x1B and 0x20 otherwise sequence the same state machine. The heartbeat
timeout path sets the selector that takes event 0x1B's non-audio branch; deliberate
shutdown, DS2782 status events, startup and TWI recovery also do not select an audio
branch. Because the Battery enables general-call matching, a CRC-good general call
carrying CMD 0x0E or CMD 0x2C can also reach these handlers.

For a persistent or delayed high-pitched bench tone, capture traffic to Battery
address 0x43 and general call from power-up. In particular, look for
`86 0E 02 01 44` and for CMD 0x2C in the preceding seconds. Do not infer the audible
result from the payload alone without also knowing the Battery's current state.

### 6.2.2 Battery startup and alarm arming

The Battery reset state is not alarm-ready. The relevant state tokens start as
`[state0=0x00, state2=0x06, state7=0x10]`, while the normal CMD 0x0E start transitions
require `[0x01, 0x05, 0x10]`.

A normal heartbeat queues event 0x15 and changes state0 to 0x01, but it does **not**
change state2 from 0x06 to 0x05. Consequently, heartbeats alone keep the Battery alive
but do not guarantee that a subsequent alarm command will start the speaker.

CMD 0x2D is the missing one-shot initialization:

1. Its handler checks a one-shot guard. The first accepted CMD 0x2D after reset sets
   that guard; later CMD 0x2D frames are no-ops until the Battery resets.
2. It initializes the DS2782/EEPROM-derived Battery runtime state.
3. It queues state-machine event 0x07. That event changes state2 to 0x05 and leaves or
   changes the other alarm predicates to `state0=0x01, state7=0x10`.
4. It queues one or more master-mode status/identity writes to Display address 0x41.

The RX parser rejects a zero-data CMD 0x2D frame, even though its handler does not use
the payload. Send one dummy byte:

```
86 2D 02 00 BD
```

Recommended host startup:

```
wait for Battery power/reset to settle (20–100 ms)
send 86 00 02 00 6F       # normal heartbeat; starts heartbeat supervision
send 86 2D 02 00 BD       # one-shot runtime/alarm initialization
allow the Battery to perform DS2782/EEPROM work and master-mode replies
continue 86 00 02 00 6F approximately every 2 seconds
only then send CMD 0x0E alarm controls
```

The host should be prepared to act as I2C slave 0x41 and ACK the Battery's response
writes. If it does not consume them, leave the bus idle long enough for the Battery's
bounded retry attempts to finish before sending further commands.

Once an alarm-start event succeeds, state7 changes from idle token 0x10 to active token
0x11. Repeating the same start command while already active does not necessarily
restart its sequencer. Send CMD 0x0E data 0x03 to return it to the idle alarm state
before starting another mode during deterministic bench tests.

### 6.3 Periodic broadcasts the Battery GENERATES (emulator emits as master)

The test stand should drive these out on a timer so the DUT's RX path can be exercised.

| CMD | LEN | data_count | Payload | Cadence | Meaning | Conf. |
|-----|-----|---|---|---|---|---|
| 0x06 | 0x03 | 2 | `[lo, hi]` (LSB first!) | on-change | DS2782 instantaneous current, 16-bit **signed**, **LSB byte first**. Negative = discharging. | Proven |
| 0x26 | 0x02 | 1 | `[pct]` | ~4 s | Battery %, **direct** (0x52=82%, 0x5A=90%) → Display 0x82 | Proven |
| 0x57 | 0x03 | 2 | `[hi, lo]` | ~20 s | Battery voltage, **direct millivolts** (0x0FE1=4065 mV) → HUD/Display/Head | Proven |

> **Byte-order trap:** CMD 0x06 current is **little-endian** (LSB first) while pressures
> (0x1E/0x1F) and voltage (0x57) are **big-endian** (hi first). Don't unify them.

Other Battery→master replies (answers to the read commands in §6.1): 0x3B, 0x4E, 0x54,
0x59, 0x5E, 0x77, 0x79, 0x7B, 0x81, 0x91, 0x98, 0x9E to Display (0x82); 0x4F, 0x51 to
Head (0x84). The emulator only needs to generate the replies for the read commands the
DUT actually exercises — give those realistic, configurable payloads.

### 6.4 DS2782 fuel-gauge model (optional, for current/voltage realism)

CMD 0x5A reads any DS2782 register; 0x5C writes. Useful registers:
- `0x0E/0x0F` CURRENT (signed, 1.5625 µV / Rsense per LSB)
- `0x08/0x09` average current
- `0x0A/0x0B` temperature (`(int16 >> 5) * 0.125 °C`)
- `0x0C/0x0D` voltage
- EEPROM pages `0x20–0x2F`, `0x60–0x7F` (writes auto-commit to NV)

If the test stand wants to assert current draw of DUT-controlled loads, model the
DS2782 CURRENT register and have CMD 0x06 fire when it changes. (Capture baselines:
~−268..−553 counts idle; +519 HUD LED, +1619 buddy LED, +2067 vibrator, +2998..+3760
solenoids, +7919 speaker — sign negative = discharge.)

### 6.5 Battery resilience (don't over-assert)

The Battery stores dive data (0x1E, 0x1F, 0x29, 0x66, 0x7E, deco frames) into RAM and
**raises no error if any of it is missing or never sent.** The emulator must NOT fault
the DUT for omitting these. Only heartbeat loss (§6.2) and CRC/framing errors are real
faults.

### 6.6 Normal low-power shutdown sequence

Normal shutdown uses CMD 0x00 with data 0x01. It is a soft, recoverable low-power
request, distinct from the service-only CMD 0x2F hard cutoff in §6.7.

Before sending the shutdown request, explicitly turn off controllable loads so the
result does not depend on the current actuator/alarm state:

```
80 0B 02 01 F0    # HUD vibrator OFF
80 0C 02 01 E6    # HUD red LED OFF
86 0D 02 01 F9    # Battery buddy LED OFF
86 0E 02 03 4A    # Battery speaker stop/reset
```

Then send the shutdown heartbeat to each powered peer. The Head frame is included for
system firmware even though the emulator described by this document primarily models
the HUD and Battery:

```
80 00 02 01 1C    # HUD shutdown
84 00 02 01 44    # Head shutdown
86 00 02 01 68    # Battery shutdown; send last
```

Wait for each addressed write to be ACKed and completed before sending the next one.
After the Battery frame completes, stop periodic heartbeats and nonessential bus
traffic, then place the controlling firmware in its own lowest-power state or remove
the switched peripheral rails.

Observed firmware effects:

- **HUD:** data 0x01 queues internal event 0x13 and clears its queued-transmission
  state. The interrupt-driven main loop executes `SLEEP` whenever it is idle. There is
  no separate HUD hard-off command.
- **Battery:** data 0x01 queues internal event 0x14 and immediately clears its TX
  queue. Its main loop sleeps while idle, but TWI and PB1 power-hold remain enabled.
  This reduces activity but does not electrically disconnect the pack.
- **Head:** data 0x01 queues internal event 0x29, clears TX and saves final state.

Do **not** implement shutdown by merely stopping normal heartbeats. Without the
explicit shutdown frame, heartbeat loss is a fault: after 120 seconds the HUD can
activate its autonomous LED/vibrator alarm, increasing rather than reducing current.

The emulator should accept the four actuator-off writes followed by the shutdown
frames, suppress normal post-shutdown heartbeat assertions for those devices, and
record a clean `LOW_POWER_SHUTDOWN` result. Any later reset/power-up starts a new
session and requires the startup sequence in §5.1.1 and §6.2.2.

### 6.7 ⚠ CMD 0x2F — must never be issued by the DUT

CMD 0x2F (`LEN=0x01`, no data) is a **hard kill**. On the Battery it saves state, sets
`TWCR=0x80`, **drops the PB1 power-hold pin and halts permanently** — recovery needs a
physical re-seat. On the Head it saves state and halts. Byte-pattern search across all
four field binaries proves **no field firmware ever emits 0x2F** — it is a
factory/service-tool entry point only.

**Assertion:** if the DUT ever sends CMD 0x2F to 0x40 or 0x43, the emulator must
**hard-fail the test** (and obviously not "die"). This is the single most dangerous
command on the bus.

---

## 7. Assertions the emulator should enforce against the DUT

Group these so the test stand can report precisely which contract the DUT broke.

### 7.1 Framing / integrity (every frame)
1. **CRC valid** — recompute over `[SLA+W,CMD,LEN,DATA...]`; mismatch → `FAIL: bad CRC`.
   (Real silicon silently discards; the test stand should *flag* it, since a correct DUT
   never emits a bad CRC.)
2. **LEN sane** — `1 ≤ LEN ≤ 7`; DATA length on the wire matches `LEN−1`; STOP lands
   where LEN predicts. Otherwise `FAIL: malformed LEN`.
3. **Known CMD for that address** — CMD is in the receiving device's table (§5.1/§6.1).
   Unknown but well-framed → `WARN: unmodelled CMD` (configurable to fail).
4. **No SLA+R** to 0x40/0x43 → `FAIL: unexpected read transaction`.

### 7.2 Per-command payload checks
- CMD 0x00 data ∈ {0x00, 0x01}.
- CMD 0x0B/0x0C/0x0D data ∈ {0x00, 0x01}.
- CMD 0x0E data ∈ {0x00..0x03}.
- CMD 0x2C is recognized and logged as a delayed-state/speaker trigger; its payload
  format is unresolved, so do not impose a payload assertion yet.
- CMD 0x2D must have `LEN=0x02` and one dummy data byte; use data 0x00.
- CMD 0x1D data ∈ {0x00, 0x01}.
- CMD 0x7E / 0x80 index ≤ 0x27.
- CMD 0x3A selector ∈ {0x01, 0x02} to have effect (0x00/other = no-op, not an error).
- CMD 0x2F to either device → **hard fail** (§6.7).
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

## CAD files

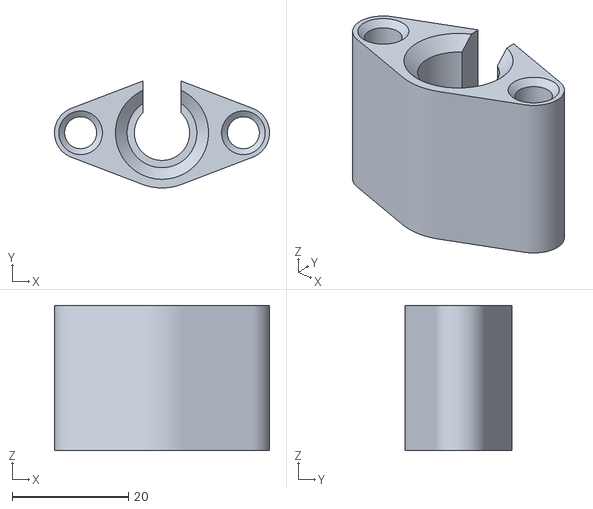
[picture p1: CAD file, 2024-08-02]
CAD/DiveCAN Retainer.stl
37.0 x 18.4 x 25.0

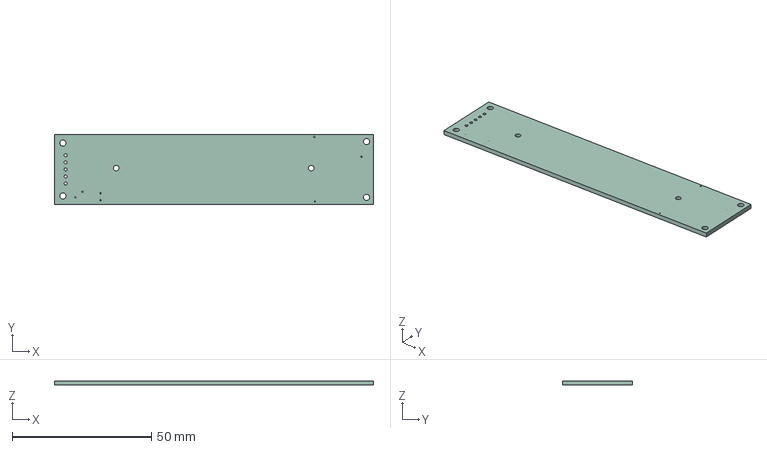
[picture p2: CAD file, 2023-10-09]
DiveCAN Head2.step
114.5 x 25.0 x 1.58 mm

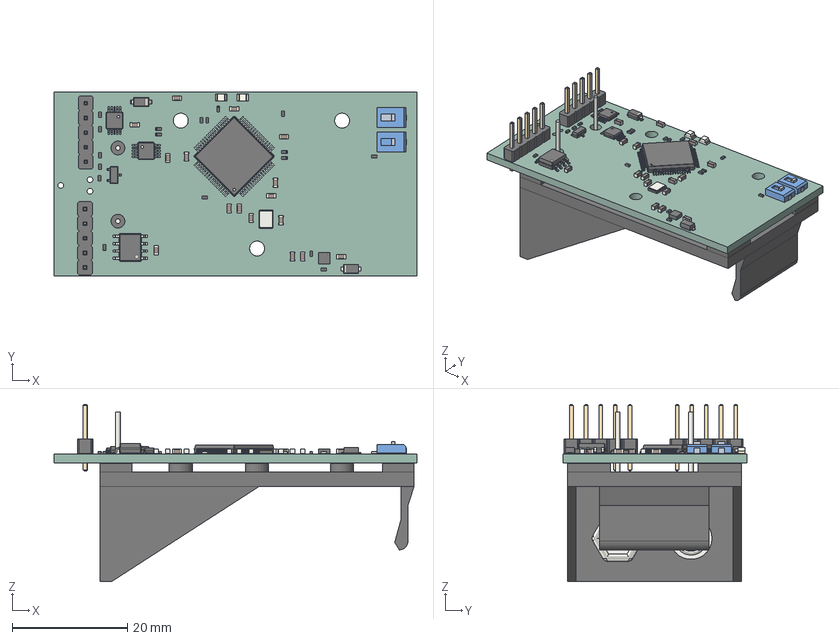
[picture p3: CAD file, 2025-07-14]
EDA/Jr PCB/Jr DiveCAN Head.step
63.0 x 32.0 x 30.7 mm
R_0402_1005Metric x 18
D_SOD_123
TSSOP_10_3x3mm_P05mm x 2
C_0603_1608Metric x 16
PinHeader_1x05_P254mm_Vertical x 2
LED_0805_2012Metric x 2
D_SOD_123F
SOIC_8_39x49mm_P127mm
Crystal_SMD_3225-4Pin_3.2x2.5mm
WSON_6_1EP_2x2mm_P065mm_EP1x16mm
LQFP_64_10x10mm_P05mm
SOT_23
ASSEMBLY x 2
Part_BatteryHolder_Eagle_12BH611_cp
Jr DiveCANHead_PCB

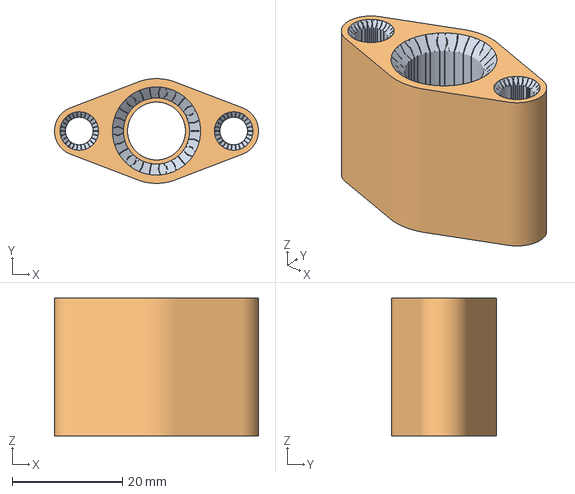
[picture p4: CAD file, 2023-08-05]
CAD/Cable Retainer.FCStd
37.0 x 19.0 x 25.0 mm
Chamfer002 (Meshed)

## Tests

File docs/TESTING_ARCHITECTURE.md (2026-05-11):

# Testing Architecture

This document describes the testing infrastructure including DiveCANpy, pytest fixtures, and hardware integration testing.

## Overview

The project uses two testing approaches:
1. **Unit Tests** - CppUTest framework for isolated module testing
2. **Hardware Tests** - pytest with real hardware for integration testing

## Source Files

- `STM32/Tests/` - Unit tests (CppUTest)
- `HW Testing/Tests/` - Hardware integration tests (pytest)
- `DiveCANpy/` - Python DiveCAN interface library

## DiveCANpy Library

Python library for communicating with DUT over CAN bus.

### Files

| File | Purpose |
|---|---|
| `DiveCANpy/DiveCAN.py` | Core CAN message interface |
| `DiveCANpy/bootloader.py` | STM32 bootloader operations |
| `DiveCANpy/configuration.py` | Configuration management |

### DiveCAN Class

```python
class DiveCAN:
    def __init__(self, device: str) -> None:
        """Initialize CAN interface via SLCAN adapter"""
        self._bus = can.interfaces.slcan.slcanBus(
            channel=device, bitrate=125000, timeout=0.1, rtscts=True
        )

    # Message sending
    def send_bootloader(self) -> None
    def send_setpoint(self, src_id: int, setpoint: int)
    def send_calibrate(self) -> None
    def send_menu_req(self, target_id: int, src_id: int) -> None

    # Message receiving
    def listen_for_ppo2(self) -> can.Message
    def listen_for_status(self) -> can.Message
    def listen_for_cal(self) -> can.Message
    def listen_for_millis(self) -> can.Message
```

### Usage Example

```python
from DiveCANpy import DiveCAN

client = DiveCAN.DiveCAN('/dev/ttyCAN0')
client.send_id(1)  # Send bus init
msg = client.listen_for_ppo2()  # Wait for PPO2 response
print(f"Cell 1 PPO2: {msg.data[0]}")
client.stop()
```

## pytest Fixtures

Defined in `HW Testing/Tests/conftest.py`:

### Basic Fixtures

```python
@pytest.fixture()
def power_divecan_client_fixture():
    """DiveCAN interface with PSU control"""
    power = psu.PSU()
    divecan_client = make_divecan()
    yield (divecan_client, power)
    divecan_client.stop()

@pytest.fixture()
def power_shim_divecan_fixture():
    """DiveCAN + HWShim + PSU"""
    power = psu.PSU()
    divecan_client = make_divecan()
    yield (divecan_client, HWShim.HWShim(), power)
    divecan_client.stop()
```

### Parameterized Fixtures

```python
@pytest.fixture(params=configuration.supported_configurations())
def config_and_power_divecan_client(request):
    """DiveCAN with configuration matrix"""
    pwr = psu.PSU()
    divecan_client = make_divecan()
    shim_host = HWShim.HWShim()
    configuration.configure_board(divecan_client, request.param)
    yield (divecan_client, shim_host, request.param, pwr)
    divecan_client.stop()

@pytest.fixture(params=configuration.supported_configurations())
def config_and_cal_and_power_divecan_client(request):
    """DiveCAN with configuration and calibration"""
    # ... configure and calibrate ...
    utils.ensureCalibrated(divecan_client, shim_host)
    yield (divecan_client, shim_host, request.param, pwr)
```

## Hardware Shim (HWShim)

Arduino Due-based hardware simulator for injecting sensor values.

### File: `HW Testing/Tests/HWShim.py`

```python
class HWShim:
    def __init__(self) -> None:
        self._serial_port = serial.Serial('/dev/ttyDUE0', 115200)

    def set_digital_ppo2(self, cell_num: int, ppo2: float) -> None:
        """Set digital cell PPO2 (DiveO2/O2S simulation)"""
        msg = f"sdc,{cell_num},{ppo2*100},"
        self._serial_port.write(msg.encode())
        # Wait for acknowledgment...

    def set_analog_millis(self, cell_num: int, millis: float) -> None:
        """Set analog cell millivolts (DAC output)"""
        msg = f"sac,{cell_num},{millis},"
        self._serial_port.write(msg.encode())

    def set_digital_mode(self, cell_num: int, mode: ShimDigitalCellType):
        """Set digital cell protocol (DiveO2 vs O2S)"""
        msg = f"scm,{cell_num},{int(mode)},"
        self._serial_port.write(msg.encode())

    def set_bus_on(self) -> None:
        """Enable CAN bus power"""

    def set_bus_off(self) -> None:
        """Disable CAN bus power"""
```

### HWShim Commands

| Command | Format | Description |
|---|---|---|
| sdc | `sdc,N,ppo2,` | Set digital cell N PPO2 (centibar) |
| sac | `sac,N,mV,` | Set analog cell N millivolts |
| scm | `scm,N,mode,` | Set cell N mode (0=DiveO2, 1=O2S) |
| sdcen | `sdcen` | Enable DC bus |
| sdcden | `sdcden` | Disable DC bus |

## PSU Control

`HW Testing/Tests/psu.py` controls the lab power supply:

### Supported PSUs

- **Riden RD6006** - Primary PSU over serial
- **Nordic PPK2** - For power profiling

```python
class PSU:
    def __init__(self):
        # Initialize Riden PSU
        pass

    def set_voltage(self, voltage: float):
        """Set output voltage"""

    def set_current_limit(self, current: float):
        """Set current limit"""

    def enable_output(self):
        """Enable PSU output"""

    def disable_output(self):
        """Disable PSU output"""
```

## Device Paths

Standard device paths for test hardware:

| Device | Path | Description |
|---|---|---|
| CAN Adapter | `/dev/ttyCAN0` | USB-SLCAN adapter |
| Arduino Due | `/dev/ttyDUE0` | HWShim controller |
| Riden PSU | `/dev/ttyUSB0` | Lab power supply |

These are typically set up via udev rules for consistent naming.

## Test Organization

### Test Files

| File | Purpose |
|---|---|
| `test_ping.py` | Basic connectivity tests |
| `test_ppo2.py` | PPO2 reading accuracy |
| `test_ppo2_control.py` | Solenoid control loop |
| `test_calibration.py` | Calibration procedures |
| `test_configuration.py` | Configuration persistence |
| `test_pwr_management.py` | Power mode switching |
| `test_menu.py` | DiveCAN menu system |
| `test_bootloader.py` | Firmware update |

### Running Tests

```bash
cd "HW Testing/Tests"

# Run all tests
pytest

# Run specific test file
pytest test_ppo2_control.py

# Run with verbose output
pytest -v

# Run specific test
pytest test_ppo2.py::test_cell_reading_accuracy
```

## Test Patterns

### Basic Test

```python
def test_ppo2_reading(power_shim_divecan_fixture):
    divecan, shim, psu = power_shim_divecan_fixture

    # Set known PPO2 on shim
    shim.set_digital_ppo2(0, 0.21)

    # Read from DUT
    msg = divecan.listen_for_ppo2()

    # Verify
    assert msg.data[0] == 21  # 0.21 bar = 21 centibar
```

### Parameterized Test

```python
@pytest.mark.parametrize("config", configuration.supported_configurations())
def test_config_persistence(power_divecan_client_fixture, config):
    divecan, psu = power_divecan_client_fixture

    # Apply configuration
    configuration.configure_board(divecan, config)

    # Power cycle
    psu.disable_output()
    time.sleep(1)
    psu.enable_output()

    # Verify configuration persisted
    # ...
```

### Configuration Matrix

```python
# From configuration.py
def supported_configurations():
    """Return list of valid configuration combinations"""
    return [
        Config(cell1=ANALOG, cell2=ANALOG, cell3=ANALOG),
        Config(cell1=DIVEO2, cell2=ANALOG, cell3=ANALOG),
        Config(cell1=DIVEO2, cell2=DIVEO2, cell3=ANALOG),
        # ...
    ]
```

## Unit Tests (CppUTest)

### Building Unit Tests

```bash
# First time: build cpputest
cd STM32/Tests/cpputest
autoreconf -i
./configure
make

# Build and run tests
cd STM32/Tests
make
```

### Mock Structure

Mocks are in `STM32/Mocks/`:
- HAL functions (GPIO, I2C, UART, etc.)
- FreeRTOS functions (queues, tasks, etc.)
- Peripheral drivers

### Test Example

```cpp
TEST(PPO2Control, SetpointTracking)
{
    // Setup
    PPO2Control_Init(&config);

    // Exercise
    PPO2Control_SetSetpoint(1.0f);
    PPO2Control_Update(0.8f);  // Below setpoint

    // Verify
    CHECK(PPO2Control_GetDutyCycle() > 0.0f);
}
```

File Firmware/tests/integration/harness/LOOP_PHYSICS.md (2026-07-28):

# Rebreather Loop Physics — Modelling Notes

Working notes for the closed-loop plant model (`rebreather_model.py`) used by
the targeted autotune integration tests. The model supports characterising new
loops through profiles in `LOOP_PROFILES`; this document captures the data and
reasoning behind the defaults so future profiles can be calibrated against the
same evidence.

## Sources

### 1. Real dive log (`log_backup/12-12-2025/`)

QuickRecon DiveCAN unit, ~2 h dive, 110 solenoid fires logged in
`LOG.TXT`.  Cross-referenced with `EVENTS.CSV` PPO2 samples
(consensus at 500 ms cadence) and `PPO2_ATMOS` for ambient pressure.

Solenoid pulse duration: **uniformly 1.5 s** (only fire length seen
across the entire dive).  Hardware delivers a fixed pulse via the
PID's PWM duty mapping plus minimum-on-time clamping.

### 2. Sensor specs (vendor / characterisation)

| Cell type | Time constant | Notes |
|---|---|---|
| DiveO2 | t63 ≈ 2.0 s | Electrochemistry only; UART sampling separate |
| OxygenScientific O2S | t63 ≈ 2.0 s | As above; ~500 ms protocol sampling on top |
| Galvanic (analog) | t90 ≈ 6 s → t63 ≈ 2.6 s | First-order assumption (`τ = t90 / ln 10 ≈ t90 / 2.303`) |

The model treats every cell as a first-order lag on the true local
PPO2 — adequate for the seconds-scale dynamics the PID has to handle.
Higher-order sensor effects (digital cells' DSP smoothing, galvanic
temperature dependence) are not modelled.

## Key empirical finding: substantial overshoot

Isolated fire at **t = 4749 s** (chosen because >30 s gap from
neighbouring fires, so the response is uncontaminated):

| Quantity | Value |
|---|---|
| Ambient pressure | 1.74 bar (~7.4 m FW) |
| Baseline PPO2 | 0.701 bar |
| Peak PPO2 (within ~2 s of fire) | 0.778 bar |
| Settled PPO2 (~30 s after) | 0.707 bar |
| Peak above baseline | **+0.077 bar** |
| Overshoot above settled | **+0.071 bar (≈92% of total rise)** |
| Time to peak from fire start | 2.2 s |

In other words, a 1.5 s injection pulse pushes PPO2 to a *peak* that's
71 mbar above where it'll eventually settle.  The sensors see this
spike before the gas redistributes through the rest of the loop.

This overshoot **cannot be modelled by a single first-order mixing
lag** — first-order step responses can't peak above their input.
Reproducing the dive-log behaviour requires either (a) a model with
explicit injection-plume dynamics, or (b) a multi-compartment loop
model with sensors in the compartment that receives the injection.

### Mass-balance check (at the dive conditions above)

For a 5 LPM injection into a 1.5 L local volume at 1.74 bar
ambient, baseline fraction 0.403, 1.5 s pulse:

```
df/dt = Q_inj · (1 − f) / V_local
      = (5 / 60) · (1 − 0.403) / 1.5
      ≈ 0.033 s⁻¹

Δf over 1.5 s pulse, integrating with f rising:  ≈ +0.04
peak local PPO2 ≈ (0.403 + 0.04) · 1.74  ≈  0.77 bar
```

That matches the observed peak of 0.778 bar to within model parameter
uncertainty.  The smoke test in `rebreather_model.py`'s docstring
confirms the 2-compartment model produces a comparable spike.

## Model topology

```
solenoid open → +Q_inj LPM pure O2 ─┐
                                    ▼
                          ┌──────────────────┐
          metabolic O2 ←──│  LOCAL  V_local  │
          consumption     │  fraction f_l    │
                          │  (sensors here)  │
                          └──────────┬───────┘
                                     │  exchange flow Q_mix
                                     │  (proportional to f_l − f_b)
                                     ▼
                          ┌──────────────────┐
                          │  BULK   V_bulk   │
                          │  fraction f_b    │
                          └──────────────────┘

         per-cell first-order sensor lag (τ_cell)
                          │
                          ▼
                    reported PPO2[N]
```

Sensors read **the local compartment**.  Injection drives `f_l` quickly
upward in the small volume; the spike then bleeds into the bulk over
seconds via `Q_mix`.  Diver metabolism removes O2 from the local
compartment (the diver breathes from where the sensors are).

### Parameter intuition

| Parameter | Effect on response |
|---|---|
| `local_volume_l`  | Smaller → larger peak per pulse (less dilution at sensors) |
| `bulk_volume_l` | Larger → sustained overshoot, slower decay to settled |
| `mix_exchange_lpm`| Larger → faster local↔bulk equilibration → smaller overshoot |
| `metabolic_lpm` | Higher → settled PPO2 trends down without firing |
| `solenoid_lpm` | Higher → bigger peak per pulse, less PID stability |
| `sensor_tau_s` | Higher → phase lag at sensor; can destabilise PID |

## Calibration against dive data

The `"typical"` profile is tuned to bracket the t=4749 fire response:

| `LoopProfile` field | Value | Justification |
|---|---:|---|
| `local_volume_l` | 1.5 L | Mouthpiece + hose + sensor housing  |
| `bulk_volume_l` | 4.5 L | Counterlung + scrubber canister |
| `mix_exchange_lpm` | 10 LPM | Tuned so spike decays in ~6 s |
| `metabolic_lpm` | 1.5 LPM | Typical moderate work |
| `solenoid_lpm` | 5 LPM | Common CCR injection rate |
| `ambient_pressure_bar`  | 1.0 (default) | Surface — override for depth tests  |
| `initial_o2_fraction` | 0.21 | Air |

The other profiles (`slow_plant`, `fast_plant`, `resting`,
`heavy_work`) bracket the four axes the user identified as
operationally relevant: loop volume, exchange rate, breathing rate,
and injection flow.

## Volume balance — diluent makeup and venting

Real CCR loops conserve gas volume actively.  When the diver consumes
O2 faster than the solenoid replaces it, an automatic diluent valve
(ADV) admits diluent gas to keep the counterlung from collapsing.
When the solenoid pumps in more than the diver consumes, the
overpressure valve (OPV) vents the excess.  These two flows are
critical to MK15 stability: without them, the simple mass balance
``df/dt = Q_inj * (1 − f) − Q_met * f`` produces an equilibrium
``f = Q_inj / (Q_inj + Q_met)`` that's far below the operating PPO2,
because the solenoid term self-saturates as ``f`` approaches 1.

The model implements both:

```python
Q_dil  = max(0, Q_met - Q_inj_inst)   # diluent fills volume deficit
Q_vent = max(0, Q_inj_inst - Q_met)   # excess vents at f_local
```

O2 mass balance on the local compartment:

```
df_local/dt = (
      Q_inj * 1                  # pure-O2 solenoid inflow
    + Q_dil * f_dil              # diluent inflow at diluent fraction
    - Q_met * 1                  # diver removes pure O2
    - Q_vent * f_local           # OPV releases at current fraction
    + Q_mix * (f_bulk - f_local) # convective exchange to bulk
) / V_local
```

With these terms, sustained ``Q_inj > Q_met`` drives the loop toward
``f → 1`` (pure O2), bounded by the solenoid's max flow rate.  MK15's
bang-bang algorithm can therefore reach any PPO2 ≤ ``solenoid_lpm * P``
provided its 20%-duty mean injection ≥ metabolic demand.

### Surface-vs-depth dimensioning

MK15's worst case is **surface (1 ATA)** because the diluent baseline
contributes only ``f_dil × 1 = 0.21`` bar PPO2 — the solenoid has to
bridge the entire remaining 0.49 bar to setpoint.  At depth, the
diluent contribution grows with ambient pressure (1.74 bar gives 0.37
bar from air alone) and the solenoid has less work to do.

For MK15 to track a 0.7 bar setpoint at surface:

```
solenoid_lpm * (1 − f_eq) * 1.5s ≥ Q_met * (1 − f_dil) * 6s
                                                      ^ off period
                                       ^ where MK15 idles and the diluent
                                         drains O2 fraction toward f_dil
```

With ``Q_met = 0.6 LPM`` and ``f_dil = 0.21``, this requires
``solenoid_lpm ≥ 6.3 LPM``.  The default profiles set 8 LPM so MK15
has headroom across the full surface→deep envelope.

## STP flow → fraction-change scaling at depth

Solenoid flow `Q_inj` and metabolic demand `Q_met` are specified in
**STP volume per minute** (the convention vendors use for solenoid
orifice specs and diver metabolism).  The compartment volumes
(`V_local`, `V_bulk`) are **actual loop volumes** — the physical
counterlung + hose volume, independent of depth.

To compute a fraction-change rate (`df/dt`, dimensionless per second)
from an STP flow, the model converts to actual-volume terms by
dividing by ambient pressure:

```
Q_eff = Q_STP / P_ambient_bar         # actual volumetric flow rate
df/dt ∝ Q_eff / V_compartment
```

Without this scaling the model would over-predict per-fire PPO2
swings by a factor of `P_ambient` at depth.  A 1.5 s solenoid fire of
5 LPM into a 1.5 L local volume should produce ~9 cb ΔPPO2 at 4 bar
ambient (the back-of-envelope: 0.125 L STP / (1.5 L actual × 4 bar)
× P_ambient ≈ 0.083 bar), not 27 cb.  The latter would predict
catastrophic over-injection at recreational depths — operationally
nonsensical, and not what real CCR loops do.

## Depth-dependent diluent gas mix

Real CCR divers swap diluent gas with depth so the diluent's PPO2
contribution stays within safe operating limits at max depth:

| Depth | Typical f_dil | Diluent PPO2 | Comment |
|---|---|---|---|
| Surface | 0.21 (air) | 0.21 bar | Pre-dive checkout |
| Shallow ~7 m | 0.21 (air) | 0.36 bar | Stays below max safe PPO2 |
| Deep ~30 m | 0.18 (trimix 18/45) | 0.72 bar | Tuned so dil PPO2 ≈ setpoint |

The model's `DEPTH_POINTS` registry pairs each depth with an
appropriate diluent fraction.  Combining shallow operating parameters
with air diluent at 4 bar would put the loop's "no-injection" baseline
PPO2 above setpoint, which the solenoid can't fix and would never
actually happen in the field.

## Known limitations

The current model **omits** the following effects.  None of them
break the "won't oscillate" contract; they matter for higher-fidelity
testing of disturbance rejection or extreme operating points:

1. **Workload-driven metabolic rate** — the model uses a constant
   ``metabolic_lpm``.  Real divers vary O2 consumption with workload;
   a step-response test would need a piecewise schedule.

2. **Gas mixing time within a compartment** — both compartments are
   treated as well-stirred.  Real counterlungs have internal flow
   patterns that delay equilibration.

3. **Tidal-volume breathing** — the model treats consumption as
   continuous.  Real breathing is pulsatile, which can briefly
   underflow the counterlung and trigger ADV bursts even when steady
   state is balanced.

4. **Hyperoxic / hypoxic cell behaviour** — sensors are modelled as
   linear first-order.  At PPO2 > 2 bar or < 0.1 bar the galvanic
   electrochemistry deviates; well outside the operational envelope.

5. **Sensor sampling-rate vs cell time-constant interaction** — the
   per-cell sensor lag captures electrochemistry only.  The firmware's
   DiveO2 / O2S poll cadence (~100 ms / ~500 ms) adds additional phase
   lag at the controller's input.  Not yet modelled separately.

## How to add a newly characterised loop

1. Pick a representative isolated fire from the unit's dive log (≥30 s
   isolation from neighbouring fires).
2. Extract: baseline PPO2, peak PPO2, settled PPO2, ambient pressure,
   time-to-peak.
3. Solve for `(local_volume_l, bulk_volume_l, mix_exchange_lpm)` that
   reproduces those values when the smoke test in
   `rebreather_model.py`'s docstring is re-run.
4. Add a new entry to `LOOP_PROFILES` with a clear `source` string
   referencing the log file and fire timestamp.
5. Add a focused test that selects the profile only when it asserts a specific
   controller or autotune contract; profiles are not run as a broad stability
   matrix.

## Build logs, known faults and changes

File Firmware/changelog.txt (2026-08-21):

# DiveCANHead Firmware Changelog

<!--
Before running the Firmware Release action:

1. Set VERSION to the numbered release.
2. Move the applicable Unreleased entries under a heading formatted exactly as:
   ## 1.2.3 - YYYY-MM-DD
3. Leave a new Unreleased section at the top.

The release action uses the numbered section as the GitHub Release description
and includes this complete file in the downloadable package.
-->

## Unreleased

### Added
- Automatically start handset when board boots up

### Changed

- Inhibit O2 flushing onto cells when depth is below 10m
- Change HP sensors to not broadcast on errors, rather than broadcast an error sentinel

### Fixed
- Added inhibit to prevent spurious power on if the BUS EN line remains low after boot checks are complete
- Fix an issue where the board could crash when downloading large amounts of log data due to an error histogram write occuring at the same time
- Fix repeated reboots (seen as unresponsive handset communication) caused by the new periodic power logging overflowing the battery monitor's stack
- Fix the head going silent (no PPO2 broadcasts, no handset replies) for several seconds when a setting is saved shortly after boot
- Record a failed battery current read in the persistent error counters instead of only a log message

## 0.0.1 - 2026-07-29

### Added

- Initial numbered firmware release workflow with serialized HIL qualification
  for every production variant.
- Complete and per-variant downloadable release packages containing the exact
  tested full-flash and signed OTA images, qualification records, and SHA-256
  checksums.

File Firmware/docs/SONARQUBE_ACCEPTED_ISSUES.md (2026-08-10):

# SonarCloud accepted issues — Firmware/

Issues listed below are legitimate framework / hardware carve-outs. Mark each
**individual** issue as **Won't Fix** or **False Positive** on the SonarCloud
web UI (Issues view → click the issue → "Change Status"). Do **not** disable
the rule project-wide — these are the only cases where it should be allowed.

When new code is added, this list must stay accurate. If a new Zephyr DT-driver
or fault-handler pattern triggers one of these rules, append it here with the
same justification format and accept it manually.

---

## Zephyr DT-driver macro patterns

Standard `DT_DRV_COMPAT` / `DEVICE_DT_INST_DEFINE` / `DT_INST_FOREACH_*` idiom.
The macros are mandated by Zephyr; rewriting as C functions is impossible
(preprocessor-time devicetree expansion).

| Rule | File | Location | Justification |
|---|---|---|---|
| c:S968 / c:M23_212 | `src/hw_version.c` | `HW_VERSION_INIT` macro `##inst` glue | DT instance disambiguation |
| c:S960 / c:M23_042 | `src/hw_version.c` | `HW_VERSION_INIT` definition | Function-like DT init macro |
| c:S967 | `src/hw_version.c` | `HW_VERSION_INIT` definition | Multi-token paste in DT init |
| c:S968 / c:M23_212 | `src/power_management.c` | `POWER_INIT` / `POWER_HAS_PROP` / `POWER_GPIO_*` macros | DT instance disambiguation |
| c:S960 / c:M23_042 | `src/power_management.c` | Same macros | Function-like DT init macros |
| c:S967 | `src/power_management.c` | `POWER_INIT` definition | Multi-token paste |

## Zephyr framework function signatures

| Rule | File(s) | Location | Justification |
|---|---|---|---|
| c:S995 | `src/oxygen_cell_o2s.c`, `src/oxygen_cell_diveo2.c` | `o2s_uart_callback` / `diveo2_uart_callback` `struct uart_event *evt` | Zephyr async UART callback signature is fixed; `evt` cannot be `const` |
| c:S995 | `src/divecan/divecan_rx.c` | CAN RX callback `struct can_frame *frame` | Zephyr CAN callback signature is fixed |
| c:S1172 | `src/oxygen_cell_o2s.c`, `src/oxygen_cell_diveo2.c` | UART callback `const struct device *dev` parameter | Zephyr API contract — parameter is required even when unused |
| c:M23_388 | `src/oxygen_cell_o2s.c`, `src/oxygen_cell_diveo2.c` | `o2s_cell_1/2/3`, `diveo2_cell_1/2/3` static structs | `K_THREAD_DEFINE` captures the address at compile time; accessor wrapping is incompatible with that macro |
| c:M23_388 | `src/errors.c` | `crash_noinit` (volatile, `__noinit`), `last_crash`, `had_crash` | `__noinit` requires file-scope storage; fatal handler accesses these from arbitrary contexts where passing args is not possible |
| c:M23_388 | `src/oxygen_cell_analog.c` | `analog_cell_*` static structs | Same `K_THREAD_DEFINE` rationale as o2s/diveo2 |

## POSIX feature-test macro

| Rule | File(s) | Justification |
|---|---|---|
| c:S978 | `src/oxygen_cell_o2s.c`, `src/oxygen_cell_diveo2.c` | `_POSIX_C_SOURCE` is the standard way to expose `strtok_r` / `strncasecmp` from `<string.h>` on the `native_sim` host build; there is no non-reserved alternative |

## Volatile / atomic for busy-wait

| Rule | File | Location | Justification |
|---|---|---|---|
| c:S3687 | `src/errors.c` | `fatal_op_error` and `k_sys_fatal_error_handler` spin loops over `volatile Status_t i` | RTT-drain busy-wait, not inter-thread synchronisation. `atomic_t` provides ordering semantics that are irrelevant here; the `volatile` just defeats optimiser removal of the empty loop body |

## TODO comments

| Rule | File / Location | Justification |
|---|---|---|
| c:S1135 / c:S1707 | `src/power_management.c` L147, L163, L219 (Rev2-hardware vbus/can sense + STM32 SHUTDOWN-mode TODOs) | These mark genuine deferred work tracked under "active dev" phase. Author attribution is in the comment (`aren.leishman@gmail.com, 2026-05-11`). |
| c:S1135 / c:S1707 | `src/divecan/uds/uds_state_did.c` L104, L110, L116 (PID controller wire-up TODOs) | Same — deferred until the PPO2 control task is ported. Attribution in comment. |

S1707 ("Add a citation") and S1135 ("Complete this TODO") fire on every TODO
comment regardless of formatting. They are intentional code markers, not
violations. Mark **Won't Fix** on SonarCloud once the rule is reviewed.

## Preprocessor: undefined Kconfig macros under IDE analysis

| Rule | File / Location | Justification |
|---|---|---|
| c:S966 / c:M23_045 | `src/runtime_settings.c` lines using `CONFIG_CELL_COUNT`, anywhere `CONFIG_*` symbols appear in `#if` | The IDE-side SonarLint analyzer does not include the Zephyr build-system `autoconf.h`, so it sees `CONFIG_*` symbols as undefined (evaluates to 0). These are correctly defined at build time. **False positive in IDE only.** Mark Won't Fix once SonarCloud server-side scans (which use the actual build commands) confirm absence. |

## CONTAINER_OF in adc_context callbacks

| Rule | File / Location | Justification |
|---|---|---|
| c:S3519 (BLOCKER ×2) | `drivers/ads1x1x/adc_ads1x1x_local.c`, `adc_context_update_buffer_pointer` and `adc_context_start_sampling` | `CONTAINER_OF(ctx, struct ads1x1x_data, ctx)` recovers the driver data block from the embedded `adc_context` member — the callback signature is fixed by Zephyr's `adc_context.h` contract, and CONTAINER_OF is the canonical (and only) way to implement it. The analyzer flags the negative byte offset of the pointer arithmetic as an out-of-bounds access; it is well-defined because `ctx` is always embedded in a `struct ads1x1x_data`. Marked **False Positive** on SonarCloud (2026-07-27, PR 4 keys AZ-iJ0tU4Ln9rv4-xLxe/-xLxf); re-mark if the issues reappear on a branch analysis. |

## CI workflow pip dependency locking

| Rule | File / Location | Justification |
|---|---|---|
| githubactions:S8544 | `.github/workflows/build.yml`, harness pip install | All top-level packages and the harness `requirements.txt` are exact-version pinned (`==`), installed `--only-binary :all:` (single audited sdist exception), from a repo-controlled file onto a self-hosted runner. The residual ask is hash-locking (`pip-compile --generate-hashes` + `--require-hashes`); tracked as CI-maintenance follow-up. Accepted 2026-07-27 (key AZ-jITbijjNxyah3r3UF). |

## Volatile-stripping cast

| Rule | File | Location | Justification |
|---|---|---|---|
| c:S859 / c:M23_090 / c:M23_094 | `src/errors.c` | `errors_init` reads `crash_noinit` via `memcpy(&snapshot, (const void *)&crash_noinit, ...)` | The `volatile` qualifier on `crash_noinit` is purely for the link-time placement in noinit RAM. By the time `errors_init` runs (first reader after boot, before any other RAM-touching code) the data has settled, and we read once via `memcpy` |

---

## 2026-07-28 bulk accept — PR 4 sweep residue

458 issues accepted (Won't Fix) in one pass via the SonarQube MCP
`change_sonar_issue_status` tool, all `status: accept`, 0 failures. Every
disposition below was reviewed by prior audit agents plus a final user
ruling before execution — this entry records the rationale per reason
code, not a per-issue log. The full key list, file:line, and rule for
each of the 458 issues lives in SonarCloud issue history / PR 4 (not
reproduced here — see the SonarCloud UI issue search, filtered to
`resolution=WONTFIX` with a 2026-07-28 resolution date, for the
authoritative list).

| Reason code | Count | Rule classes | Rationale |
|---|---|---|---|
| APICONTRACT | 199 | c:S813, c:M23_058, c:S995, c:S953, etc. | Fixed function/type signatures mandated by Zephyr, MCUboot, or libc APIs (raw `float`/`int` in framework struct fields and callback prototypes, parameter contracts that cannot be altered without breaking the framework's ABI). |
| DTMACRO | 100 | c:S968, c:M23_212, c:S960, c:M23_042 | Zephyr devicetree / ZBUS / SMF / LOG macro machinery (`DEVICE_DT_INST_DEFINE`, `DT_INST_FOREACH_PROP_ELEM`, and equivalents) — function-like and token-pasting macros required by the framework's preprocessor-time expansion model; no C-function equivalent exists. |
| ACCESSOR | 76 | c:M23_233, c:M23_388 | Static-accessor / `K_THREAD_DEFINE` / ISR-state pattern. User ruling: the accessor pattern (file-scope static state exposed via a getter, or state captured by address at compile time for `K_THREAD_DEFINE`) is project convention, not a violation to fix. |
| DESIGN | 38 | c:S5536, c:S834, c:S5813, c:S6871 | Intentionally-public unused API surface, self-sizing tables, and other structural choices judged correct by design rather than defects — e.g. framework-mandated struct initializers, driver APIs kept public for future/external callers. |
| STRUCTURAL | 24 | c:S3776, c:S134, c:S1151, c:S1541, c:S1005 | Complexity/nesting/single-return findings in HIL-validated subsystems where extraction was judged riskier than the existing debt — refactor deferred rather than risking regression in hardware-proven code paths. |
| IDENT31 | 21 | c:S799 | Identifiers exceeding the 31-character portability limit; accepted against modern linker/compiler reality (no 31-char C89 restriction applies to this toolchain), consistent with existing IDENT31-style carve-outs elsewhere in this doc. |

**Total: 458 accepted, 0 failed.**

---

## Process for future suppressions

1. **Try to fix the code first.** A suppression is the last resort.
2. **If the rule is structurally impossible to satisfy** (Zephyr framework
   contract, hardware requirement), add the case to the table above with:
   - The specific file and location
   - The exact reason it's impossible
   - The Zephyr / hardware reference (link or commit) where applicable
3. **Accept the specific issue on SonarCloud**, not the rule. Use "Won't Fix"
   for design decisions, "False Positive" only when the rule is genuinely
   misfiring.
4. **Do not add rule suppressions to `sonar-project.properties` or
   `.vscode/settings.json`.** Per-issue acceptance on SonarCloud keeps the
   rule active for any new violation.

## Zephyr atomic bit-mask rule carousel

| Rule | File / Location | Justification |
|---|---|---|
| c:S813 / c:M23_058 | `src/heartbeat.c` `heartbeat_register`, `unsigned long bit_ul = BIT(id)` | Four rules form an unsatisfiable cycle on `atomic_or(mask, BIT(id))`: no cast → S845 (signed/unsigned mix), cast on `BIT(id)` → S851 (cast on composite), shift in `atomic_val_t` → S874 (shift on signed), and the intermediate `unsigned long` — the exact type `BIT()` yields — → S813/M23_058 (raw builtin). Zephyr's `atomic_val_t` is signed `long` and `BIT()` is `unsigned long` by API contract; `unsigned long` is the least-wrong resting point. Accepted 2026-07-28 (keys AZ-mYY46vl4caSOBYurf/-g). |

## 2026-08-09 new-code sweep — structurally-required statics and API contracts

Accepted during the post-v0.0.1 new-code cleanup (164-issue sweep). Everything
fixable was fixed; the rows below are the residue where the "fix" would break a
compile-time contract or replace the project's own blessed pattern.

| Rule | File / Location | Justification |
|---|---|---|
| c:M23_388 / c:S6871 | `src/flash_log/flash_log.c` `fl_telemetry_fcb` / `fl_text_fcb` | `struct fcb` embeds a `k_mutex` and Zephyr-internal state whose aggregate layout is configuration-dependent (same class as the diveo2/o2s semaphore note); the structs persist for the FCB API's lifetime and `.f_flags` is a `const` member that must be set at definition. |
| c:M23_388 | `src/flash_log/flash_log.c` `fl_init_mutex`, `src/external_flash.c` L15, `src/calibration_store.c` L180 | `K_MUTEX_DEFINE` places a link-time-initialised control block; converting to a function-local static would need a racy run-time `k_mutex_init` once-guard — strictly worse than the flagged code. |
| c:M23_388 | `src/option_bytes.c` L88-89 | `__noinit` variables must live at file scope (same carve-out as `errors.c` `crash_noinit`). |
| c:M23_233 | Any function-local static inside a static accessor introduced for M23_388 compliance — `src/calibration_store.c`, `src/divecan/divecan_rx.c`, `src/ppo2_control.c`, `src/runtime_settings.c`, `src/boot_history.c`, `src/divecan/uds/uds_log_download.c`, `src/divecan/uds/uds_state_did.c`, `src/flash_log/flash_log.c`, `src/main.c` | Each flagged local static IS the inner variable of the project's static-accessor pattern (heartbeat.c precedent, adopted to satisfy M23_388); flagging the accessor's own static is the rule chasing its tail. Fixing M23_388 necessarily mints one M23_233 per accessor. |
| c:M23_094 | `src/errors.c` L50 | Crash recording must capture the fault stack pointer as an integer; already the compliant `(uint32_t)(uintptr_t)` two-step. |
| c:S813 / c:M23_058 | `src/calibration_store.c` `cal_settings_get` `int val_len_max` parameter | Zephyr `settings_handler_static.h_get` function-pointer table: on arm-zephyr-eabi `int32_t` is `long int`, so an `int32_t` parameter makes the handler an incompatible pointer type. API contract; cannot change. |
| c:S995 | `src/divecan/uds/uds.c` `faultInjectionTimerHandler` `struct k_timer *timer` | `K_TIMER_DEFINE` expiry callback — signature fixed by Zephyr `k_timer_expiry_t`; `const` makes the function-pointer type incompatible (same class as the UART/CAN callback rows above). |
| c:S5536 | `include/calibration_store.h` L73 `calibration_store_seed_cached` | Used by `tests/diveo2_thread` and `tests/o2s_thread` ztests; `#ifdef CONFIG_ZTEST`-guarded so it does not exist in production builds. |

## Coverage exclusions (2026-07-29)

Coverage-only carve-outs added during the 90%-coverage uplift. Unlike rule
suppressions, these remove structurally-untestable code from the coverage
denominator; the files remain fully analyzed for code-quality rules.

| Mechanism | Location | Justification |
|---|---|---|
| `sonar.coverage.exclusions` | `Firmware/src/thread_analyzer_paced.c` | `thread_analyzer_run()` is `depends on !ARCH_POSIX` upstream — physically cannot execute on native_sim. Observability-only TU; exercised on the HIL rig every 30 s (see Firmware/CMakeLists.txt comment). |
| `sonar.coverage.exclusions` | `Firmware/src/option_bytes.c` | Reads live STM32 FLASH option-byte registers via HAL/LL; a register-indirection mock would test only the mock. Verified at every hardware boot (logged). |
| `sonar.coverage.exclusions` | `DiveCAN_bt/src/diagnostics/PlotManager.js`, `DiveCAN_bt/src/diagnostics/CellUIAdapter.js`, `DiveCAN_bt/src/DeviceManager.js` | Pure-DOM rendering glue with no protocol logic; jsdom tests would assert framework behavior, not ours. Protocol core is tested to >95 % lines. |
| `GCOVR_EXCL` in-source | `Firmware/src/hw_version.c` (`blink_forever`, `halt_with_blink`) | Infinite pre-boot halt loops — a covered run would never terminate. Deliberate design: version mismatch must halt, not reboot. |
| `GCOVR_EXCL` in-source | `Firmware/src/errors.c` (crash-replay arm in `errors_init`, true-arm of `errors_get_last_crash`) | Requires `CRASH_MAGIC` surviving a warm reset in noinit RAM; a native_sim process boots exactly once with the slot zeroed. Hardware-only path. |

Unreachable-but-not-excluded remainders (documented in each test module's
header instead of excluded): driver fault-injection arms the emulators cannot
produce (gpio/uart/flash-sim never fail I/O), `FATAL_OP_ERROR` init arms that
reboot before ztest gains control, and logging-macro internal branches.

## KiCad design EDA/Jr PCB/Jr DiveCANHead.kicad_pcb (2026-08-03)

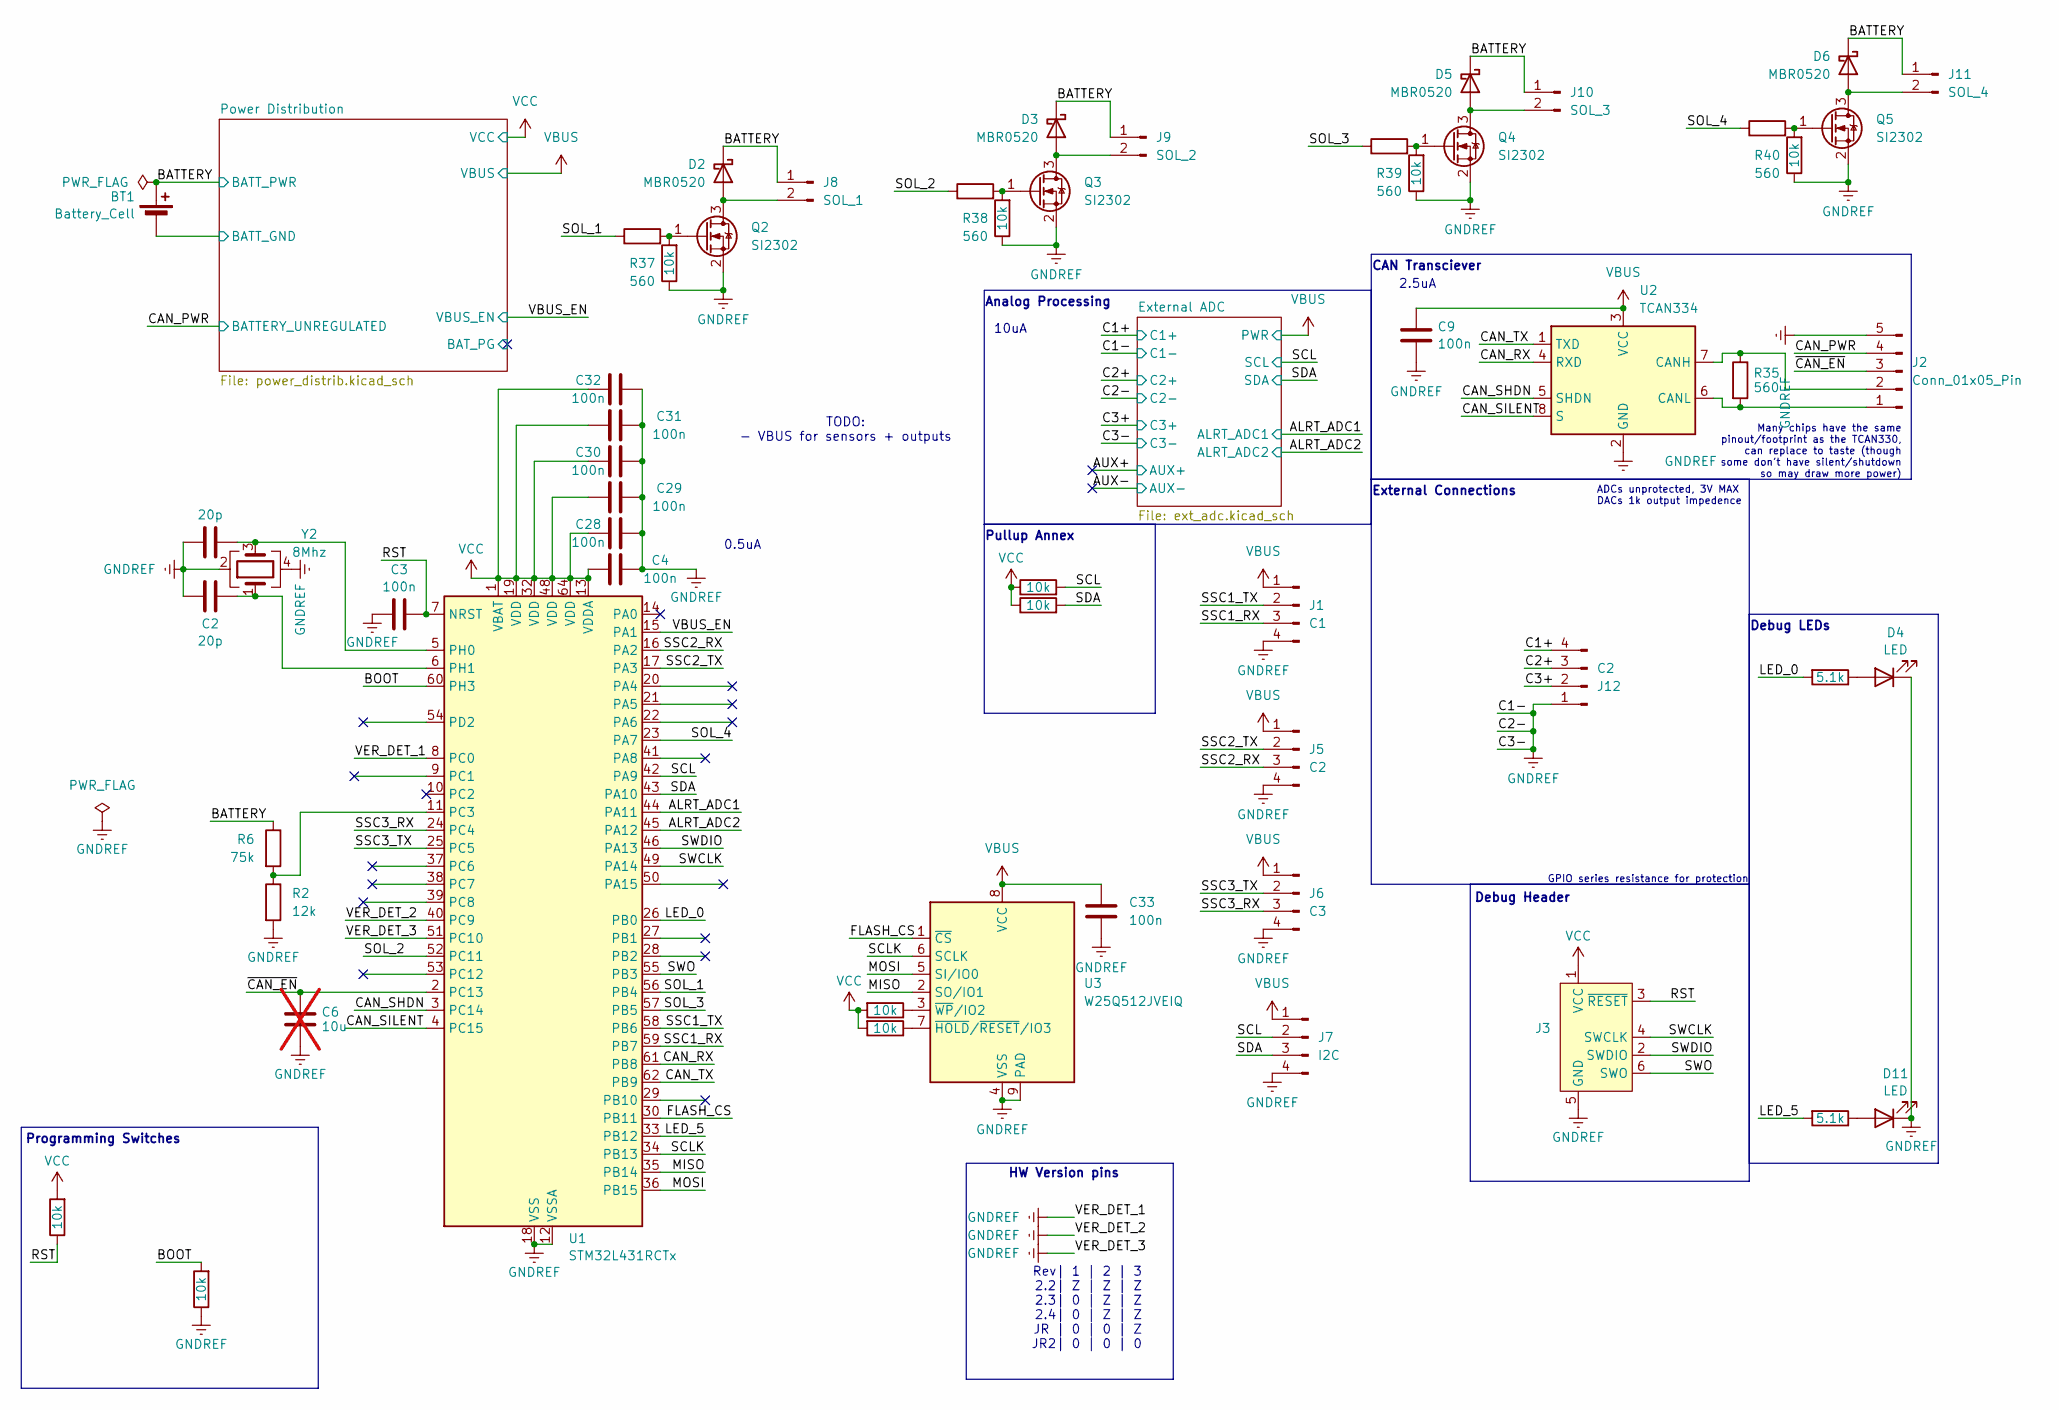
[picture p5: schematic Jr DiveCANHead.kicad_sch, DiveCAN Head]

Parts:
BT1: Battery_Cell; BatteryHolder_Eagle_12BH611-GR
C1, C2: 20p; C_0603_1608Metric; MPN C325469
C3, C4, C9, C28, C29, C30, C31, C32, C33: 100n; C_0603_1608Metric; MPN C14663
C6: 10u; C_0603_1608Metric; MPN C96446; not fitted
D2, D3, D5, D6: MBR0520; D_SOD-123; MPN C5204745
D4, D11: LED; LED_0805_2012Metric; MPN C84256
J1: C1; PinHeader_1x04_P2.54mm_Vertical
J2: Conn_01x05_Pin; PinHeader_1x05_P2.54mm_Vertical
J3: Conn_ARM_SWD_TagConnect_TC2030-NL; Tag-Connect_TC2030-IDC-NL_2x03_P1.27mm_Vertical
J5, J12: C2; PinHeader_1x04_P2.54mm_Vertical
J6: C3; PinHeader_1x04_P2.54mm_Vertical
J7: I2C; PinHeader_1x04_P2.54mm_Vertical
J8: SOL_1; PinHeader_1x02_P2.54mm_Vertical
J9: SOL_2; PinHeader_1x02_P2.54mm_Vertical
J10: SOL_3; PinHeader_1x02_P2.54mm_Vertical
J11: SOL_4; PinHeader_1x02_P2.54mm_Vertical
Q2, Q3, Q4, Q5: SI2302; SOT-23; MPN C181087; JlcRotOffset 180
R1, R3, R4, R5, R7, R8, R9, R10, R11, R12: 10k; R_0402_1005Metric; MPN C25744
R2: 12k; R_0402_1005Metric; MPN C25752
R6: 75k; R_0402_1005Metric; MPN C25798
R35: 560; R_0603_1608Metric; MPN C23204
R36, R43: 5.1k; R_0402_1005Metric; MPN C25905
R37, R38, R39, R40: 560; R_0402_1005Metric; MPN C163460
U1: STM32L431RCTx; LQFP-64_10x10mm_P0.5mm; JLC C92468
U2: TCAN334; SOIC-8_3.9x4.9mm_P1.27mm; MPN C2871143; JlcRotOffset -90
U3: W25Q512JVEIQ; WSON-8-1EP_8x6mm_P1.27mm_EP3.4x4.3mm; MPN C7389628
Y2: 8Mhz; Crystal_SMD_3225-4Pin_3.2x2.5mm; MPN C648987

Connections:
/ALRT_ADC1: U1.44 (PA11); also elsewhere on the board
/ALRT_ADC2: U1.45 (PA12); also elsewhere on the board
/BATTERY: BT1.1 (+), D2.1 (K), D3.1 (K), D5.1 (K), D6.1 (K), J8.1, J9.1, J10.1, J11.1, R6.1; also elsewhere on the board
/BOOT: R4.2, U1.60 (PH3)
/C1+: J12.4; also elsewhere on the board
/C2+: J12.3; also elsewhere on the board
/C3+: J12.2; also elsewhere on the board
/CAN_PWR: J2.4; also elsewhere on the board
/CAN_RX: U1.61 (PB8), U2.4 (RXD)
/CAN_SHDN: U1.3 (PC14), U2.5 (SHDN)
/CAN_SILENT: U1.4 (PC15), U2.8 (S)
/CAN_TX: U1.62 (PB9), U2.1 (TXD)
/FLASH_CS: U1.30 (PB11), U3.1 (~CS)
/LED_0: R36.2, U1.26 (PB0)
/LED_5: R43.2, U1.33 (PB12)
/MISO: U1.35 (PB14), U3.2 (SO/IO1)
/MOSI: U1.36 (PB15), U3.5 (SI/IO0)
/Power Distribution/BATT_GND: BT1.2 (-); also elsewhere on the board
/RST: C3.2, J3.3 (~RESET), R1.1, U1.7 (NRST)
/SCL: J7.2, R7.2, U1.42 (PA9); also elsewhere on the board
/SCLK: U1.34 (PB13), U3.6 (SCLK)
/SDA: J7.3, R8.2, U1.43 (PA10); also elsewhere on the board
/SOL_1: R37.1, U1.56 (PB4)
/SOL_2: R38.1, U1.52 (PC11)
/SOL_3: R39.1, U1.57 (PB5)
/SOL_4: R40.1, U1.23 (PA7)
/SSC1_RX: J1.3, U1.59 (PB7)
/SSC1_TX: J1.2, U1.58 (PB6)
/SSC2_RX: J5.3, U1.16 (PA2)
/SSC2_TX: J5.2, U1.17 (PA3)
/SSC3_RX: J6.3, U1.24 (PC4)
/SSC3_TX: J6.2, U1.25 (PC5)
/SWCLK: J3.4 (SWCLK), U1.49 (PA14)
/SWDIO: J3.2 (SWDIO), U1.46 (PA13)
/SWO: J3.6 (SWO), U1.55 (PB3)
/VBUS_EN: U1.15 (PA1); also elsewhere on the board
/~CAN_EN: C6.1, J2.3, U1.2 (PC13)
GNDREF: C1.1, C2.1, C3.1, C4.1, C6.2, C9.2, C28.1, C29.1, C30.1, C31.1, C32.1, C33.2, D4.1 (K), D11.1 (K), J1.4, J2.5, J3.5 (GND), J5.4, J6.4, J7.4, J12.1, Q2.2 (S), Q3.2 (S), Q4.2 (S), Q5.2 (S), R2.2, R3.1, R4.1, R5.1, R9.1, R10.1, U1.8 (PC0), U1.12 (VSSA), U1.18 (VSS), U1.31 (VSS), U1.40 (PC9), U1.47 (VSS), U1.51 (PC10), U1.63 (VSS), U2.2 (GND), U3.4 (VSS), U3.9 (PAD), Y2.2, Y2.4; also elsewhere on the board
unnamed: D2.2 (A), J8.2, Q2.3 (D)
unnamed: D3.2 (A), J9.2, Q3.3 (D)
unnamed: D4.2 (A), R36.1
unnamed: D5.2 (A), J10.2, Q4.3 (D)
unnamed: D6.2 (A), J11.2, Q5.3 (D)
unnamed: D11.2 (A), R43.1
unnamed: J2.1, R35.2, U2.6 (CANL)
unnamed: J2.2, R35.1, U2.7 (CANH)
unnamed: Q2.1 (G), R3.2, R37.2
unnamed: Q3.1 (G), R5.2, R38.2
unnamed: Q4.1 (G), R9.2, R39.2
unnamed: Q5.1 (G), R10.2, R40.2
unnamed: R2.1, R6.2, U1.11 (PC3)
unnamed: C1.2, U1.5 (PH0), Y2.3
unnamed: C2.2, U1.6 (PH1), Y2.1
unnamed: R12.1, U3.7 (~HOLD/~RESET/IO3)
unnamed: R11.1, U3.3 (~WP/IO2)
VBUS: C9.1, C33.1, J1.1, J5.1, J6.1, J7.1, U2.3 (VCC), U3.8 (VCC); also elsewhere on the board
VCC: C4.2, C28.2, C29.2, C30.2, C31.2, C32.2, J3.1 (VCC), R1.2, R7.1, R8.1, R11.2, R12.2, U1.1 (VBAT), U1.13 (VDDA), U1.19 (VDD), U1.32 (VDD), U1.48 (VDD), U1.64 (VDD); also elsewhere on the board

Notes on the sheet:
10uA
Many chips have the same pinout/footprint as the TCAN330, can replace to taste (though some don't have silent/shutdown so may draw more power)
HW Version pins
Pullup Annex
External Connections
TODO: - VBUS for sensors + outputs
ADCs unprotected, 3V MAX DACs 1k output impedence
Programming Switches
Debug LEDs
0.5uA
GPIO series resistance for protection
Rev| 1 | 2 | 3 2.2| Z | Z | Z 2.3| 0 | Z | Z 2.4| 0 | Z | Z JR | 0 | 0 | Z JR2| 0 | 0 | 0
CAN Transciever
Debug Header
Analog Processing
2.5uA

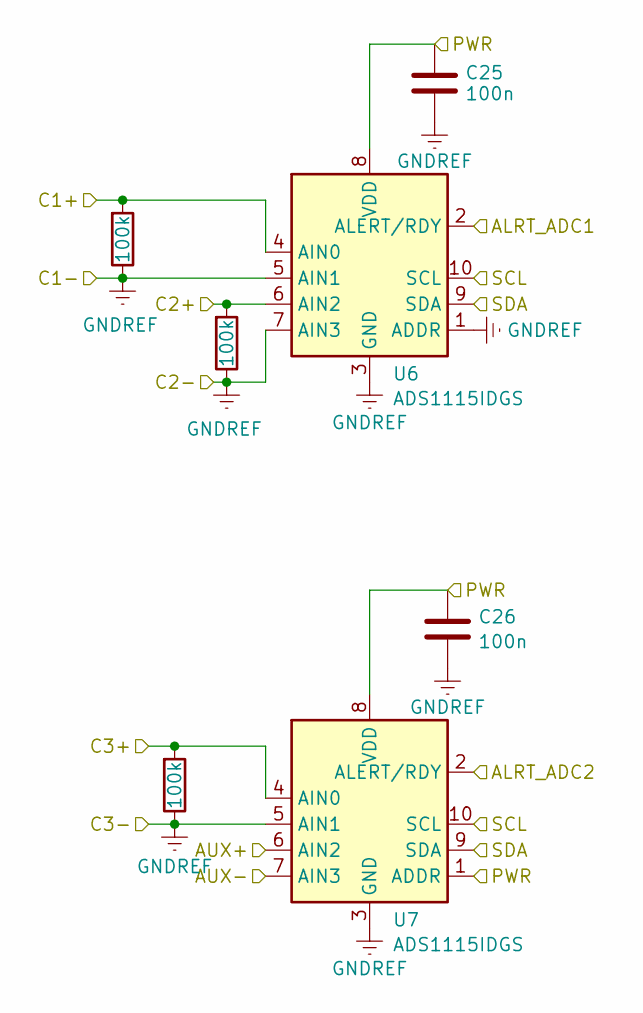
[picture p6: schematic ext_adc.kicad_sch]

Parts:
C25, C26: 100n; C_0603_1608Metric; MPN C14663
R13, R14, R15: 100k; R_0402_1005Metric; MPN C25741
U6, U7: ADS1115IDGS; TSSOP-10_3x3mm_P0.5mm; JLC C468683

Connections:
/ALRT_ADC1: U6.2 (ALERT/RDY); also elsewhere on the board
/ALRT_ADC2: U7.2 (ALERT/RDY); also elsewhere on the board
/AUX+: U7.6 (AIN2)
/AUX-: U7.7 (AIN3)
/C1+: R15.2, U6.4 (AIN0); also elsewhere on the board
/C2+: R14.2, U6.6 (AIN2); also elsewhere on the board
/C3+: R13.2, U7.4 (AIN0); also elsewhere on the board
/SCL: U6.10 (SCL), U7.10 (SCL); also elsewhere on the board
/SDA: U6.9 (SDA), U7.9 (SDA); also elsewhere on the board
GNDREF: C25.2, C26.2, R13.1, R14.1, R15.1, U6.1 (ADDR), U6.3 (GND), U6.5 (AIN1), U6.7 (AIN3), U7.3 (GND), U7.5 (AIN1); also elsewhere on the board
VBUS: C25.1, C26.1, U6.8 (VDD), U7.1 (ADDR), U7.8 (VDD); also elsewhere on the board

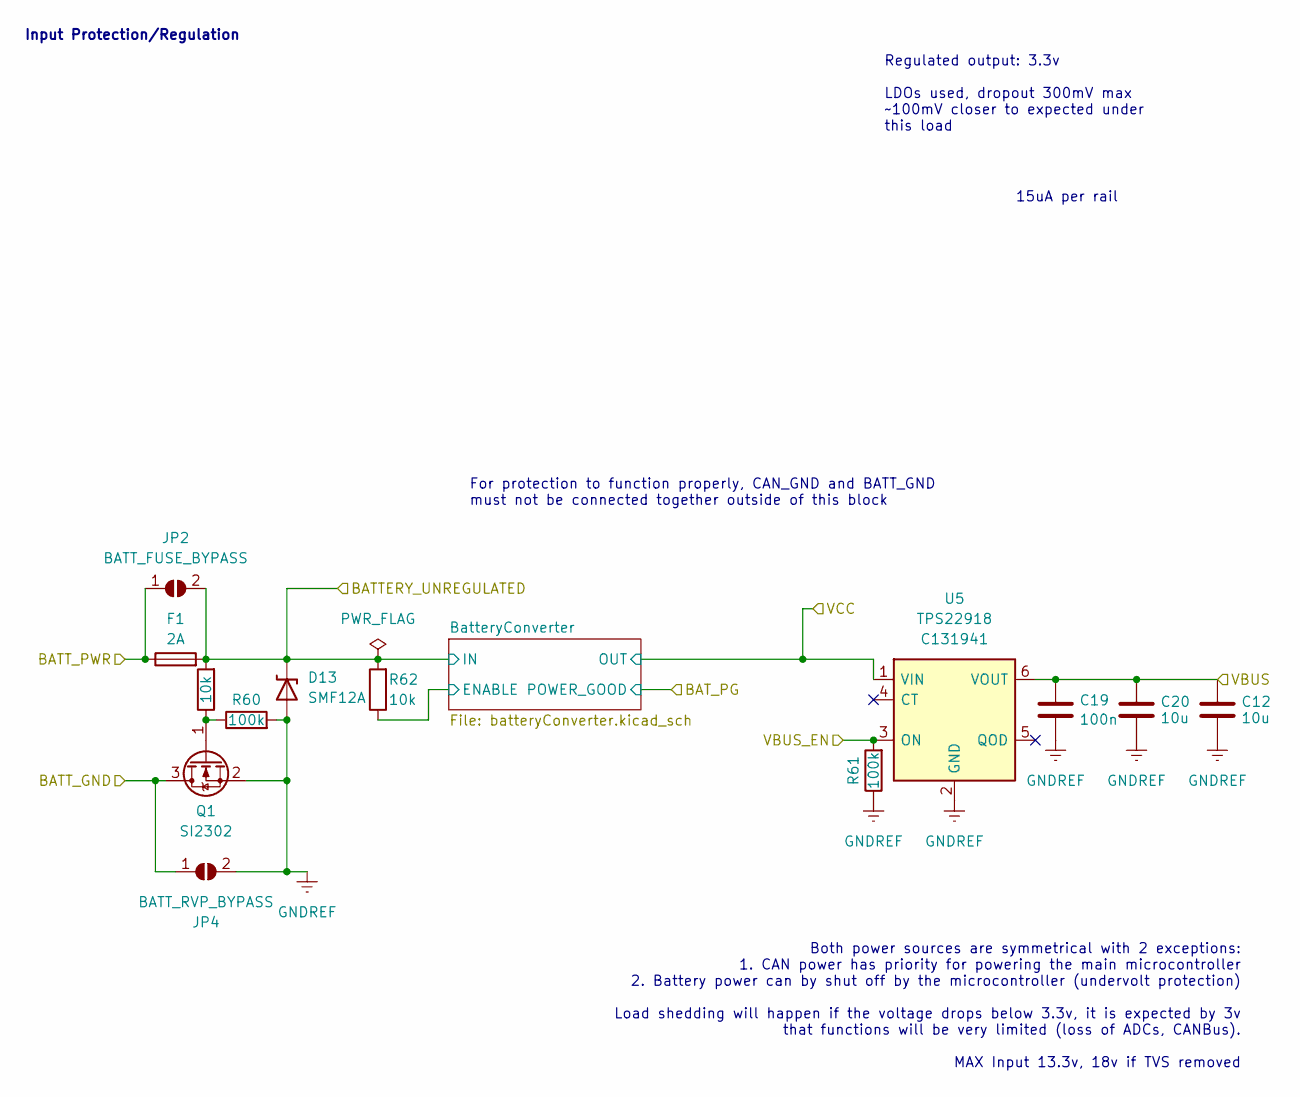
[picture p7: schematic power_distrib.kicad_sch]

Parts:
C12, C20: 10u; C_0603_1608Metric; MPN C96446
C19: 100n; C_0603_1608Metric; MPN C14663
D13: SMF12A; D_SOD-123F; MPN C178259
F1: 2A; Fuseholder_Littelfuse_Nano2_154x; MPN C108518
JP2: BATT_FUSE_BYPASS; SolderJumper-2_P1.3mm_Open_TrianglePad1.0x1.5mm
JP4: BATT_RVP_BYPASS; SolderJumper-2_P1.3mm_Open_TrianglePad1.0x1.5mm
Q1: SI2302; SOT-23; MPN C181087; JlcRotOffset 180
R58, R62: 10k; R_0402_1005Metric; MPN C25744
R60, R61: 100k; R_0402_1005Metric; MPN C25741
U5: TPS22918; SOT-23-6; JLC Part # C131941

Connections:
/BATTERY: F1.1, JP2.1 (A); also elsewhere on the board
/CAN_PWR: D13.1 (A1), F1.2, JP2.2 (B), R58.2, R62.2; also elsewhere on the board
/Power Distribution/BATT_GND: JP4.1 (A), Q1.3 (D); also elsewhere on the board
/Power Distribution/BatteryConverter/ENABLE: R62.1; also elsewhere on the board
/VBUS_EN: R61.2, U5.3 (ON); also elsewhere on the board
GNDREF: C12.2, C19.2, C20.2, D13.2 (A2), JP4.2 (B), Q1.2 (S), R60.2, R61.1, U5.2 (GND); also elsewhere on the board
unnamed: Q1.1 (G), R58.1, R60.1
VBUS: C12.1, C19.1, C20.1, U5.6 (VOUT); also elsewhere on the board
VCC: U5.1 (VIN); also elsewhere on the board

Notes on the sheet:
Both power sources are symmetrical with 2 exceptions: 1. CAN power has priority for powering the main microcontroller 2. Battery power can by shut off by the microcontroller (undervolt protection) Load shedding will happen if the voltage drops below 3.3v, it is expected by 3v that functions will be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
15uA per rail
Input Protection/Regulation
Regulated output: 3.3v LDOs used, dropout 300mV max ~100mV closer to expected under this load
For protection to function properly, CAN_GND and BATT_GND must not be connected together outside of this block

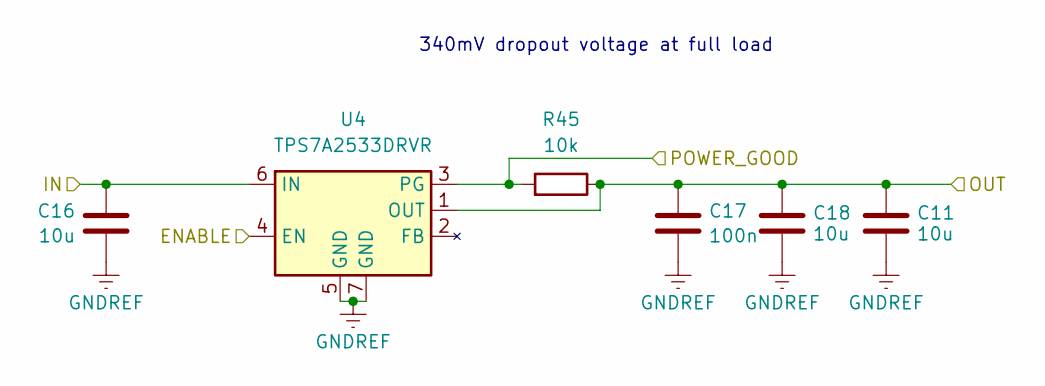
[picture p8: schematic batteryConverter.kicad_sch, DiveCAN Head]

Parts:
C11, C16, C18: 10u; C_0603_1608Metric; MPN C96446
C17: 100n; C_0603_1608Metric; MPN C14663
R45: 10k; R_0402_1005Metric; MPN C25744
U4: TPS7A2533DRVR; WSON-6-1EP_2x2mm_P0.65mm_EP1x1.6mm_ThermalVias; MPN C2867820; JlcRotOffset 0

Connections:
/CAN_PWR: C16.1, U4.6 (IN); also elsewhere on the board
/Power Distribution/BAT_PG: R45.2, U4.3 (PG)
/Power Distribution/BatteryConverter/ENABLE: U4.4 (EN); also elsewhere on the board
GNDREF: C11.2, C16.2, C17.2, C18.2, U4.5 (GND), U4.7 (GND); also elsewhere on the board
VCC: C11.1, C17.1, C18.1, R45.1, U4.1 (OUT); also elsewhere on the board

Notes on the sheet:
340mV dropout voltage at full load

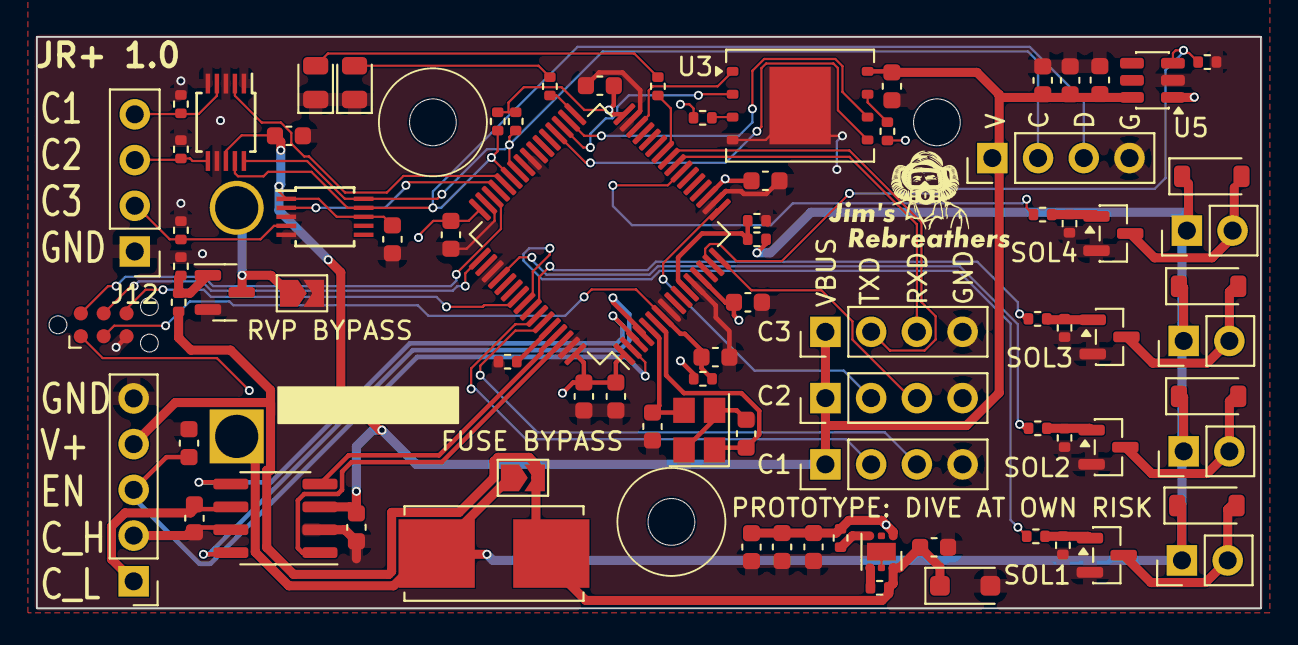
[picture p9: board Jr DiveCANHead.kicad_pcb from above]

Board: 2 copper layers, 68.0 x 31.7 mm, 83 parts (1 on the bottom side), 60 nets.

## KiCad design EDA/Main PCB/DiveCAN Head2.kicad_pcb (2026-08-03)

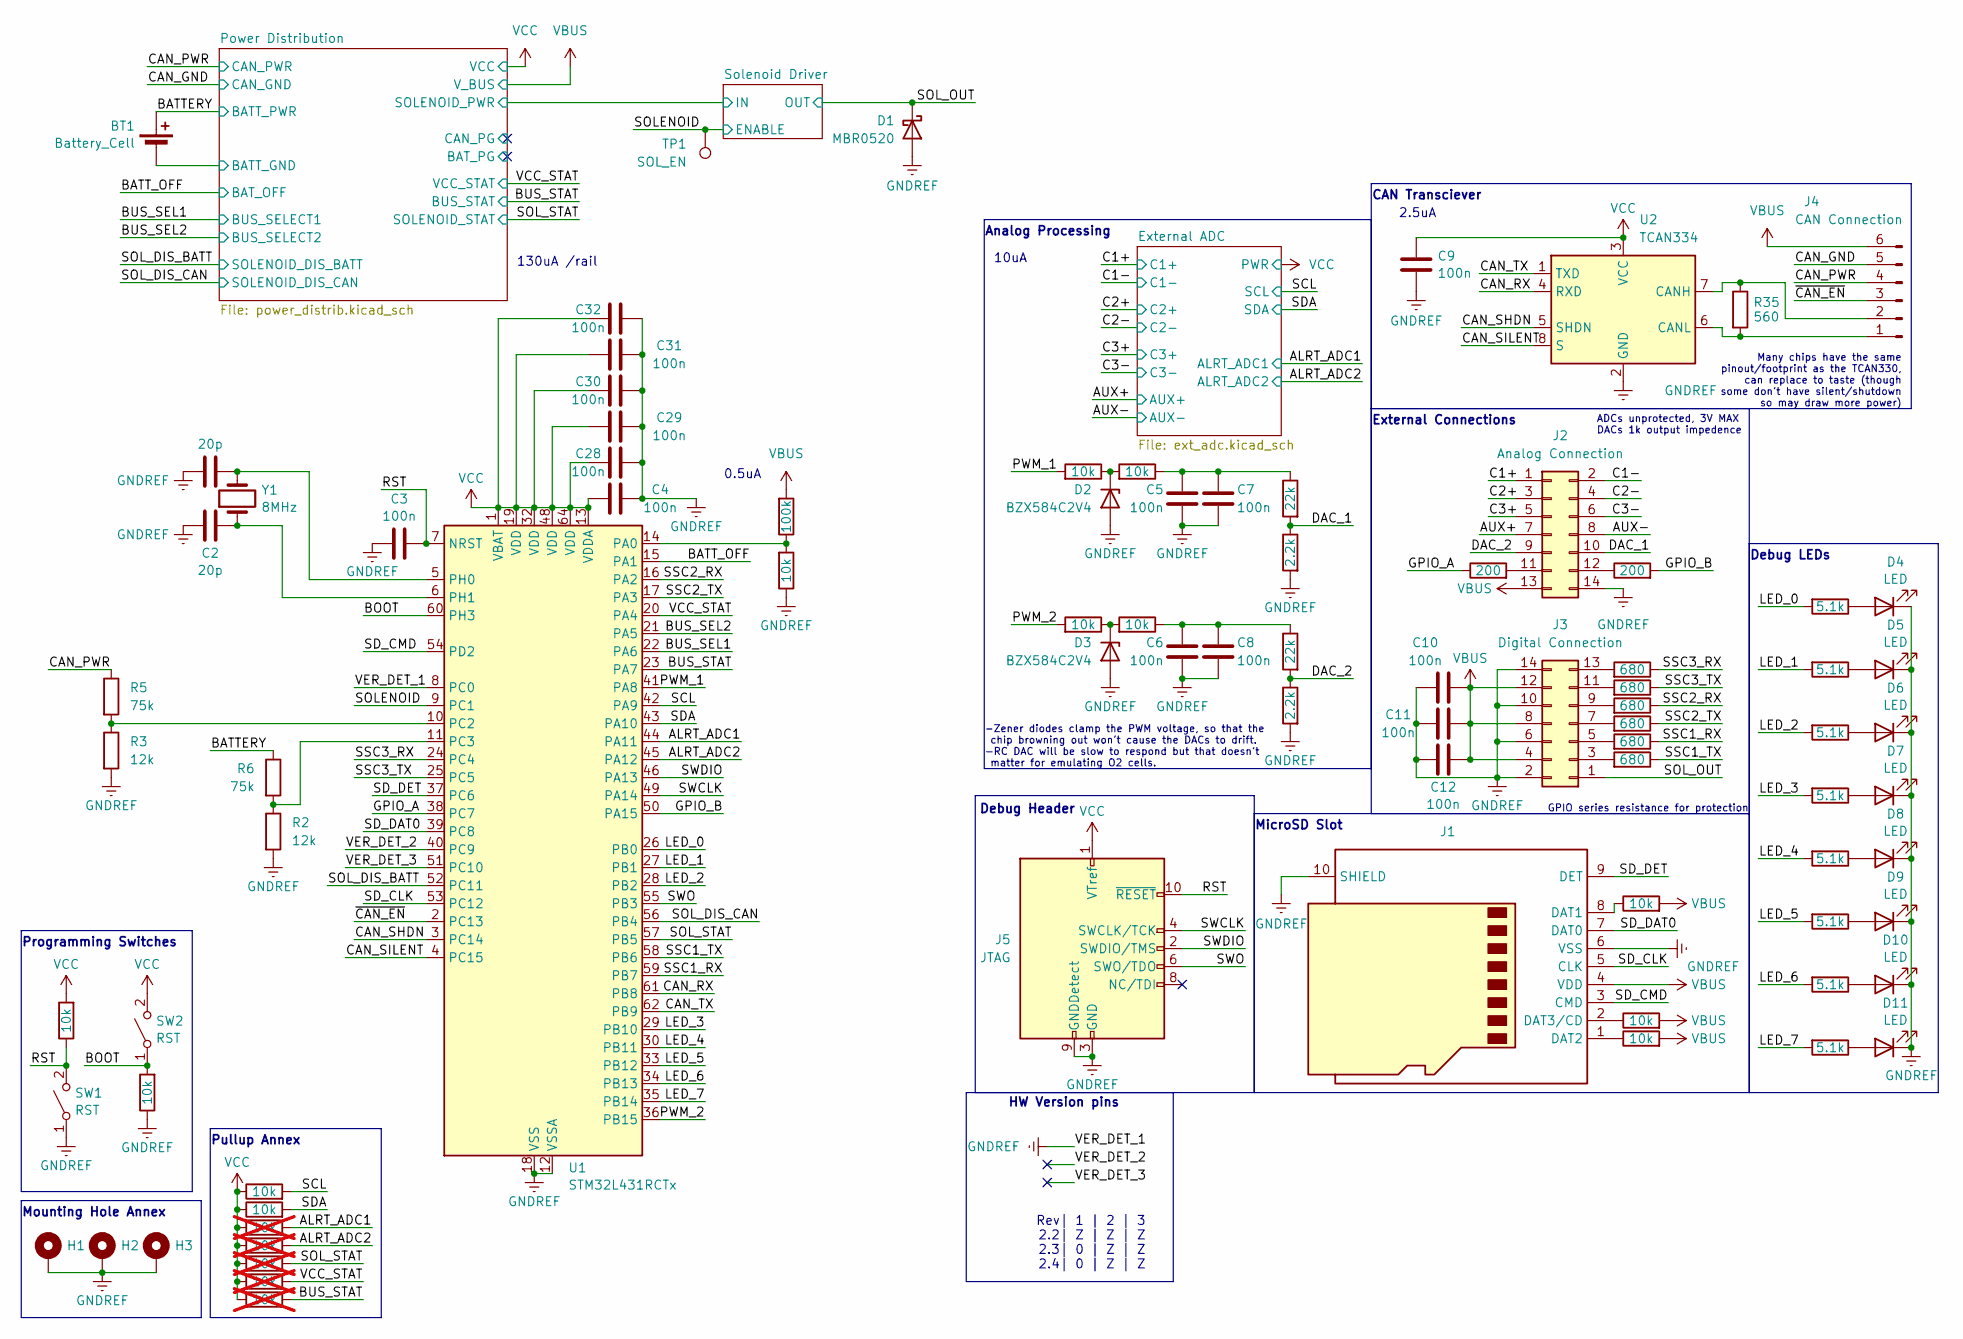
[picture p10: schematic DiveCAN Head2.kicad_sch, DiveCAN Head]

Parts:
BT1: Battery_Cell; PinHeader_1x02_P2.54mm_Horizontal
C1, C2: 20p; C_0603_1608Metric; MPN C325469
C3, C4, C5, C6, C7, C8, C9, C10, C11, C12, C28, C29, C30, C31, C32: 100n; C_0603_1608Metric; MPN C14663
D1: MBR0520; D_SOD-123; MPN C5204745
D2, D3: BZX584C2V4; D_SOD-523; MPN C968191
D4, D5, D6, D7, D8, D9, D10, D11: LED; LED_0805_2012Metric; MPN C84256
H1, H2, H3: MountingHole_Pad; MountingHole_3.2mm_M3_Pad
J1: Micro_SD_Card_Det1; CONN9_0185-02_GSW; MPN C5155564
J2: Analog Connection; IDC-Header_2x07_P2.54mm_Vertical
J3: Digital Connection; IDC-Header_2x07_P2.54mm_Vertical
J4: CAN Connection; PinHeader_1x06_P2.54mm_Horizontal
J5: JTAG; CON10_2X5_DUK_FTSH_SAI; MPN C448647
R1, R4, R7, R8, R15, R16, R17, R18, R19, R32, R33, R34: 10k; R_0402_1005Metric; MPN C25744
R2, R3: 12k; R_0402_1005Metric; MPN C25752
R5, R6: 75k; R_0402_1005Metric; MPN C25798
R9, R10, R11, R12, R13: 10k; R_0402_1005Metric; MPN C25744; not fitted
R14: 100k; R_0402_1005Metric; MPN C25741
R20, R22: 22k; R_0402_1005Metric; MPN C25768
R21, R23: 2.2k; R_0402_1005Metric; MPN C25879
R24, R25: 200; R_0402_1005Metric; MPN C25087
R26, R27, R28, R29, R30, R31: 680; R_0402_1005Metric; MPN C25130
R35: 560; R_0603_1608Metric; MPN C23204
R36, R37, R38, R39, R40, R41, R42, R43: 5.1k; R_0402_1005Metric; MPN C25905
SW1, SW2: RST; SW_SPST_EVQPE1; MPN C2915176
TP1: SOL_EN; TestPoint_THTPad_D1.0mm_Drill0.5mm
U1: STM32L431RCTx; LQFP-64_10x10mm_P0.5mm; JLC C92468
U2: TCAN334; SOIC-8_3.9x4.9mm_P1.27mm; MPN C2871143; JlcRotOffset -90
Y1: 8MHz; Crystal_SMD_HC49-SD; MPN C963524

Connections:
/ALRT_ADC1: R9.2, U1.44 (PA11); also elsewhere on the board
/ALRT_ADC2: R10.2, U1.45 (PA12); also elsewhere on the board
/AUX+: J2.7; also elsewhere on the board
/AUX-: J2.8; also elsewhere on the board
/BATTERY: BT1.1 (+), R6.1; also elsewhere on the board
/BATT_OFF: U1.15 (PA1); also elsewhere on the board
/BOOT: R4.2, SW2.1 (A), U1.60 (PH3)
/BUS_SEL1: U1.22 (PA6); also elsewhere on the board
/BUS_SEL2: U1.21 (PA5); also elsewhere on the board
/BUS_STAT: R13.2, U1.23 (PA7); also elsewhere on the board
/C1+: J2.1; also elsewhere on the board
/C1-: J2.2; also elsewhere on the board
/C2+: J2.3; also elsewhere on the board
/C2-: J2.4; also elsewhere on the board
/C3+: J2.5; also elsewhere on the board
/C3-: J2.6; also elsewhere on the board
/CAN_GND: J4.5; also elsewhere on the board
/CAN_PWR: J4.4, R5.1; also elsewhere on the board
/CAN_RX: U1.61 (PB8), U2.4 (RXD)
/CAN_SHDN: U1.3 (PC14), U2.5 (SHDN)
/CAN_SILENT: U1.4 (PC15), U2.8 (S)
/CAN_TX: U1.62 (PB9), U2.1 (TXD)
/DAC_1: J2.10, R20.2, R21.1
/DAC_2: J2.9, R22.2, R23.1
/GPIO_A: R24.1, U1.38 (PC7)
/GPIO_B: R25.2, U1.50 (PA15)
/LED_0: R36.2, U1.26 (PB0)
/LED_1: R37.2, U1.27 (PB1)
/LED_2: R38.2, U1.28 (PB2)
/LED_3: R39.2, U1.29 (PB10)
/LED_4: R40.2, U1.30 (PB11)
/LED_5: R41.2, U1.33 (PB12)
/LED_6: R42.2, U1.34 (PB13)
/LED_7: R43.2, U1.35 (PB14)
/PWM_1: R16.2, U1.41 (PA8)
/PWM_2: R17.2, U1.36 (PB15)
/Power Distribution/BATT_GND: BT1.2 (-); also elsewhere on the board
/RST: C3.2, J5.10 (~RESET), R1.1, SW1.2 (B), U1.7 (NRST)
/SCL: R7.2, U1.42 (PA9); also elsewhere on the board
/SDA: R8.2, U1.43 (PA10); also elsewhere on the board
/SD_CLK: J1.5 (CLK), U1.53 (PC12)
/SD_CMD: J1.3 (CMD), U1.54 (PD2)
/SD_DAT0: J1.7 (DAT0), U1.39 (PC8)
/SD_DET: J1.9 (DET), U1.37 (PC6)
/SOLENOID: TP1.1, U1.9 (PC1); also elsewhere on the board
/SOL_DIS_BATT: U1.52 (PC11); also elsewhere on the board
/SOL_DIS_CAN: U1.56 (PB4); also elsewhere on the board
/SOL_OUT: D1.1 (K), J3.1; also elsewhere on the board
/SOL_STAT: R11.2, U1.57 (PB5); also elsewhere on the board
/SSC1_RX: R30.1, U1.59 (PB7)
/SSC1_TX: R31.1, U1.58 (PB6)
/SSC2_RX: R28.1, U1.16 (PA2)
/SSC2_TX: R29.1, U1.17 (PA3)
/SSC3_RX: R26.1, U1.24 (PC4)
/SSC3_TX: R27.1, U1.25 (PC5)
/SWCLK: J5.4 (SWCLK/TCK), U1.49 (PA14)
/SWDIO: J5.2 (SWDIO/TMS), U1.46 (PA13)
/SWO: J5.6 (SWO/TDO), U1.55 (PB3)
/VCC_STAT: R12.2, U1.20 (PA4); also elsewhere on the board
/VER_DET_2: U1.40 (PC9)
/VER_DET_3: U1.51 (PC10)
/~CAN_EN: J4.3, U1.2 (PC13)
GNDREF: C1.1, C2.1, C3.1, C4.1, C5.1, C6.1, C7.1, C8.1, C9.2, C10.1, C11.1, C12.1, C28.1, C29.1, C30.1, C31.1, C32.1, D1.2 (A), D2.2 (A), D3.2 (A), D4.1 (K), D5.1 (K), D6.1 (K), D7.1 (K), D8.1 (K), D9.1 (K), D10.1 (K), D11.1 (K), H1.1, H2.1, H3.1, J1.6 (VSS), J1.10 (SHIELD), J2.14, J3.2, J3.6, J3.10, J3.14, J5.3 (GND), J5.5 (GND), J5.9 (GNDDetect), R2.2, R3.2, R4.1, R15.1, R21.2, R23.2, SW1.1 (A), U1.8 (PC0), U1.12 (VSSA), U1.18 (VSS), U1.31 (VSS), U1.47 (VSS), U1.63 (VSS), U2.2 (GND); also elsewhere on the board
unnamed: C5.2, C7.2, R18.1, R20.1
unnamed: C6.2, C8.2, R19.1, R22.1
unnamed: D2.1 (K), R16.1, R18.2
unnamed: D3.1 (K), R17.1, R19.2
unnamed: D4.2 (A), R36.1
unnamed: D5.2 (A), R37.1
unnamed: D6.2 (A), R38.1
unnamed: D7.2 (A), R39.1
unnamed: D8.2 (A), R40.1
unnamed: D9.2 (A), R41.1
unnamed: D10.2 (A), R42.1
unnamed: D11.2 (A), R43.1
unnamed: J1.8 (DAT1), R32.1
unnamed: J1.1 (DAT2), R34.1
unnamed: J1.2 (DAT3/CD), R33.1
unnamed: J2.11, R24.2
unnamed: J2.12, R25.1
unnamed: J3.3, R31.2
unnamed: J3.5, R30.2
unnamed: J3.7, R29.2
unnamed: J3.9, R28.2
unnamed: J3.11, R27.2
unnamed: J3.13, R26.2
unnamed: J4.1, R35.2, U2.6 (CANL)
unnamed: J4.2, R35.1, U2.7 (CANH)
unnamed: R14.1, R15.2, U1.14 (PA0)
unnamed: R3.1, R5.2, U1.10 (PC2)
unnamed: R2.1, R6.2, U1.11 (PC3)
unnamed: C1.2, U1.5 (PH0), Y1.2
unnamed: C2.2, U1.6 (PH1), Y1.1
VBUS: C10.2, C11.2, C12.2, J1.4 (VDD), J2.13, J3.4, J3.8, J3.12, J4.6, R14.2, R32.2, R33.2, R34.2; also elsewhere on the board
VCC: C4.2, C9.1, C28.2, C29.2, C30.2, C31.2, C32.2, J5.1 (VTref), R1.2, R7.1, R8.1, R9.1, R10.1, R11.1, R12.1, R13.1, SW2.2 (B), U1.1 (VBAT), U1.13 (VDDA), U1.19 (VDD), U1.32 (VDD), U1.48 (VDD), U1.64 (VDD), U2.3 (VCC); also elsewhere on the board

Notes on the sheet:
10uA
Many chips have the same pinout/footprint as the TCAN330, can replace to taste (though some don't have silent/shutdown so may draw more power)
HW Version pins
MicroSD Slot
Mounting Hole Annex
Pullup Annex
External Connections
ADCs unprotected, 3V MAX DACs 1k output impedence
Programming Switches
Debug LEDs
0.5uA
GPIO series resistance for protection
Rev| 1 | 2 | 3 2.2| Z | Z | Z 2.3| 0 | Z | Z 2.4| 0 | Z | Z
-Zener diodes clamp the PWM voltage, so that the chip browning out won't cause the DACs to drift. -RC DAC will be slow to respond but that doesn't matter for emulating O2 cells.
CAN Transciever
Debug Header
Analog Processing
2.5uA
130uA /rail

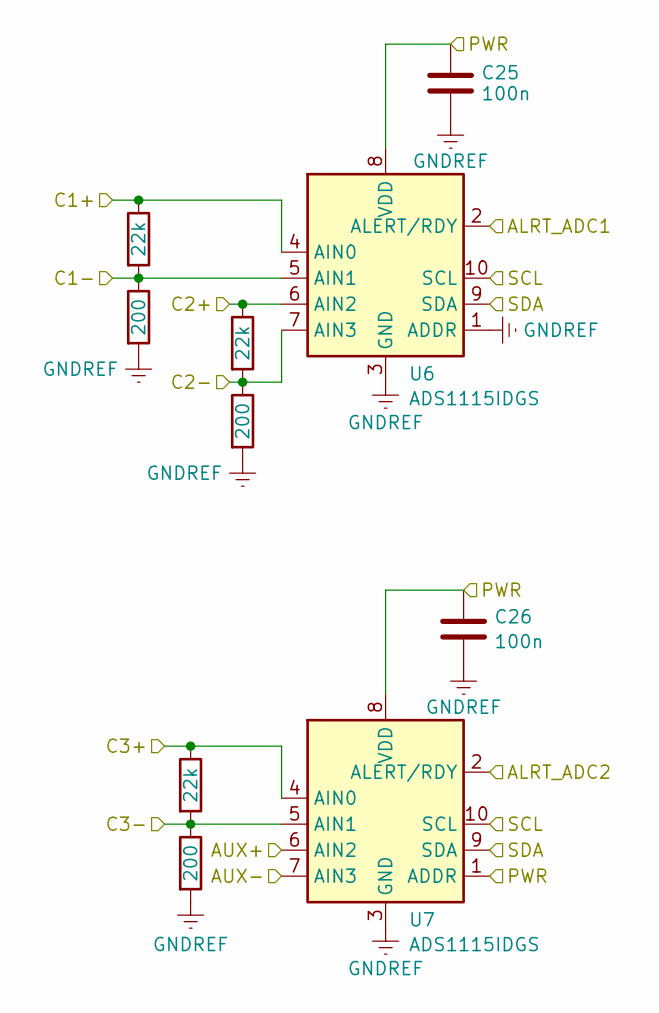
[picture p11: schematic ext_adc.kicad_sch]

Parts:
C25, C26: 100n; C_0603_1608Metric; MPN C14663
R52, R54, R56: 22k; R_0402_1005Metric; MPN C25768
R53, R55, R57: 200; R_0402_1005Metric; MPN C25087
U6, U7: ADS1115IDGS; TSSOP-10_3x3mm_P0.5mm; JLC C37593

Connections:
/ALRT_ADC1: U6.2 (ALERT/RDY); also elsewhere on the board
/ALRT_ADC2: U7.2 (ALERT/RDY); also elsewhere on the board
/AUX+: U7.6 (AIN2); also elsewhere on the board
/AUX-: U7.7 (AIN3); also elsewhere on the board
/C1+: R52.1, U6.4 (AIN0); also elsewhere on the board
/C1-: R52.2, R53.1, U6.5 (AIN1); also elsewhere on the board
/C2+: R56.1, U6.6 (AIN2); also elsewhere on the board
/C2-: R56.2, R57.1, U6.7 (AIN3); also elsewhere on the board
/C3+: R54.1, U7.4 (AIN0); also elsewhere on the board
/C3-: R54.2, R55.1, U7.5 (AIN1); also elsewhere on the board
/SCL: U6.10 (SCL), U7.10 (SCL); also elsewhere on the board
/SDA: U6.9 (SDA), U7.9 (SDA); also elsewhere on the board
GNDREF: C25.2, C26.2, R53.2, R55.2, R57.2, U6.1 (ADDR), U6.3 (GND), U7.3 (GND); also elsewhere on the board
VCC: C25.1, C26.1, U6.8 (VDD), U7.1 (ADDR), U7.8 (VDD); also elsewhere on the board

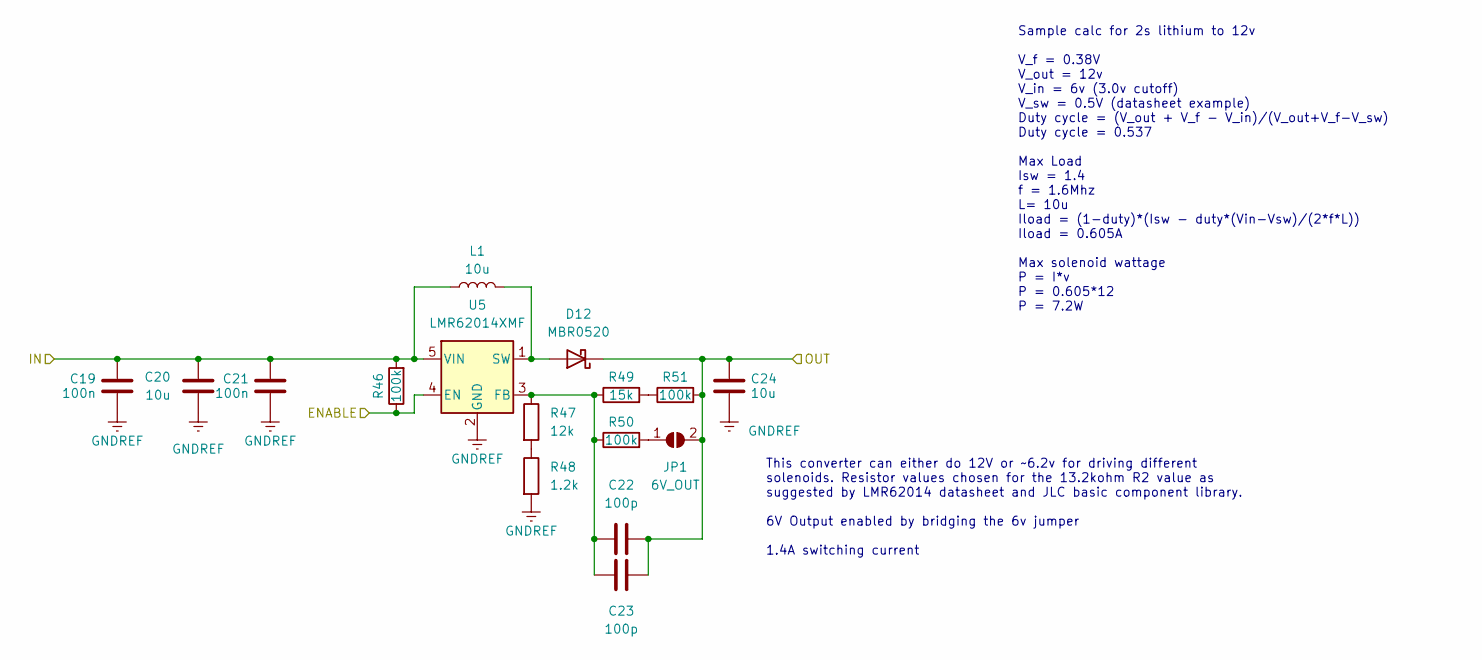
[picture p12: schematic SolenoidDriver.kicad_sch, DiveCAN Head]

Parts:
C19, C21: 100n; C_0603_1608Metric; MPN C14663
C20, C24: 10u; C_0603_1608Metric; MPN C96446
C22, C23: 100p; C_0402_1005Metric; MPN C1546
D12: MBR0520; D_SOD-123; MPN C5204745
JP1: 6V_OUT; SolderJumper-2_P1.3mm_Open_TrianglePad1.0x1.5mm
L1: 10u; L_SunItech_SLO0530H; MPN C325966
R46, R50, R51: 100k; R_0402_1005Metric; MPN C25741
R47: 12k; R_0402_1005Metric; MPN C25752
R48: 1.2k; R_0402_1005Metric; MPN C25862
R49: 15k; R_0402_1005Metric; MPN C25756
U5: LMR62014XMF; SOT-23-5; MPN C468235

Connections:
/Power Distribution/SOLENOID_PWR: C19.2, C20.1, C21.2, L1.1, R46.2, U5.5 (VIN); also elsewhere on the board
/SOLENOID: R46.1, U5.4 (EN); also elsewhere on the board
/SOL_OUT: C22.1, C23.1, C24.1, D12.1 (K), JP1.2 (B), R51.2; also elsewhere on the board
GNDREF: C19.1, C20.2, C21.1, C24.2, R48.2, U5.2 (GND); also elsewhere on the board
unnamed: D12.2 (A), L1.2, U5.1 (SW)
unnamed: JP1.1 (A), R50.2
unnamed: R47.2, R48.1
unnamed: R49.2, R51.1
unnamed: C22.2, C23.2, R47.1, R49.1, R50.1, U5.3 (FB)

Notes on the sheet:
Sample calc for 2s lithium to 12v V_f = 0.38V V_out = 12v V_in = 6v (3.0v cutoff) V_sw = 0.5V (datasheet example) Duty cycle = (V_out + V_f - V_in)/(V_out+V_f-V_sw) Duty cycle = 0.537 Max Load Isw = 1.4 f = 1.6Mhz L= 10u Iload = (1-duty)*(Isw - duty*(Vin-Vsw)/(2*f*L)) Iload = 0.605A Max solenoid wa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
This converter can either do 12V or ~6.2v for driving different solenoids. Resistor values chosen for the 13.2kohm R2 value as suggested by LMR62014 datasheet and JLC basic component library. 6V Output enabled by bridging the 6v jumper 1.4A switching current

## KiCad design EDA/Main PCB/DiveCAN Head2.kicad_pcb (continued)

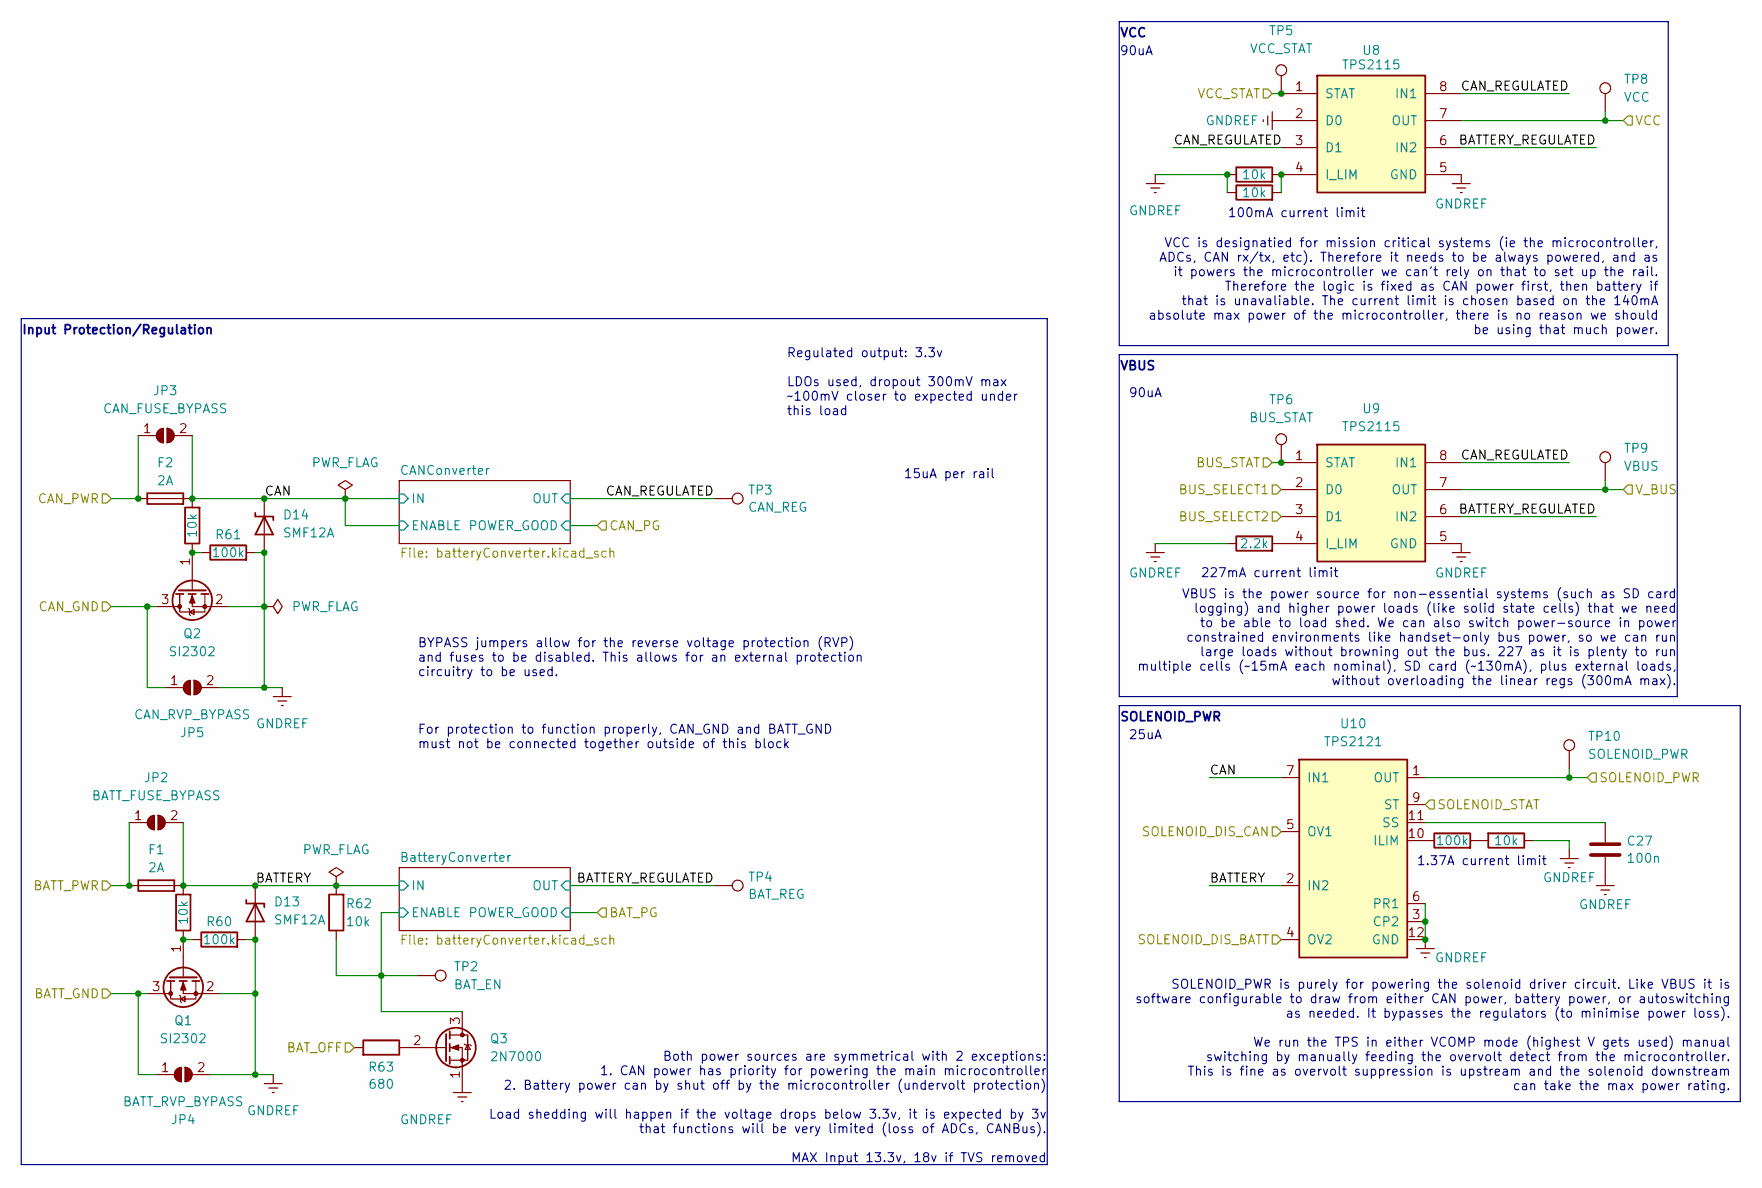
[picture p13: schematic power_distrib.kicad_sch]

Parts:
C27: 100n; C_0603_1608Metric; MPN C14663
D13, D14: SMF12A; D_SOD-123F; MPN C178259
F1, F2: 2A; Fuseholder_Littelfuse_Nano2_154x; MPN C108518
JP2: BATT_FUSE_BYPASS; SolderJumper-2_P1.3mm_Open_TrianglePad1.0x1.5mm
JP3: CAN_FUSE_BYPASS; SolderJumper-2_P1.3mm_Open_TrianglePad1.0x1.5mm
JP4: BATT_RVP_BYPASS; SolderJumper-2_P1.3mm_Open_TrianglePad1.0x1.5mm
JP5: CAN_RVP_BYPASS; SolderJumper-2_P1.3mm_Open_TrianglePad1.0x1.5mm
Q1, Q2: SI2302; SOT-23; MPN C181087; JlcRotOffset 180
Q3: 2N7000; SOT-23; MPN C8545; JlcRotOffset 180
R58, R59, R62, R65, R66, R70: 10k; R_0402_1005Metric; MPN C25744
R60, R61, R69: 100k; R_0402_1005Metric; MPN C25741
R63: 680; R_0402_1005Metric; MPN C25130
R67: 2.2k; R_0402_1005Metric; MPN C25879
TP2: BAT_EN; TestPoint_THTPad_D1.0mm_Drill0.5mm
TP3: CAN_REG; TestPoint_THTPad_D1.0mm_Drill0.5mm
TP4: BAT_REG; TestPoint_THTPad_D1.0mm_Drill0.5mm
TP5: VCC_STAT; TestPoint_THTPad_D1.0mm_Drill0.5mm
TP6: BUS_STAT; TestPoint_THTPad_D1.0mm_Drill0.5mm
TP8: VCC; TestPoint_THTPad_D1.0mm_Drill0.5mm
TP9: VBUS; TestPoint_THTPad_D1.0mm_Drill0.5mm
TP10: SOLENOID_PWR; TestPoint_THTPad_D1.0mm_Drill0.5mm
U8, U9: TPS2115; VSON-8_3.3x3.3mm_P0.65mm_NexFET; MPN C140321; JLCPCB Rotation Offset 90
U10: TPS2121; Texas_VQFN-HR-12_2x2.5mm_P0.5mm; JLC Part # C485916

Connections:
/BATTERY: F1.1, JP2.1 (A); also elsewhere on the board
/BATT_OFF: R63.2; also elsewhere on the board
/BUS_SEL1: U9.2 (D0); also elsewhere on the board
/BUS_SEL2: U9.3 (D1); also elsewhere on the board
/BUS_STAT: TP6.1, U9.1 (STAT); also elsewhere on the board
/CAN_GND: JP5.1 (A), Q2.3 (D); also elsewhere on the board
/CAN_PWR: F2.1, JP3.1 (A); also elsewhere on the board
/Power Distribution/BATTERY: D13.1 (A1), F1.2, JP2.2 (B), R58.2, R62.2, U10.2 (IN2); also elsewhere on the board
/Power Distribution/BATTERY_REGULATED: TP4.1, U8.6 (IN2), U9.6 (IN2); also elsewhere on the board
/Power Distribution/BATT_GND: JP4.1 (A), Q1.3 (D); also elsewhere on the board
/Power Distribution/BatteryConverter/ENABLE: Q3.3 (D), R62.1, TP2.1; also elsewhere on the board
/Power Distribution/CAN: D14.1 (A1), F2.2, JP3.2 (B), R59.2, U10.7 (IN1); also elsewhere on the board
/Power Distribution/CAN_REGULATED: TP3.1, U8.3 (D1), U8.8 (IN1), U9.8 (IN1); also elsewhere on the board
/Power Distribution/SOLENOID_PWR: TP10.1, U10.1 (OUT), U10.8 (OUT); also elsewhere on the board
/SOL_DIS_BATT: U10.4 (OV2); also elsewhere on the board
/SOL_DIS_CAN: U10.5 (OV1); also elsewhere on the board
/SOL_STAT: U10.9 (ST); also elsewhere on the board
/VCC_STAT: TP5.1, U8.1 (STAT); also elsewhere on the board
GNDREF: C27.2, D13.2 (A2), D14.2 (A2), JP4.2 (B), JP5.2 (B), Q1.2 (S), Q2.2 (S), Q3.1 (S), R60.2, R61.2, R65.1, R66.1, R67.1, R70.1, U8.2 (D0), U8.5 (GND), U9.5 (GND), U10.3 (CP2), U10.6 (PR1), U10.12 (GND); also elsewhere on the board
unnamed: Q1.1 (G), R58.1, R60.1
unnamed: Q2.1 (G), R59.1, R61.1
unnamed: Q3.2 (G), R63.1
unnamed: R69.2, R70.2
unnamed: R65.2, R66.2, U8.4 (I_LIM)
unnamed: R67.2, U9.4 (I_LIM)
unnamed: R69.1, U10.10 (ILIM)
unnamed: C27.1, U10.11 (SS)
VBUS: TP9.1, U9.7 (OUT); also elsewhere on the board
VCC: TP8.1, U8.7 (OUT); also elsewhere on the board

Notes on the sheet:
Both power sources are symmetrical with 2 exceptions: 1. CAN power has priority for powering the main microcontroller 2. Battery power can by shut off by the microcontroller (undervolt protection) Load shedding will happen if the voltage drops below 3.3v, it is expected by 3v that functions will be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
SOLENOID_PWR
25uA
VBUS is the power source for non-essential systems (such as SD card logging) and higher power loads (like solid state cells) that we need to be able to load shed. We can also switch power-source in power constrained environments like handset-only bus power, so we can run large loads without brownin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
15uA per rail
100mA current limit
90uA
Input Protection/Regulation
227mA current limit
VCC is designatied for mission critical systems (ie the microcontroller, ADCs, CAN rx/tx, etc). Therefore it needs to be always powered, and as it powers the microcontroller we can't rely on that to set up the rail. Therefore the logic is fixed as CAN power first, then battery if that is unavaliabl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
VCC
Regulated output: 3.3v LDOs used, dropout 300mV max ~100mV closer to expected under this load
VBUS
For protection to function properly, CAN_GND and BATT_GND must not be connected together outside of this block
1.37A current limit
BYPASS jumpers allow for the reverse voltage protection (RVP) and fuses to be disabled. This allows for an external protection circuitry to be used.
SOLENOID_PWR is purely for powering the solenoid driver circuit. Like VBUS it is software configurable to draw from either CAN power, battery power, or autoswitching as needed. It bypasses the regulators (to minimise power loss). We run the TPS in either VCOMP mode (highest V gets used) manual swit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

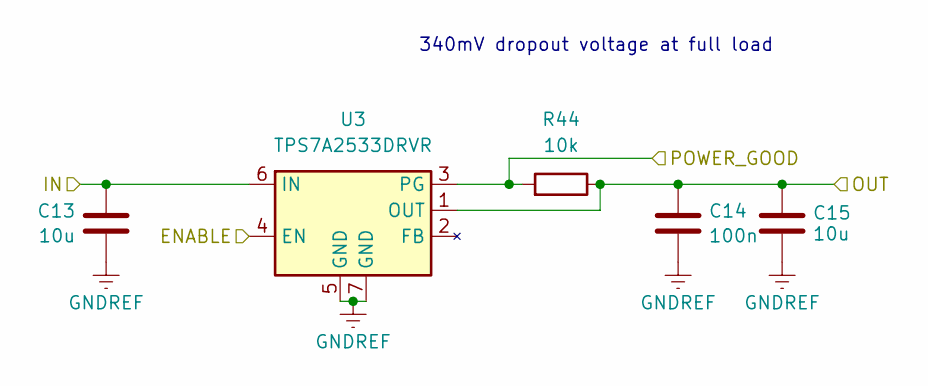
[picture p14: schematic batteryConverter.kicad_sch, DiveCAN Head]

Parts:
C13, C15: 10u; C_0603_1608Metric; MPN C96446
C14: 100n; C_0603_1608Metric; MPN C14663
R44: 10k; R_0402_1005Metric; MPN C25744
U3: TPS7A2533DRVR; WSON-6-1EP_2x2mm_P0.65mm_EP1x1.6mm_ThermalVias; MPN C2867820; JlcRotOffset 0

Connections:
/Power Distribution/CAN: C13.1, U3.4 (EN), U3.6 (IN); also elsewhere on the board
/Power Distribution/CAN_PG: R44.2, U3.3 (PG)
/Power Distribution/CAN_REGULATED: C14.1, C15.1, R44.1, U3.1 (OUT); also elsewhere on the board
GNDREF: C13.2, C14.2, C15.2, U3.5 (GND), U3.7 (GND); also elsewhere on the board

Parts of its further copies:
C16, C18: 10u; C_0603_1608Metric; MPN C96446
C17: 100n; C_0603_1608Metric; MPN C14663
R45: 10k; R_0402_1005Metric; MPN C25744
U4: TPS7A2533DRVR; WSON-6-1EP_2x2mm_P0.65mm_EP1x1.6mm_ThermalVias; MPN C2867820; JlcRotOffset 0

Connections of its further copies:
/Power Distribution/BATTERY: C16.1, U4.6 (IN); also elsewhere on the board
/Power Distribution/BATTERY_REGULATED: C17.1, C18.1, R45.1, U4.1 (OUT); also elsewhere on the board
/Power Distribution/BAT_PG: R45.2, U4.3 (PG)
/Power Distribution/BatteryConverter/ENABLE: U4.4 (EN); also elsewhere on the board
GNDREF: C16.2, C17.2, C18.2, U4.5 (GND), U4.7 (GND); also elsewhere on the board

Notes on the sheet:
340mV dropout voltage at full load

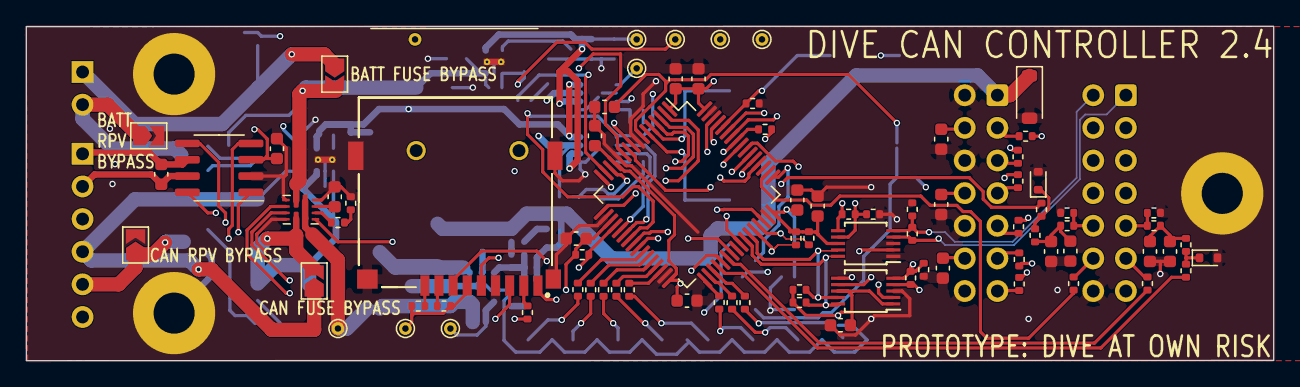
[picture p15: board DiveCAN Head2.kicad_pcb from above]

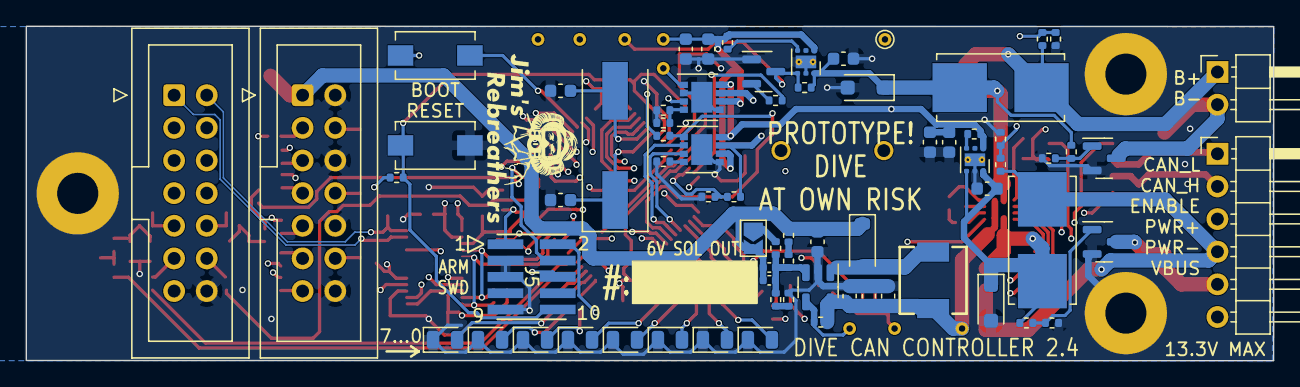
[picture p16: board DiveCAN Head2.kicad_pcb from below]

Board: 4 copper layers, 97.1 x 26.0 mm, 156 parts (71 on the bottom side), 114 nets.

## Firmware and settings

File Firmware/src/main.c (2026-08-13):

/**
 * @file main.c
 * @brief Application entry point — hardware init and heartbeat LED loop
 *
 * Validates CAN_EN after low-power wake, claims the shared enable line,
 * initialises calibration, then drives the heartbeat LED.
 * Cell threads and the consensus subscriber are auto-started via K_THREAD_DEFINE.
 */

#include <zephyr/kernel.h>
#include <zephyr/init.h>
#include <zephyr/drivers/gpio.h>
#include <zephyr/drivers/hwinfo.h>
#include <zephyr/version.h>
#include <zephyr/logging/log.h>
#include <zephyr/logging/log_ctrl.h>
#ifdef CONFIG_SOC_FAMILY_STM32
#include <stm32_ll_rcc.h>
#include <stm32_ll_system.h>
#include <stm32_ll_utils.h>
#endif

#include <math.h>
#include <stdarg.h>
#include <zephyr/sys/printk.h>

#include "calibration.h"
#include "power_management.h"
#include "ppo2_control.h"
#include "runtime_settings.h"
#include "error_histogram.h"
#include "errors.h"
#include "boot_history.h"
#include "common.h"
#include "firmware_confirm.h"
#include "watchdog_feeder.h"
#ifdef CONFIG_FACTORY_IMAGE
#include "factory_image.h"
#endif
#ifdef CONFIG_FLASH_LOG
#include "flash_log.h"
#endif
#ifdef CONFIG_POSEIDON_ACCESSORIES
#include "poseidon_accessories.h"
#endif

LOG_MODULE_REGISTER(main, LOG_LEVEL_INF);

#ifdef CONFIG_INTEGRATION_TEST_SHIM
/* Native-only seam implemented by tests/integration/src/test_shim.c. It lets
 * the integration harness exercise the real main() reset-source decision;
 * production images continue to read the SoC's hwinfo driver directly. */
Status_t test_shim_get_reset_cause(uint32_t *cause);
#endif

#define LED0_NODE DT_ALIAS(led0)

static const struct gpio_dt_spec led = GPIO_DT_SPEC_GET(LED0_NODE, gpios);

/* Startup delay before CAN bus check (ms) */
static const uint32_t STARTUP_DELAY_MS = 1000U;

/* Heartbeat LED blink period (ms) */
static const uint32_t BLINK_PERIOD_MS = 500U;

/* Post-preamble-line drain delay (ms) — see preamble_line() header comment. */
static const uint32_t PREAMBLE_LINE_DRAIN_MS = 50U;

/* Run before application threads are scheduled. The PPO2 broadcaster is an
 * auto-start thread, so doing this in main() is too late: an unsustained
 * WKUP2/CAN_EN pulse can otherwise emit a normal PPO2 frame before the legacy
 * one-second validation sends the head back to SHUTDOWN.
 */
static int startup_can_wake_guard(void)
{
    uint32_t reset_cause = 0U;
#ifdef CONFIG_INTEGRATION_TEST_SHIM
    Status_t reset_rc = test_shim_get_reset_cause(&reset_cause);
#else
    Status_t reset_rc = hwinfo_get_reset_cause(&reset_cause);
#endif

    if ((0 == reset_rc) && power_reset_requires_can_enable_check(reset_cause)) {
        k_busy_wait(STARTUP_DELAY_MS * 1000U);
        if (!power_is_can_active(POWER_DEVICE)) {
            LOG_WRN("CAN_EN wake was not sustained — entering shutdown");
#ifdef CONFIG_POSEIDON_ACCESSORIES
            poseidon_accessories_shutdown();
#endif
            (void)power_shutdown(POWER_DEVICE);
        }
    }

    return 0;
}

SYS_INIT(startup_can_wake_guard, APPLICATION, 1);

/**
 * @brief Toggle the heartbeat LED to mark forward progress through boot.
 *
 * Called between each init phase so the blink pattern IS the boot sequence —
 * each flash/NVS operation flips the LED, giving a visible cadence for free
 * (no k_msleep). A healthy boot shows a quick asymmetric flicker (short
 * phases flip fast, long phases hold longer) then the steady ~1 Hz heartbeat.
 * A stuck boot holds one state indefinitely, and a reset loop repeats the
 * same partial pattern, both obvious by eye.
 */
static bool *boot_led_ready(void)
{
    /* Accessor-wrapped per the heartbeat.c M23_388 pattern. */
    static bool ready;
    return &ready;
}

static void boot_led_init(void)
{
    if (device_is_ready(led.port)) {
        (void)gpio_pin_configure_dt(&led, GPIO_OUTPUT_ACTIVE);
        *boot_led_ready() = true;
    }
}

static void boot_led_toggle(void)
{
    if (*boot_led_ready()) {
        (void)gpio_pin_toggle_dt(&led);
    }
}

/* Max preamble line length (after format expansion). 128 fits the
 * longest expected line ("Solenoids: O2_inject=… O2_flush=… …") with
 * plenty of slack and stays well under MAIN_STACK_SIZE. */
#define PREAMBLE_LINE_BUF_SZ 128U

/* The boot preamble intentionally prints gains in compact x1000 display
 * units.  The editable UDS settings use x1M micro-units for finer precision.
 * Integer formatting avoids depending on cbprintf float support. */
#define PID_GAIN_DISPLAY_SCALE 1000

/* ---- Compile-time string projections ----
 *
 * Each Kconfig choice gets one #if/#elif chain that bakes the
 * human-readable string at preprocess time. The preamble emit code
 * then formats them as plain `%s`. Kept here (not in a header) because
 * these strings are only meaningful inside the preamble.
 */

#if defined(CONFIG_CELL_1_TYPE_ANALOG)
#define CELL_1_TYPE_STR "ANALOG"
#elif defined(CONFIG_CELL_1_TYPE_DIVEO2)
#define CELL_1_TYPE_STR "DIVEO2"
#elif defined(CONFIG_CELL_1_TYPE_O2S)
#define CELL_1_TYPE_STR "O2S"
#else
#define CELL_1_TYPE_STR "?"
#endif

#if defined(CONFIG_CELL_2_TYPE_ANALOG)
#define CELL_2_TYPE_STR "ANALOG"
#elif defined(CONFIG_CELL_2_TYPE_DIVEO2)
#define CELL_2_TYPE_STR "DIVEO2"
#elif defined(CONFIG_CELL_2_TYPE_O2S)
#define CELL_2_TYPE_STR "O2S"
#else
#define CELL_2_TYPE_STR "?"
#endif

#if defined(CONFIG_CELL_3_TYPE_ANALOG)
#define CELL_3_TYPE_STR "ANALOG"
#elif defined(CONFIG_CELL_3_TYPE_DIVEO2)
#define CELL_3_TYPE_STR "DIVEO2"
#elif defined(CONFIG_CELL_3_TYPE_O2S)
#define CELL_3_TYPE_STR "O2S"
#else
#define CELL_3_TYPE_STR "?"
#endif

#if defined(CONFIG_POWER_MODE_BATTERY)
#define POWER_MODE_STR "BATTERY"
#elif defined(CONFIG_POWER_MODE_BATTERY_THEN_CAN)
#define POWER_MODE_STR "BATTERY_THEN_CAN"
#elif defined(CONFIG_POWER_MODE_CAN)
#define POWER_MODE_STR "CAN"
#else
#define POWER_MODE_STR "?"
#endif

#if defined(CONFIG_BATTERY_CHEMISTRY_9V)
#define BATTERY_CHEMISTRY_STR "9V"
#elif defined(CONFIG_BATTERY_CHEMISTRY_LI1S)
#define BATTERY_CHEMISTRY_STR "LI1S"
#elif defined(CONFIG_BATTERY_CHEMISTRY_LI2S)
#define BATTERY_CHEMISTRY_STR "LI2S"
#elif defined(CONFIG_BATTERY_CHEMISTRY_LI3S)
#define BATTERY_CHEMISTRY_STR "LI3S"
#else
#define BATTERY_CHEMISTRY_STR "?"
#endif

#if defined(CONFIG_PPO2_CONTROL_DEFAULT_PID)
#define COMPILE_PPO2_DEFAULT_STR "PID"
#elif defined(CONFIG_PPO2_CONTROL_DEFAULT_MK15)
#define COMPILE_PPO2_DEFAULT_STR "MK15"
#else
#define COMPILE_PPO2_DEFAULT_STR "OFF"
#endif

#if defined(CONFIG_CAL_MODE_DEFAULT_DIGITAL_REF)
#define COMPILE_CAL_DEFAULT_STR "DIGITAL_REF"
#elif defined(CONFIG_CAL_MODE_DEFAULT_ABSOLUTE)
#define COMPILE_CAL_DEFAULT_STR "ANALOG_ABS"
#elif defined(CONFIG_CAL_MODE_DEFAULT_TOTAL_ABSOLUTE)
#define COMPILE_CAL_DEFAULT_STR "TOTAL_ABS"
#elif defined(CONFIG_CAL_MODE_DEFAULT_FLUSH)
#define COMPILE_CAL_DEFAULT_STR "FLUSH"
#else
#define COMPILE_CAL_DEFAULT_STR "?"
#endif

/* ---- Runtime → string projections ---- */

static const char *ppo2_mode_name(PPO2ControlMode_t m)
{
    const char *s = "?";
    if (PPO2CONTROL_OFF == m) {
        s = "OFF";
    } else if (PPO2CONTROL_PID == m) {
        s = "PID";
    } else if (PPO2CONTROL_MK15 == m) {
        s = "MK15";
    } else {
        /* No action required */
    }
    return s;
}

static const char *cal_mode_name(CalibrationMode_t m)
{
    const char *s = "?";
    if (CAL_DIGITAL_REFERENCE == m) {
        s = "DIGITAL_REF";
    } else if (CAL_ANALOG_ABSOLUTE == m) {
        s = "ANALOG_ABS";
    } else if (CAL_TOTAL_ABSOLUTE == m) {
        s = "TOTAL_ABS";
    } else if (CAL_SOLENOID_FLUSH == m) {
        s = "FLUSH";
    } else {
        /* No action required */
    }
    return s;
}

/**
 * @brief Map a boolean feature flag to its preamble "Y"/"N" string.
 *
 * @param enabled Compile-time feature state (IS_ENABLED(...) result).
 * @return "Y" when enabled, "N" otherwise.
 */
static const char *flag_str(bool enabled)
{
    const char *result = "N";

    if (enabled) {
        result = "Y";
    }
    return result;
}

static const char *battery_type_name(BatteryType_t t)
{
    const char *s = "?";
    if (BATTERY_TYPE_9V == t) {
        s = "9V";
    } else if (BATTERY_TYPE_LI1S == t) {
        s = "LI1S";
    } else if (BATTERY_TYPE_LI2S == t) {
        s = "LI2S";
    } else if (BATTERY_TYPE_LI3S == t) {
        s = "LI3S";
    } else {
        /* No action required */
    }
    return s;
}

/**
 * @brief Format one preamble line and emit it to both RTT and the
 *        flash text FCB.
 *
 * Deferred-mode caveat: Zephyr's LOG subsystem captures `%s` argument
 * pointers at call time and dereferences them later when the
 * priority-3 logging thread processes the entry. A stack-local
 * buffer would be reclaimed by the next stack frame before the
 * logger reads it, producing garbage in the captured output (we
 * verified this on hardware — the up-buffer was full of binary noise
 * exactly where the preamble should have been). Using a `static`
 * buffer extends the lifetime past the function return; the 50 ms
 * k_msleep below guarantees the logging thread drains the entry
 * before the next call overwrites the buffer.
 *
 * Pacing: 50 ms post-line k_msleep matches
 * src/thread_analyzer_paced.c's PACED_PER_THREAD_DELAY_MS — both
 * burst ~25 LOG_INFs back-to-back; both must let the priority-3
 * logging thread drain into the (4 KB) RTT up-buffer before the
 * next line is queued. The 4 KB up-buffer (bumped from 2 KB in
 * prj.conf) is also part of the fix: it holds the boot output
 * burst when no host has attached yet so the preamble doesn't get
 * trimmed.
 *
 * Flash path: direct `flash_log_enqueue_text(LOG_LEVEL_INF, ...)`
 * captures the line even when the runtime flash-log verbosity is at
 * its default WRN. The module id "main" matches LOG_MODULE_REGISTER
 * above.
 */
__attribute__((format(printf, 1, 2)))
static void preamble_line(const char *fmt, ...)
{
    /* static — see header comment re deferred-mode pointer capture. */
    static char buf[PREAMBLE_LINE_BUF_SZ];
    va_list ap;

    va_start(ap, fmt);
    int32_t n = vsnprintk(buf, sizeof(buf), fmt, ap);
    va_end(ap);

    if (n >= 0) {
        LOG_INF("%s", buf);
        (void)k_msleep(PREAMBLE_LINE_DRAIN_MS);

#ifdef CONFIG_FLASH_LOG
        /* Guarantee capture regardless of runtime verbosity. log_source_id_get
         * returns -1 if the source isn't registered; treat that as "use 0"
         * so the entry still lands in the FCB. */
        size_t len = (size_t)n;
        if ((size_t)n >= sizeof(buf)) {
            len = sizeof(buf) - 1U;
        }
        Status_t src = log_source_id_get("main");
        if (src < 0) {
            src = 0;
        }
        flash_log_enqueue_text((uint8_t)LOG_LEVEL_INF, (uint16_t)src, buf, len);
#endif
    }
}

#ifdef CONFIG_FLASH_LOG
/** Percentage scale factor for sector-usage reporting. */
static const uint32_t PERCENT_SCALE = 100U;

static uint8_t fl_used_pct(uint16_t free_sectors, uint16_t total_sectors)
{
    uint8_t pct = 0U;

    if ((total_sectors != 0U) && (free_sectors <= total_sectors)) {
        uint16_t used = total_sectors - free_sectors;
        pct = (uint8_t)((PERCENT_SCALE * (uint32_t)used) / (uint32_t)total_sectors);
    }
    return pct;
}
#endif

/**
 * @brief Emit the boot-time identification preamble.
 *
 * Composes a multi-line preamble describing:
 *   - Firmware UID (git-describe via APP_BUILD_VERSION_STR)
 *   - Kernel version and board name
 *   - Compile-time topology (cells, power, solenoids, defaults)
 *   - Runtime NVS settings (PPO2 mode, cal mode, PID gains, battery)
 *   - Flash log occupancy and boot/dive counts
 *
 * Called once from main() after `ppo2_control_init()` so the runtime
 * settings cache is populated. Idempotent and side-effect-free apart
 * from log/flash-log writes.
 */
static void emit_startup_preamble(void)
{
    preamble_line("===== DiveCAN Boot Preamble =====");
    preamble_line("Firmware: %s", APP_BUILD_VERSION_STR);
    preamble_line("Zephyr: %s", KERNEL_VERSION_STRING);
    preamble_line("Board: %s", CONFIG_BOARD);
#ifdef CONFIG_FLASH_LOG
    preamble_line("Boot ID: %u", flash_log_get_boot_id());
#endif

    preamble_line("Cells: %d", CONFIG_CELL_COUNT);
#if CONFIG_CELL_COUNT >= 1
    preamble_line("  Cell[1]: %s", CELL_1_TYPE_STR);
#endif
#if CONFIG_CELL_COUNT >= 2
    preamble_line("  Cell[2]: %s", CELL_2_TYPE_STR);
#endif
#if CONFIG_CELL_COUNT >= 3
    preamble_line("  Cell[3]: %s", CELL_3_TYPE_STR);
#endif

    preamble_line("Power mode: %s", POWER_MODE_STR);
#ifndef CONFIG_POWER_MODE_CAN
    preamble_line("Battery chemistry (compile): %s", BATTERY_CHEMISTRY_STR);
#endif

#ifdef CONFIG_SOLENOID
    preamble_line("Solenoids: O2_inject=%d O2_inject_2=%d O2_flush=%d dil_flush=%d",
                  CONFIG_SOL_O2_INJECT_CHANNEL,
                  CONFIG_SOL_O2_INJECT_2_CHANNEL,
                  CONFIG_SOL_O2_FLUSH_CHANNEL,
                  CONFIG_SOL_DIL_FLUSH_CHANNEL);
#else
    preamble_line("Solenoids: none (solenoid driver disabled)");
#endif
    const char *o2_sol_flag = flag_str(0 != IS_ENABLED(CONFIG_HAS_O2_SOLENOID));
    const char *flush_sol_flag = flag_str(0 != IS_ENABLED(CONFIG_HAS_FLUSH_SOLENOID));
    const char *digital_cell_flag = flag_str(0 != IS_ENABLED(CONFIG_HAS_DIGITAL_CELL));
    const char *analog_cell_flag = flag_str(0 != IS_ENABLED(CONFIG_HAS_ANALOG_CELL));
    preamble_line("Has flags: o2_sol=%s flush_sol=%s digital_cell=%s analog_cell=%s",
                  o2_sol_flag, flush_sol_flag, digital_cell_flag, analog_cell_flag);

    const char *depth_comp_default_flag =
        flag_str(0 != IS_ENABLED(CONFIG_DEPTH_COMPENSATION_DEFAULT));
    preamble_line("Compile defaults: ppo2=%s cal=%s depth_comp=%s",
                  COMPILE_PPO2_DEFAULT_STR,
                  COMPILE_CAL_DEFAULT_STR,
                  depth_comp_default_flag);

    /* Runtime config snapshot from the live cache. Do NOT call
     * runtime_settings_load() here: before it became idempotent that
     * re-zeroed the cache to defaults mid-boot, re-opening a window
     * where UDS reads answered compile defaults (HIL "NVS persistence
     * broken" failures, 2026-08-01 release run). */
    RuntimeSettings_t rt = {0};
    runtime_settings_get(&rt);
    preamble_line("Runtime config:");
    preamble_line("  PPO2 mode: %s", ppo2_mode_name(rt.ppo2_control_mode));
    preamble_line("  Cal mode: %s", cal_mode_name(rt.calibration_mode));
    const char *depth_comp_flag = "N";
    if (rt.depth_compensation) {
        depth_comp_flag = "Y";
    }
    preamble_line("  Depth comp: %s", depth_comp_flag);
    preamble_line("  PID gains x1000: Kp=%d Ki=%d Kd=%d",
                  (int32_t)lroundf(rt.pid_kp * PID_GAIN_DISPLAY_SCALE),
                  (int32_t)lroundf(rt.pid_ki * PID_GAIN_DISPLAY_SCALE),
                  (int32_t)lroundf(rt.pid_kd * PID_GAIN_DISPLAY_SCALE));
    preamble_line("  Battery type: %s", battery_type_name(rt.battery_type));

#ifdef CONFIG_FLASH_LOG
    FlashLogStats_t stats = {0};
    if (0 == flash_log_stats(&stats)) {
        uint8_t tel_pct = fl_used_pct(stats.telemetry.sectors_free,
                                      stats.telemetry.sectors_total);
        uint8_t txt_pct = fl_used_pct(stats.text.sectors_free,
                                      stats.text.sectors_total);
        const uint16_t tel_used = stats.telemetry.sectors_total - stats.telemetry.sectors_free;
        const uint16_t txt_used = stats.text.sectors_total - stats.text.sectors_free;

        preamble_line("Flash log:");
        preamble_line("  Telemetry: %u/%u sectors used (%u%%) boots=%u..%u dives=%u drops=%u",
                      (uint32_t)tel_used,
                      (uint32_t)stats.telemetry.sectors_total,
                      (uint32_t)tel_pct,
                      stats.telemetry.boot_id_oldest,
                      stats.telemetry.boot_id_current,
                      (uint32_t)stats.telemetry.dive_id_latest,
                      stats.telemetry.drops_since_boot);
        preamble_line("  Text:      %u/%u sectors used (%u%%) drops=%u",
                      (uint32_t)txt_used,
                      (uint32_t)stats.text.sectors_total,
                      (uint32_t)txt_pct,
                      stats.text.drops_since_boot);
    }
#endif

    preamble_line("===== End preamble =====");
}

/**
 * @brief Application entry point; initialises hardware and blinks the heartbeat LED
 *
 * @return 0 on normal exit; negative errno if LED hardware is unavailable
 */
/* Boot phase timestamps (ms) — written once during boot, read via debugger
 * only. volatile so the stores survive optimization with no code consumer;
 * accessor-wrapped per the heartbeat.c M23_388 pattern. */
struct boot_phase_times {
    uint32_t entry_ms;
    uint32_t wdg_ms;
    uint32_t settings_ms;
    uint32_t history_ms;
    uint32_t flashlog_ms;
    uint32_t cal_ms;
};

static volatile struct boot_phase_times *boot_phase_times_get(void)
{
    static volatile struct boot_phase_times times;
    return &times;
}

/**
 * @brief Temporarily boost SYSCLK for boot-time flash operations.
 *
 * The DTS configures PLL-R=8 → 12 MHz SYSCLK for low runtime power. SPI NOR
 * throughput is limited to 6 MHz (prescaler /2), and the Zephyr SPI framework
 * overhead (~380 µs/transaction at 12 MHz) dominates the ~9 µs wire time for
 * small reads. Switching PLL-R to 2 → 48 MHz SYSCLK / 24 MHz SPI cuts per-
 * transaction overhead ~4x for the boot-path NVS and FCB scans, then we
 * restore to 12 MHz before the heartbeat loop for normal-mode power.
 *
 * The PLL output (96 MHz) is unchanged — only the R divider changes. Flash
 * wait states must be adjusted for the new HCLK (48 MHz needs 2 WS, 12 MHz
 * needs 0 WS per STM32L4 reference manual Table 9).
 */
/**
 * @brief Switch PLL-R divider and update the kernel's clock bookkeeping.
 *
 * Parks SYSCLK on HSI, reconfigures PLL-R, re-enables PLL, switches back.
 * Updates SystemCoreClock (used by clock_control_get_subsys_rate) and
 * recalibrates the SysTick so k_uptime / k_msleep stay correct.
 */
#ifdef CONFIG_SOC_FAMILY_STM32

/* HCLK targets for the two PLL-R operating points (see boost rationale above). */
#define BOOT_HCLK_BOOST_HZ   48000000U
#define RUNTIME_HCLK_HZ      12000000U

static void set_pll_r_and_recalibrate(uint32_t pllr_val, uint32_t new_hclk,
                                      uint32_t flash_latency)
{
    uint32_t key = irq_lock();

    if (new_hclk > SystemCoreClock) {
        LL_FLASH_SetLatency(flash_latency);
        while (LL_FLASH_GetLatency() != flash_latency) {
            /* Busy-wait: latency must be applied before raising HCLK. */
        }
    }

    /* Park on HSE (8 MHz, already running as PLL source) while
     * reconfiguring the PLL divider. */
    LL_RCC_SetSysClkSource(LL_RCC_SYS_CLKSOURCE_HSE);
    while (LL_RCC_GetSysClkSource() != LL_RCC_SYS_CLKSOURCE_STATUS_HSE) {
        /* Busy-wait: hardware switch completes in a few cycles. */
    }
    LL_RCC_PLL_Disable();
    while (0U != LL_RCC_PLL_IsReady()) {
        /* Busy-wait for PLL lock to drop before touching PLLCFGR. */
    }
    MODIFY_REG(RCC->PLLCFGR, RCC_PLLCFGR_PLLR_Msk, pllr_val);
    LL_RCC_PLL_EnableDomain_SYS();
    LL_RCC_PLL_Enable();
    while (0U == LL_RCC_PLL_IsReady()) {
        /* Busy-wait for PLL relock (~µs). */
    }
    LL_RCC_SetSysClkSource(LL_RCC_SYS_CLKSOURCE_PLL);
    while (LL_RCC_GetSysClkSource() != LL_RCC_SYS_CLKSOURCE_STATUS_PLL) {
        /* Busy-wait: hardware switch completes in a few cycles. */
    }

    if (new_hclk < SystemCoreClock) {
        LL_FLASH_SetLatency(flash_latency);
        while (LL_FLASH_GetLatency() != flash_latency) {
            /* Busy-wait: latency may only drop after lowering HCLK. */
        }
    }

    SystemCoreClock = new_hclk;

    irq_unlock(key);
}

static void boot_clock_boost(void)
{
    set_pll_r_and_recalibrate(LL_RCC_PLLR_DIV_2, BOOT_HCLK_BOOST_HZ,
                              LL_FLASH_LATENCY_2);
}

static void boot_clock_restore(void)
{
    set_pll_r_and_recalibrate(LL_RCC_PLLR_DIV_8, RUNTIME_HCLK_HZ,
                              LL_FLASH_LATENCY_0);
}
#else /* !CONFIG_SOC_FAMILY_STM32 (native_sim) — no PLL to switch */
static void boot_clock_boost(void)
{
}

static void boot_clock_restore(void)
{
}
#endif /* CONFIG_SOC_FAMILY_STM32 */
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

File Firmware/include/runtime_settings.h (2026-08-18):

/**
 * @file runtime_settings.h
 * @brief Runtime configuration structure persisted in NVS, changeable via UDS.
 *
 * Defines PPO2ControlMode_t, CalibrationMode_t, and RuntimeSettings_t, plus
 * load/save/validate helpers. Valid option sets are bounded by compile-time
 * Kconfig tables so only hardware-present modes are offered.
 */
#ifndef RUNTIME_SETTINGS_H
#define RUNTIME_SETTINGS_H

#include <stdint.h>
#include <stdbool.h>
#include <assert.h>
#include <zephyr/autoconf.h>
#include <zephyr/sys/util.h>
#include "common.h"
#include "oxygen_cell_types.h"

/* ---- PPO2 Control Mode ---- */

/** @brief PPO2 solenoid control algorithm selection. */
typedef enum {
    PPO2CONTROL_OFF = 0,   /**< No solenoid control */
    PPO2CONTROL_PID = 1,   /**< PID duty-cycle control */
    PPO2CONTROL_MK15 = 2,  /**< MK15-style bang-bang control */
} PPO2ControlMode_t;

static const PPO2ControlMode_t valid_ppo2_control_modes[] = {
    PPO2CONTROL_OFF,
#ifdef CONFIG_HAS_O2_SOLENOID
    PPO2CONTROL_PID,
    PPO2CONTROL_MK15,
#endif
};

#ifdef CONFIG_PPO2_CONTROL_DEFAULT_PID
#define PPO2_CONTROL_MODE_DEFAULT PPO2CONTROL_PID
#elif defined(CONFIG_PPO2_CONTROL_DEFAULT_MK15)
#define PPO2_CONTROL_MODE_DEFAULT PPO2CONTROL_MK15
#else
#define PPO2_CONTROL_MODE_DEFAULT PPO2CONTROL_OFF
#endif

/* ---- PPO2 setpoint range ----
 * The DiveCAN setpoint contract is 0.40–1.60 bar inclusive. Requests outside
 * this range (whether from a DiveCAN setpoint frame or the UDS 0xF240 write) are
 * clamped to the nearest bound, so a malformed or out-of-spec handset request can
 * never drive the loop to an unsafe (hypoxic / hyperoxic) setpoint.
 *
 * ONE deliberate exception: exactly 0.19 bar (PPO2_SETPOINT_HYPOXIC_CB) is a
 * valid discrete "diluent" setpoint for diluent-flush / hypoxic-diluent handling,
 * where the loop PPO2 legitimately sits well below the 0.40 bar floor. Selecting
 * it lowers the low-PPO2 alarm threshold to 0.16 bar (see alarm.c) so the alarm
 * does not nuisance-fire the HUD/buzzer across the diluent-PPO2 band; it still
 * fires below 0.16 bar. Only the exact value is honoured — every other
 * out-of-range request still clamps to [0.40, 1.60] — so the safety hole is as
 * small as possible. */
#define PPO2_SETPOINT_MIN_CB 40U      /* 0.40 bar */
#define PPO2_SETPOINT_MAX_CB 160U     /* 1.60 bar */
#define PPO2_SETPOINT_HYPOXIC_CB 19U  /* 0.19 bar diluent setpoint (alarm-suppressing) */

/** @brief Clamp a centibar setpoint to the valid 0.40–1.60 bar range, honouring
 *         the exact 0.19 bar hypoxic-diluent setpoint as a special exception. */
static inline PPO2_t clamp_setpoint_cb(PPO2_t setpoint_cb)
{
    PPO2_t result = setpoint_cb;

    if (setpoint_cb == PPO2_SETPOINT_HYPOXIC_CB) {
        result = (PPO2_t)PPO2_SETPOINT_HYPOXIC_CB;
    }
    else if (setpoint_cb < PPO2_SETPOINT_MIN_CB) {
        result = (PPO2_t)PPO2_SETPOINT_MIN_CB;
    }
    else if (setpoint_cb > PPO2_SETPOINT_MAX_CB) {
        result = (PPO2_t)PPO2_SETPOINT_MAX_CB;
    }
    else
    {
        /* No action required */
    }

    return result;
}

/* ---- Calibration Mode ----
 * The enum values themselves live in `oxygen_cell_types.h` as `CalMethod_t`
 * (the wire-format type carried in CalRequest_t).  CalibrationMode_t here
 * is a thin alias so the runtime-settings API still reads naturally
 * (`settings.calibration_mode`) while the four enumerator names
 * (CAL_DIGITAL_REFERENCE, …) have a single source of truth.  Without this
 * alias, including both headers in the same TU was a duplicate-enumerator
 * compile error. */

typedef CalMethod_t CalibrationMode_t;

static const CalibrationMode_t valid_cal_modes[] = {
#ifdef CONFIG_HAS_DIGITAL_CELL
    CAL_DIGITAL_REFERENCE,
#endif
    CAL_ANALOG_ABSOLUTE,
    CAL_TOTAL_ABSOLUTE,
#if defined(CONFIG_HAS_FLUSH_SOLENOID) || defined(CONFIG_HAS_O2_SOLENOID)
    /* Flush cal works with EITHER a dedicated flush solenoid OR the O2 inject
     * solenoid — cal_solenoid_flush() falls back to sol_o2_inject_fire() when
     * there is no flush solenoid (same procedure, just a slower O2 flush). So
     * FLUSH is valid whenever the unit can dose O2. */
    CAL_SOLENOID_FLUSH,
#endif
#if defined(CONFIG_HAS_FLUSH_SOLENOID) && defined(CONFIG_HAS_DIL_FLUSH_SOLENOID)
    /* CHECK needs BOTH an O2 flush and a diluent flush solenoid so it can
     * drive the cells high (O2) then low (diluent). Currently Poseidon_Aren
     * only. It never recalibrates; it is the default on all-digital heads
     * (Poseidon) where there is no analog coefficient to compute. */
    CAL_CHECK,
#endif
};

#ifdef CONFIG_CAL_MODE_DEFAULT_DIGITAL_REF
#define CAL_MODE_DEFAULT CAL_DIGITAL_REFERENCE
#elif defined(CONFIG_CAL_MODE_DEFAULT_ABSOLUTE)
#define CAL_MODE_DEFAULT CAL_ANALOG_ABSOLUTE
#elif defined(CONFIG_CAL_MODE_DEFAULT_TOTAL_ABSOLUTE)
#define CAL_MODE_DEFAULT CAL_TOTAL_ABSOLUTE
#elif defined(CONFIG_CAL_MODE_DEFAULT_CHECK)
#define CAL_MODE_DEFAULT CAL_CHECK
#else
#define CAL_MODE_DEFAULT CAL_SOLENOID_FLUSH
#endif
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

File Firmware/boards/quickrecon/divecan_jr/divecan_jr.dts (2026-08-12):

/dts-v1/;
#include <st/l4/stm32l431Xc.dtsi>
#include <st/l4/stm32l431r(b-c)tx-pinctrl.dtsi>
#include <zephyr/dt-bindings/adc/adc.h>

/ {
	model = "QuickRecon DiveCAN Jr";
	compatible = "quickrecon,divecan-jr";

	chosen {
		zephyr,sram = &sram0;
		zephyr,flash = &flash0;
		zephyr,code-partition = &slot0_partition;
		zephyr,canbus = &can1;
	};

	aliases {
		led0 = &led_0;
		led1 = &led_5;
		watchdog0 = &iwdg;
		/* MCUBoot uses this LED during boot/swap operations
		 * (CONFIG_MCUBOOT_INDICATION_LED). Once MCUBoot jumps
		 * into the app, the heartbeat thread takes the LED back
		 * via the led0 alias. */
		mcuboot-led0 = &led_0;
	};

	leds {
		compatible = "gpio-leds";
		led_0: led_0 {
			gpios = <&gpiob 0 GPIO_ACTIVE_HIGH>;
		};
		led_5: led_5 {
			gpios = <&gpiob 12 GPIO_ACTIVE_HIGH>;
		};
	};

	/* Hardware version detection — halts with blink code on mismatch.
	 * JR2: all three pins wired to ground → expected [0, 0, 0] */
	hw_version: hw-version {
		compatible = "quickrecon,hw-version";
		detect-gpios = <&gpioc 0 GPIO_ACTIVE_HIGH>,
			       <&gpioc 9 GPIO_ACTIVE_HIGH>,
			       <&gpioc 10 GPIO_ACTIVE_HIGH>;
		expected-pattern = <0 0 0>;
		error-led-gpios = <&gpiob 0 GPIO_ACTIVE_HIGH>;
	};

	solenoids: solenoids {
		compatible = "quickrecon,solenoid-driver";
		gpios = <&gpiob 4 GPIO_ACTIVE_HIGH>,
			<&gpioc 11 GPIO_ACTIVE_HIGH>,
			<&gpiob 5 GPIO_ACTIVE_HIGH>,
			<&gpioa 7 GPIO_ACTIVE_HIGH>;
		counter = <&sol_timer>;
		/* 5.5 s deadman — safety bound on solenoid on-time if the
		 * fire-thread stalls. Sized to comfortably exceed the PPO2
		 * PID controller's 4.9 s per-cycle on-time (PPO2Control.c
		 * legacy SOLENOID_MAX_FIRE_MS). See COMPROMISE.md. */
		max-on-time-us = <5500000>;
	};

	/* ---- Power subsystem ----
	 * Jr: single battery source, VBUS on/off only.
	 * battery_en (PA1) controls the VBUS regulator.
	 * Battery voltage sensed on ADC1 channel 4 (PC3) through 7.25x divider.
	 * VCC monitored via internal VBAT sensor (shared regulator with VBUS).
	 */
	vbus_reg: vbus-regulator {
		compatible = "regulator-fixed";
		regulator-name = "vbus";
		enable-gpios = <&gpioa 1 GPIO_ACTIVE_HIGH>;
		regulator-boot-on;
		startup-delay-us = <5000>;
	};

	power: power-subsystem {
		compatible = "quickrecon,power-subsystem";
		vbus-supply = <&vbus_reg>;
		battery-sense-io-channels = <&adc1 4>;
		battery-divider-ratio = <7250>;
		/* On Jr, VCC == VBUS (shared regulator). Read it via the
		 * STM32 internal VBAT sensor, which owns ADC channel 18 and
		 * applies the chip's internal 1/3 divider. */
		vcc-sense = <&vbat>;
		/* Shared active-low enable/wake line. Firmware samples it as an
		 * input after WKUP2 wake, then holds it low until shutdown. */
		can-enable-gpios = <&gpioc 13 GPIO_ACTIVE_LOW>;
		can-shutdown-gpios = <&gpioc 14 GPIO_ACTIVE_HIGH>;
		/* CAN transceiver silent/Rs line. Driven low (normal mode) at
		 * init; asserted high (silent) going into shutdown. Owned as an
		 * output — not a passive input — so a warm start reliably clears
		 * silent mode. See power_management.c. */
		can-silent-gpios = <&gpioc 15 GPIO_ACTIVE_HIGH>;
	};
};

/* ---- Clock tree ----
 * Matches Rev2 for low power: HSE=8MHz, PLL N=12 R=8 → 12MHz SYSCLK
 * PLL Q=4 → 24MHz for CLK48 (RNG clock source)
 */
&clk_hse {
	clock-frequency = <DT_FREQ_M(8)>;
	status = "okay";
};


&pll {
	div-m = <1>;
	mul-n = <12>;
	div-q = <4>;
	div-r = <8>;
	clocks = <&clk_hse>;
	status = "okay";
};

&rcc {
	clocks = <&pll>;
	clock-frequency = <DT_FREQ_M(12)>;
	ahb-prescaler = <1>;
	apb1-prescaler = <1>;
	apb2-prescaler = <1>;
};

/* ---- Kernel timebase: LPTIM1 on LSI (32 kHz) ----
 * Decouples kernel timing from SYSCLK so main() can boost HCLK 12→48 MHz for
 * the boot-path flash scans and restore it afterwards (SysTick, by contrast,
 * counts HCLK — a runtime clock switch under it storms the tickless kernel).
 * LSI is ±5%-ish; per-test timing tolerances absorb that. Tick rate becomes
 * 4000/s via the SoC defconfig. */
&clk_lsi {
	status = "okay";
};

stm32_lp_tick_source: &lptim1 {
	clocks = <&rcc STM32_CLOCK(APB1, 31)>,
		 <&rcc STM32_SRC_LSI LPTIM1_SEL(1)>;
	status = "okay";
};

/* CONFIG_PM is required by the LPTIM timer driver, but this rig/product must
 * NOT enter STOP modes on idle: STOP kills SWD attach (rig flash/debug
 * discipline) and gates the CAN peripheral (dropped DiveCAN frames while
 * idle). Deleting the SoC-provided states leaves the PM policy with nothing
 * to choose, so idle remains plain WFI exactly as before. */
&cpu0 {
	/delete-property/ cpu-power-states;
};

/* ---- CAN bus — DiveCAN @ 125 kbit/s ----
 * Jr at 80 MHz: prescaler and segments are derived from the Zephyr bitrate and
 * sample-point properties below.
 */
&can1 {
	pinctrl-0 = <&can1_rx_pb8 &can1_tx_pb9>;
	pinctrl-names = "default";
	bitrate = <125000>;	/* DiveCAN bus is 125 kbit/s (was erroneously 250000) */
	sample-point = <875>;
	status = "okay";
};
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

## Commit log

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2023-10-15 Respin to use internal oscillator
    [main.c]
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2023-11-23 Add a WDT and pin down the weird crashing to I2C deadlocking
    [main.c]
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2023-12-21 Fix Divecan device spec not working
    [main.c]
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2023-12-23 Add error handling stubs, and start dotting them around as needed
    [errors.c, errors.h]
2023-12-24 Do a bunch more error checking
    [errors.c, errors.h]
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2023-12-27 Set analog pins to analog mode, update jobs with hardware issues
    [main.c]
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2023-12-31 Fix phantom power being provided over UART to the solid state cell
2024-01-07 Explictly number errors for easy referencing of error codes
    [errors.h]
2024-01-07 Add read/write of errors to the flash API
    [errors.h]
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2024-01-07 Replace extern with inclusion of the print header
    [errors.c, main.c]
2024-01-07 Map the fatal errors to the handler function
    [errors.h, main.c]
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2024-01-08 Swap 10k led resistors for 5.1k resistors
    [DiveCAN Head2.kicad_sch]
2024-01-08 Correct 10k resistors to correct MPN, adjust resistor values on O2 cell terminations, adjust analog voltage divider ratio
    [DiveCAN Head2.kicad_sch]
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2024-01-13 Add pulldown fet on battery enable pin, preserve power during uC reset
    [DiveCAN Head2.kicad_sch]
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2024-01-13 Fix ERC issues
    [DiveCAN Head2.kicad_sch, SolenoidDriver.kicad_sch]
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2024-02-29 Fix typos in silkscreen
    [DiveCAN Head2.kicad_pcb]
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2024-03-01 Set errors in eeprom
    [errors.c]
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2024-03-01 Run pins in reset for power efficiency
    [main.c]
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2024-04-07 fix the can setup script to reflect how to actually set up the canbus
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2024-04-20 Tweak the calibration logic to give errors on out of range values (WIP)
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2024-04-26 Implement serial logging of printf messages, fix regression of CAN rx
    [errors.h, main.c]
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2024-04-27 Fix osTerminate not working, fix some str func checking, justify some static badness
    [main.c]
2024-04-28 Fix logging during a crash, add RTOS instrumentation
    [errors.c, main.c]
2024-04-28 Remove flash non-fatal error storage (we have the SD card now, and flash operations aren't well behaved in the stack allocation)
    [errors.c]
2024-04-29 Whole bunch of random bullshit trying to track down why we're getting random crashes while logging Digital cells
    [errors.c, main.c]
2024-05-01 continue trying and failing to fix the sd logging crash
    [main.c]
2024-05-01 Move processor memory pool into shared mem-space, rearrange task priority to prevent crashes (order can still be optimised)
    [errors.h, main.c]
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2024-05-08 Add printing of reset reason
    [main.c]
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2024-05-16 Note and fix swapped RX and TX pins
    [main.c]
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2024-05-23 Stomp the calibration on config change to prevent "laundering" of dodgy calibrations
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2024-08-07 Implement low battery alarm, also fix power off behavior for HUD
    [configuration.h]
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2024-10-20 Sonar pass, clean up internal ADC error handling
    [errors.h]
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2024-12-15 Enable gcc analyser and fix associated warnings
    [configuration.h]
2024-12-29 Do some in depth linting/static analysis fixing
    [main.c]
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2025-01-06 Fix CAN timing after clock change
    [main.c]
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2025-01-15 Get rid of the classless power controls because they don't preserve state correctly on the PPK2
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2025-03-21 decrease FS timeout, add some brownout detection to the micro that trips when our regulator browns out
    [main.c]
2025-03-21 Fix some sonar warnings
    [main.c]
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2025-03-30 Try to get HW shim to emulate o2s sensors better (not working)
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2025-05-28 Rename nonfatal error codes to be consistent
    [errors.h, main.c]
2025-05-28 Change ADC errors from critical errors to internal adc errors
    [main.c]
2025-05-28 Update fatal error codes to be consistent
    [errors.h, main.c]
2025-05-28 Add last fatal error to the logs
    [main.c]
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2025-05-31 Add better tools for runtime corruption and errors detectio
    [errors.h]
2025-05-31 Increase the level of detail included in error messages by including the relevant program state
    [main.c]
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2025-09-13 Fix solenoid power distribution to prevent brownouts
    [configuration.h]
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2025-11-16 Add new voting tests to catch an error case when one cell is very far away from the rest
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2025-11-17 Add check to see if the bus is actually on once we've booted up, to prevent spurious power-ons
    [main.c]
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2025-12-09 Ensure we keep tripping the solenoid on to prevent it getting switched off by the PID loop
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2025-12-15 Reset default config to jr
    [configuration.h]
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2026-01-29 Fix menu offset issues,
    [uds.c]
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2026-01-29 Fix low battery alarm to work correctly based on new spec data
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2026-01-30 Fix error case duplication
    [errors.h]
2026-01-30 Add a bunch of error handling
    [errors.h, uds.c]
2026-01-30 Code cleanup pass, fix rentrant logging bug
    [uds.c]
2026-02-19 Add some more cell error cases, and update flashing firmware docs
    [errors.h]
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2026-05-11 Set up error handling
    [errors.c, errors.h]
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2026-05-13 Add histogram for errors and expose cell data over DIDs
    [main.c, oxygen_cell_types.h, uds.c]
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2026-06-23 Add enhanced error checkin in the HAL
    [calibration.c, errors.c, errors.h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]
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2026-06-24 Fix large flash issue
    [Jr DiveCANHead.kicad_pcb]
2026-06-25 Flash fix for flogging on filled startup
    [flash_log.c]
2026-06-25 Use correct cal mode when requested
    [divecan_jr.dts, runtime_settings.h, uds.c]
2026-06-25 Fix 3 vs 4 byte addressing
    [main.c]
2026-06-25 Fix cal requirements for flush and add UDS mass erase
    [main.c, runtime_settings.h, uds.c]
2026-06-25 Fix crash on calibrate due to OOM
    [calibration.c, errors.c, errors.h]
2026-06-25 Fix UDS temp overrides not taking effect
    [runtime_settings.h]
2026-06-26 Fix cell 2 not sharing ADC correctly under zephyr
    [divecan_jr.dts, main.c]
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2026-06-26 Fixes arising from test cases
    [runtime_settings.h, uds.c]
2026-06-27 Fix bugs in OTA pathway
    [firmware_confirm.c, main.c]
2026-06-27 Strip unused diagnostics, fix log, fix some sad counters
    [firmware_confirm.c, flash_log.c, main.c]
2026-06-27 Fix ADC driver to serialise properly
    [divecan_jr.dts]
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2026-06-29 Fix flakyness in isotp subsystem
    [divecan_jr.dts, main.c, runtime_settings.h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]
2026-06-30 Fixs from doing a full variant coverage campaign
    [uds.c]
2026-07-01 Ensure zbus reads are getted and result checked correctly
    [errors.c, main.c, uds.c]
2026-07-02 Fix flash log behavior to deal with cache staleness
    [flash_log.c]
2026-07-02 Fix rounding in PPO2 values
    [main.c]
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2026-07-03 Fix can silent stuck after reboot
    [divecan_jr.dts]
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2026-07-03 Fix bus locking and add proper shutdown/starup sequencing
    [divecan_jr.dts]
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2026-07-06 Fix off by 1 error in logs, make I2C more robust against multimaster clashes, make UDS more robust
2026-07-06 Fix isoTP session addressing so bus devices work after bluetooth interaction
    [main.c]
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2026-07-09 Pause error-histogram NVS save during OTA
    The periodic error-histogram save (5-minute timer) schedules its work on
    the system workqueue, where the settings -> NVS -> flash_area_write ->
    spi_nor -> spi_stm32 chain runs. During a large OTA the upload lasts long
    enough to straddle a save tick; the deep write then lands on the 1024 B
    system-workqueue stack while contending with the OTA writer on the same
    SPI-NOR, overflowing it and tripping K_ERR_STACK_CHK_FAIL (observed on
    Poseidon hardware as a mid-upload crash/reboot, thread=k_sys_work_q).
    flash_log and the broadcast log-push were already suspended for the OTA
    window; the error-histogram save was the one remaining background writer
    that coul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
    [main.c]
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2026-07-09 Replace out of stock MPN
    [DiveCAN Head2.kicad_pcb, Jr DiveCANHead.kicad_pcb, Jr DiveCANHead.kicad_sch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]
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2026-07-10 Add solenoid errors on current mismatch
    [main.c, solenoid.c]
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2026-07-12 Proposed fixes for PID tuning
    [main.c, ppo2_autotune.h, uds.c]
2026-07-13 Fix I2C crash, reinforce some flash management
    [factory_image.c, uds.c]
2026-07-15 Autotuning and facotry image restore fixes
    [factory_image.c, main.c, ppo2_autotune.h]
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2026-07-27 Fix all 91 SonarQube BUG-type issues on PR 4 (reliability gate)
    - S853: explicit casts on <</~ results (flash_log, factory_image, uds,
    uds_ota, uds_log_download, poseidon_accessories, divecan_tx, tests)
    - S874: unsigned operands for bitwise ops (poseidon_accessories rc
    accumulators, flash_log, firmware_confirm/divecan_tx tests)
    - S867: explicit bool comparisons, no bitwise on bool
    - S1226: locals instead of parameter reassignment (incl. solenoid
    arm_timer clamp now correctly fed to counter_us_to_ticks)
    - S966/M23_045: #if defined() guards for CONFIG_SOL_O2_INJECT_2_CHANNEL /
    CONFIG_*_TRANSDUCER_CHANNEL — an undefined int Kconfig symbol would
    previously have evaluated 0>=0 and sil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
    [factory_image.c, flash_log.c, main.c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]
2026-07-27 Clear residual gate-blockers from first sonar pass
    - flash_log_smoke: drop boolean-literal comparisons the S867 fix introduced
    - isotp test: complete the S853 cast on the FF length shift
    - wcs.py: contain the manual-overrides (.msu) path to repo/cwd (S8707) —
    the file ships with the repo, so out-of-tree resolution is a mangled arg
    [main.c]
2026-07-27 SonarQube maintainability sweep: src/, drivers/, include/, DiveCAN_bt
    Batch 3 of the PR 4 quality-gate cleanup (~700 issues addressed across
    40+ files by parallel review agents, centrally verified):
    - S109: magic numbers -> named constants (~100 sites)
    - S813/M23_058: raw builtin types -> Status_t/Numeric_t/explicit-width
    (~130 sites; Zephyr API contract sites left as int and documented)
    - S1005/S1142: single-return restructures (~45 functions)
    - S1774/S3358: ternaries -> if/else (~40)
    - M23_007: (void) casts on real functions only (k_msleep, memset,
    flash_area_close where non-void); LOG_*/ARG_UNUSED left (analyzer FPs)
    - S1151: long switch cases -> extracted helpers (18, incl. shared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
    [calibration.c, errors.c, errors.h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]
2026-07-27 Add CI-based SonarCloud analysis with real compilation database
    GitHub Actions workflow builds the Poseidon_Aren ARM firmware (sysbuild)
    plus all native_sim test modules, merges their compile_commands.json
    (ARM entries win for src/ so production code is analyzed under the
    shipped config), and runs the SonarCloud scanner against it. This
    replaces Automatic Analysis, whose macro-blind C parsing produced
    ~2,800 false positives on Zephyr macros (ZTEST, zassert_*, ARG_UNUSED,
    LOG_*) across S1198/S813/M23_007.
    sonar-project.properties gains the compile-commands pointer, build-dir
    exclusions, and UTF-8 encoding. Legacy STM32/** stays listed but its C
    files are skipped automatically (no DB entries)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
2026-07-27 Use <zephyr/autoconf.h> instead of legacy bare include path
    Zephyr main removed the legacy generated-include compat path, so the
    bare <autoconf.h> spelling (present since the initial rewrite commit)
    fails on the CI checkout while still resolving on older local trees.
    The zephyr/-prefixed form works on both.
    [runtime_settings.h]
2026-07-27 Pin zephyr to the bench-validated revision (v4.4.0-2182)
    revision: main let CI float ~200 commits ahead of the local checkout,
    which already surfaced one incompatibility (legacy autoconf.h include
    path removal). Pin to the exact commit local builds and HIL testing run
    against; bump deliberately alongside a local update + full test pass.
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2026-07-27 Fix compile-DB-era SonarQube bugs: null-guard hardening, signed bitwise, config guards, param reuse
    The CI compilation-database analysis (macro-aware) surfaced a new bug
    set; all code-level findings fixed:
    - S2259: factory_image backend helpers now check backend != NULL locally
    (-ENODEV) instead of relying on caller guards the analyzer (and future
    callers) cannot see
    - S3519: explicit bounds guards in flash_log_reader drain() helper and
    test_shim_uart extract_command (dst_size==0 underflow) — the ads1x1x
    CONTAINER_OF blockers are analyzer FPs, accepted + documented in
    SONARQUBE_ACCEPTED_ISSUES.md
    - S966/M23_045: defined() guards on CONFIG_CELL_COUNT preprocessor tests
    (oxygen_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
    [factory_image.c, gpio_sim.c, main.c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]
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2026-07-27 Fix the two long-failing native test suites (test defects, not firmware)
    factory_image.test_restore_copies_backend_to_slot1_and_reboots: the test
    predated the 2fb93e9 restore redesign — it seeded an unparseable 0xCC
    mock backend and asserted a full-slot byte match. The HIL-validated
    contract is image-only copy with the trailer region left erased. Test
    now builds a minimal valid MCUBoot image (header + body + TLV info),
    wraps mcuboot_swap_type to report the staged TEST swap, and asserts
    [0, image_size) mirrors the backend with the remainder 0xFF. 15/15.
    ads1x1x_multichannel hang/flake: the test's struct adc_sequence was
    uninitialized; adc_sequence_init_dt() leaves .options/.calibrate
    untou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
    [main.c]
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2026-07-27 Half finished code issues fix
    [calibration.c, errors.c, factory_image.c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]
2026-07-27 Exercise factory image recovery failures
    [main.c]
2026-07-27 Stabilize integration and calibration ownership
    [calibration.c]
2026-07-27 Cover OTA failure handling
    [main.c]
2026-07-27 Cover runtime settings failure paths
    [main.c]
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2026-07-28 Final SonarQube residue: 38 fixes, snake_case field renames, exec bits
    Residue triage (38 fixes across 16 files): S851 widening via
    fl_entry_data_off() helper and (off_t) splits, M23_321 init-at-decl,
    S868 parens, S6871 full struct inits, S845 atomic_val_t casts, S813
    header/impl Status_t consistency (error_histogram.h, flash_mass_erase.h),
    S954/M23_039 include hoist in tank_pressure.h, JS clipboard catch now
    logs. All 10 S5816 strncpy sites audited safe (documented evidence).
    S116 rename pass: 74 findings, 63 camelCase field tokens renamed to
    snake_case across 35 files (ISOTPContext_t, UDSContext_t, OtaSmCtx_t,
    RuntimeSettings_t, PIDState_t, wire structs incl. __packed layouts —
    layout-s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
    [factory_image.c, firmware_confirm.c, flash_log.c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]
2026-07-28 Clear the last five PR 4 findings (S1854 dead stores, S851)
    The preamble Y/N flag locals initialized "N" then unconditionally
    overwrote it in the analyzed config — replaced with a flag_str() helper
    so the value flows through a single initialization. heartbeat_register's
    S845-mandated cast moves to a named temp so S851 no longer sees a cast
    on a composite expression.
    [main.c]
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2026-07-29 Fix issue with crash log causing HIL failure
    [calibration.c, errors.c, errors.h]
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2026-08-03 Fix calibration loading dependency chain and testing
    [calibration.c]
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2026-08-05 Halve the flash-log batch staging buffer to restore RAM headroom
    Poseidon_Aren linked at 100.00% of the 64 KB RAM region. Because
    CONFIG_COMMON_LIBC_MALLOC_ARENA_SIZE is -1 ("all leftover RAM"), a variant
    that fills RAM exactly leaves a zero-byte arena, and malloc_prepare's
    sys_heap_init(size=0) asserts -> k_panic -> a silent pre-banner reboot loop
    with no log output. mbedtls reaches calloc through the mbedtls_calloc_func
    pointer when PSA SHA-256 seeds HMAC-DRBG for OTA image validation, so the
    arena genuinely must be non-empty.
    fl_batch_buf is a staging buffer only, so trimming it costs write batching
    and never data: a full buffer flushes early via fl_batch_append()'s bounds
    check, so the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
    [flash_log.c]
2026-08-05 Arm the application IWDG window before any boot-path flash work
    Poseidon_Aren reset-looped every ~8 s with no application output at all: ten
    MCUBoot banners in 70 s, and not even "*** Booting Zephyr OS ***".
    MCUBoot arms the IWDG at CONFIG_BOOT_WATCHDOG_TIMEOUT_MS (8000) and that
    programming survives the chainload — the L4 IWDG sits outside the RCC reset
    domain and cannot be disabled, only re-programmed or fed. main() then spends
    far longer than 8 s in synchronous, non-yielding SPI against the external NOR
    before it ever reaches wdt_setup(): runtime_settings_load()'s NVS walk alone
    measures 3.5 s (nvs_prev_ate reads 8 bytes per SPI transaction and the cost
    grows as the settings partition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
    [main.c]
2026-08-05 Self-heal drifted option bytes and raise the brown-out level to ~2.0 V
    Parts ship with BOR_LEV=0, whose falling threshold (~1.66 V typ) sits BELOW the
    STM32L4's 1.71 V minimum operating voltage, so the core can execute below spec
    without ever being reset. That is the condition under which an in-flight flash
    write can be left half-completed, and there is no recovery from a corrupt
    slot0: MCUBoot only consults the secondary slot when the trailer requests a
    swap or revert, and CONFIG_BOOT_BOOTSTRAP is not set, so the unit needs an SWD
    reflash. A flat 1S cell under solenoid load is a slow decay through exactly
    that window, in the field.
    Assert and self-heal BOR_LEV=1 (~2.0 V) — the lowest set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
    [main.c]
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2026-08-07 Bulk-read FCB active sector at boot and toggle LED between init phases
    The FCB active-sector walk in fcb_init does two tiny SPI reads per
    entry (~3 bytes each). At 12 MHz SYSCLK / 6 MHz SPI, the Zephyr SPI
    framework overhead (~380 µs/transaction for semaphores, GPIO CS, and
    byte-by-byte polling) dwarfs the 9 µs wire time. A text FCB sector
    with ~1000 log entries took 763 ms to walk.
    Add FCB_FLAGS_INIT_SKIP_WALK (Zephyr patch) to skip the per-entry
    walk in fcb_init. flash_log.c then seeks the write cursor by reading
    the active sector in FL_BATCH_BUF_BYTES (2048) chunks into fl_batch_buf
    (idle during init, repurposed for write batching after init) and
    parsing entry headers in RAM. This cuts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
    [flash_log.c, main.c]
2026-08-07 Fix FCB fast-seek cursor and SonarQube cast warning
    The bulk-read seek could stop short at a chunk boundary, leaving
    f_active.fe_elem_off before the true end of entries. fcb_append then
    overwrote the tail entries — including the boot marker — causing the
    log selector to return NRC 0x22 (conditionsNotCorrect / ENOENT).
    Add a validation pass after the bulk read: walk from the bulk cursor
    using the public fcb_getnext API to catch any remaining entries.
    On a correct bulk parse this does 1-2 SPI reads confirming erased
    flash; on an early stop it picks up the tail. The write cursor is
    always authoritative.
    Also fix SonarQube S853 (MISRA): explicitly cast the shift result in
    the 2-byte length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
    [flash_log.c]
2026-08-07 Remove unbounded FCB validation walk; fix bulk-parse chunk continuation
    The post-bulk-seek validation loop (fcb_getnext per entry) was the O(N)
    per-entry SPI walk the fast-seek exists to avoid, and it mutated
    f_active.fe_elem_off (the loop's own exit-condition anchor) while
    iterating. On a populated ring it ran past the 32 s IWDG window,
    producing a boot-reset loop (~30 s+ apparent boots, then a torn sector
    that triggered the 48 MB recovery erase).
    The validation was compensating for a bulk-parser bug: the outer loop
    treated any partial chunk (an entry spanning the chunk boundary) as
    end-of-scan. Fix the parser instead — re-read the next chunk starting
    at the spanning entry, and only stop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
    [flash_log.c]
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2026-08-07 Fix bulk FCB parser losing chunk progress at the terminator
    Two cursor defects in fl_fast_seek_active, found by a differential
    build publishing the bulk cursor alongside a stock fcb_getnext probe
    walk on the same ring:
    1. The erased-terminator path (0xFF 0xFF) jumped to done without
    adding the entries already parsed in the current chunk — the cursor
    was left at the CHUNK START, up to 2 KiB short. Every subsequent
    append landed mid-stream, corrupting the chain the (stock-walking)
    reader traverses: the boot marker became unreachable and every log
    selector returned NRC 0x22. The removed validation loop had been
    masking exactly this.
    2. A decoded length extending past the c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
    [flash_log.c]
2026-08-07 Guard boot clock boost behind CONFIG_SOC_FAMILY_STM32
    The stm32_ll_* includes and PLL reconfiguration broke every native_sim
    build (CI coverage natives compile src/main.c): fatal error
    'stm32_ll_rcc.h' file not found. Same guard pattern power_management.c
    uses for its HAL shutdown path; boost/restore are no-ops on native.
    Claude-Session: https://claude.ai/code/session_01Mbpu1ZT5rK4kNLgETVvwHb
    [main.c]
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2026-08-09 Resolve SonarCloud new-code issues from the boot-time and robustness work
    164 new-code issues dispositioned: ~135 fixed, 17 documented per-issue
    acceptances (docs/SONARQUBE_ACCEPTED_ISSUES.md, dated section), the rest
    were duplicate rule pairs on the same lines.
    Mechanical: S867 bool-operand bug in the clock-boost busy-waits (plus
    comments in each empty wait body), named constants for the HCLK targets and
    FCB entry-length encoding, parenthesised complex operands, width-explicit
    typedefs (Status_t for Zephyr rcs — int32_t is long int on arm-zephyr-eabi
    and breaks framework function-pointer tables, so API-contract signatures
    keep int), (void)k_msleep, pointer-to-const, immediate local init,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
    [errors.c, factory_image.c]
2026-08-10 Clean up the four fixable stragglers from the Sonar re-scan
    Post-79e0e2b scan: 164 -> 35 new-code issues. Of the 35, 31 are the
    documented acceptance classes (including 12 fresh M23_233 on the inner
    statics of accessors introduced FOR M23_388 — acceptance row generalized to
    cover the pattern rather than a location list). The four real ones fixed
    here: immediate-init on the chunk-scan struct / reader chunk result /
    program-entry rc, single-return in fl_batch_write_container, and the
    fl_resolve_sem/lock accessors now use Z_SEM_INITIALIZER/Z_MUTEX_INITIALIZER
    directly — K_SEM_DEFINE's section-iterable expansion leaves a dangling empty
    statement at function scope (S1116) and section registra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
    [flash_log.c]
2026-08-10 Extract batch Pass B so the container writer stays under the complexity bar
    970a306's single-return reshape of fl_batch_write_container traded a MINOR
    S1005 for a CRITICAL S3776 (27>25) and an S134 depth-5 nest — the else-wrap
    pushed every inner block one level deeper. Moving the Pass B sub-record loop
    into fl_batch_write_subrecords() resolves all three shapes at once: the
    container function is acquire/reserve/header/delegate/finish, the loop
    helper is flat, and behavior is unchanged (the loop only ever ran with
    rc==0, which is now its precondition). flash_log_writer 25/25, Poseidon
    build clean.
    Claude-Session: https://claude.ai/code/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
    [flash_log.c]
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2026-08-10 Change tank pressures to supress broadcasts rather than broadcast an error sentinal
    [main.c]
2026-08-12 Add assertions of bus line to prevent spurious poweron but also correctly start the world on power-applied or other startup events
    [divecan_jr.dts, main.c]
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2026-08-17 Ensure long running flash tasks reserve the extended flash area, and that reserving that area blocks the error histogram write (contention issue)
    [factory_image.c, main.c, uds.c]
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2026-08-20 Fix battery monitor stack overflow from power snapshot logging
    The periodic power snapshot added with the pressure/power logging channels
    runs on the battery monitor thread and nests FlashLogPowerSnapshot_t ->
    fl_payload_power_snapshot_t -> LogIngestSlot_t (96 B) on that stack, about
    180 B of new depth. That stack was 512 B and already had no margin (384 B
    previously tripped K_ERR_STACK_CHK_FAIL), so every sample interval ran into
    the MPU stack guard and rebooted the head.
    The reboot loop presents as pervasive UDS timeouts rather than an obvious
    crash: on-rig, test_01_dut_configuration went 15F/10P and the module pair
    took 9m50s, against 28 passed in 55s on the parent commit. Raising the st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
    [main.c]
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
